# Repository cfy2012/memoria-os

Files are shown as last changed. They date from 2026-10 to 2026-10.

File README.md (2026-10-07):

# Memoria OS

**Memoria OS v1.3.0** 是一款基于 ESP32-S3（N16R8：16 MB Flash + 8 MB Octal PSRAM）自主设计的掌机操作系统。系统内核、窗口系统、文件系统、脚本引擎、BASIC 解释器与应用商店均为从零自研，不依赖 Linux、LVGL 或任何现成 UI 框架。项目以开源复古计算与嵌入式系统学习为定位，面向希望理解完整嵌入式系统栈的开发者。

## 项目定位

Memoria OS 在单颗 ESP32-S3 上实现了一台完整的手持计算设备：开机进入图标桌面，通过功能键与摇杆在十一种内置模式间切换；用户可在设备内直接编写 BASIC 程序或 `.ms` 脚本并立即运行；同时支持音频/视频/图片播放、应用商店下载安装、语音录制收发与 OTA 固件升级。

系统不使用外部操作系统，所有任务调度建立在 FreeRTOS 原语之上，所有界面绘制由自研窗口栈完成。

## 应用开发（软件的本质）

Memoria OS 上的"软件"统一为 **`.msp` 应用包**——50 字节头（魔数 MSPACK、包名、版本、CRC32）加 payload。商店只认 `.msp`，不允许裸 `.bas` / `.c` 文件直下。v1.3.0 起应用包支持 **MBND 解包安装**：包内可携带 `app.bas`（BASIC 源码）、`manifest.json`（元信息）与任意资源文件，商店安装时自动展开落盘、卸载时连带清理。

```
BASIC 源码（.bas 文本）
  → PC 端应用打包工作台（tools/msp-packer）生成 .msp
  → 上架 manifest.json（软件源清单）
  → STORE 商店安装（.msp 单文件包直接运行 / MBND 包解包落盘）
  → PRGM 模式解释运行
```

完整语法、屏幕绘图、GUI 控件与硬件扩展 API（WiFi / GPIO / 串口 / 蓝牙）见 **`docs/BASIC-LANGUAGE.md`**（Memoria BASIC 语言手册）与 **`docs/BASIC-BOOK.md`**（语言教材）。

## 功能特性

- **内置模式**：PHOTO、MUSIC、VIDEO、CLOCK、NOTES、CALC、PRGM、STORE、SETUP、FMEM、SYS 共十一种，通过 F1~F6 功能键与摇杆导航切换；桌面图标网格分页展示，最后一行下滑自动翻页。
- **键盘输入**：6×10 键矩阵，由两片 MCP23017（I2C 地址 0x20 / 0x21）扫描，支持 Shift 双层键位与拼音输入法（F1~F4 选字 / Ctrl+Shift 中英切换）。
- **GUI 控件语句（v1.3.0 新增）**：`bkey`（按钮按下）、`lbl`/`llbl`/`lbld`（标签创建/改文本/删除）、`img`（内置 16×16 图标表）、`after`（非阻塞定时跳转）、text/lbl 样式参数（正常/反白/粗体），程序内直接搭界面。
- **现场编程**：内置文本编辑器、BASIC 解释器与 `.ms` 脚本引擎，编写完成后可直接运行；`dim` 数组、文件流读写、块 if、def fn、struct/class 扩展层设计见 `docs/BASIC-OOP.md`。
- **多媒体**：WAV、MP3、M4A（AAC）解码播放，MJPG 视频解码，GB2312 中文点阵渲染；INMP441 麦克风录音 + `httpup` 语音上传、`httpdl` 流式下载（chat.bas 语音聊天已落地）。
- **解方程（v1.2.1）**：`solve` 命令支持一元一次/二次、二元/三元方程组，CALC 键盘扩展 x/y/^/,。
- **应用商店**：仅认 `.msp` 应用包，CRC 校验、断点续传、多源切换；MBND 应用包解包安装（v1.3.0）。
- **固件 OTA**：`version.json` + bin 双文件结构，经 jsdelivr CDN 分发，设备端 `ota_url` / `ota_firmware` 命令即可在线升级。
- **桌面管理**：图标移动、文件夹嵌套，布局通过 NVS 持久化。
- **无线连接**：WiFi STA 联网、BLE 串口透传；射频按需启动（boot 期零射频，系统设置或 `wifistat()` 触发），程序禁止自行联网，网络凭据由系统环境变量注入。
- **系统监控**：`sys` 命令一次看全 CPU 主频/温度/双核负载/内存/射频/电池；配套 PC 端 `talk_gui` 仪表盘监视器。

## 系统架构

系统由九个 ESP-IDF 组件与一个主程序入口构成：

| 组件 | 职责 | 关键文件 |
|---|---|---|
| `memoria_kernel` | 启动序列、模式管理、键盘扫描、拼音输入法、桌面与输入队列 | `kernel.cpp`、`mode_manager.cpp`、`ime.cpp`、`modes/` |
| `memoria_window` | 窗口栈、状态栏、GB2312 点阵字体渲染 | `window.cpp`、`gb2312_font.cpp` |
| `memoria_drivers` | 屏幕、TF 卡、音频、摇杆、电池采样、WiFi、BLE 等硬件驱动 | `ili9341.cpp`、`i2s_audio.cpp`、`sdcard.cpp`、`wifi_manager.cpp`、`include/drivers_config.hpp` |
| `memoria_fs` | 私有文件系统与 FAT 分区同步扫描 | `private_fs.cpp`、`fat_scanner.cpp` |
| `memoria_script` | `.ms` 脚本引擎（词法分析、语法分析、求值） | `src/tokenizer.cpp`、`src/parser.cpp`、`src/evaluator.cpp` |
| `memoria_basic` | BASIC 解释器 | `src/basic_interpreter.cpp` |
| `memoria_math` | 解方程求解器（一元一次/二次、方程组） | `math_solver.cpp` |
| `memoria_package` | 应用商店、`.msp`/MBND 包格式、OTA 与更新调度 | `package_manager.cpp`、`ota_updater.cpp` |
| `memoria_shell` | 交互式 Shell（REPL），全部命令真实实现 | `shell.cpp` |

主程序入口为 `main/main.cpp`，负责按固定顺序启动上述组件。自研源码共 108 个文件（53 个 .cpp 实现文件、45 个 .h/.hpp 头文件、10 个组件 CMakeLists；不含 `third_party/` 下的第三方解码库）。

## 构建指南

**环境要求**：ESP-IDF v6.1。

```powershell
# 编译
idf.py build

# 烧录并打开串口监视器（COMx 为实际串口号）
idf.py -p COMx flash monitor
```

构建基线保持全绿，编译选项启用 `-Werror`，当前零警告。v1.3.0 固件二进制约 1.84 MB（app 分区 40% 空闲）。

**v1.3.0 新增**：GUI 控件语句集（bkey / lbl / llbl / lbld / img / after / 样式参数）、store MBND 应用包解包安装、商店 .msp-only 政策、shell 错误路径误退出 panic 修复（#86）。

**v1.2.x 沿革**：BASIC v1.2 语句集（字符串变量、httpget/httpup/httpdl、record/play、wifi 托管 wifistat）、拼音输入法、系统设置网络管理页、memoria_math 解方程、RND 硬件真随机（esp_random，PC 模拟器逐位对齐）、I2C 键盘总线 panic 修复、CPU 240MHz。

**分区表**（`partitions.csv`）：

| 分区 | 用途 |
|---|---|
| `nvs` | NVS 非易失存储（配置、桌面布局） |
| `phy_init` | WiFi 射频校准数据 |
| `factory` | 出厂固件分区 |
| `ota_0` | OTA 升级固件分区 |
| `mem_fat` | FAT 数据分区（媒体、字库、脚本） |
| `mem_priv` | SPIFFS 私有数据分区 |

**编译配置**（`sdkconfig.defaults`）：纯 C++ 工程，关闭异常与 RTTI；Flash 配置为 16 MB、QIO、80 MHz；启用 8 MB Octal PSRAM（80 MHz）；BOD 欠压保护全程开启。

**TF 卡准备**：将 `sdcard/` 目录下的全部内容复制到 TF 卡根目录（FAT32）。其中 `/font/gb2312_16.bin` 为 GB2312 点阵字库（启动时读入 PSRAM，缺失时中文显示方框）、`/ime/pinyin.bin` 为拼音码表、`/scripts/` 内置 chat.bas（聊天+语音收发）等示例应用。

## OTA 固件升级

固件分发物随本仓库 `firmware/` 目录发布，经 jsdelivr CDN 可达：

- 固件 bin：`firmware/memoria_os_<版本>.bin`
- 版本清单：`firmware/version.json`（含 `version`、`url`、`changelog`、`major` 字段）

设备端升级路径：shell 执行 `ota_url <清单地址>` 设置源后 `ota_firmware` 一键升级；本地/远端版本比对取自 app_desc 版本串（`PROJECT_VER` 显式固定，不受编译时间戳污染）。

## 硬件要求

| 模块 | 规格 | 说明 |
|---|---|---|
| 核心板 | ESP32-S3 N16R8（S3-Zero 类） | 16 MB Flash + 8 MB Octal PSRAM |
| 屏幕 | ILI9488 SPI，480×320 RGB565 | 默认面板，无触摸；可在 `drivers_config.hpp` 切换为 ILI9341 320×240 |
| 键盘 | 6×10 矩阵轻触键 | 两片 MCP23017 I2C 扫描，上下各一条 WS2812 灯带 |
| 摇杆 | KY-023 | X/Y 双 ADC + 按下按键 |
| 音频 | MAX98357A + 3 W 喇叭 | I2S 输出；INMP441 数字麦克风录音 |
| 存储 | TF 卡（FAT32） | 字库、码表、音频、图片与脚本 |
| 电源 | 3.7 V 锂电 + 保护板 | TP4056 充电，ADC 分压采样电池电压 |

## 引脚分配

引脚定义的唯一数据来源为 `components/memoria_drivers/include/drivers_config.hpp`，修改硬件接线时应以该文件为准，不在其他位置硬编码 GPIO 编号。接线施工以根目录 **`WIRING.md`** 为准。

| 功能 | GPIO |
|---|---|
| SPI SCLK / MOSI / MISO | 12 / 11 / 13 |
| LCD CS / DC / RST / BLK | 10 / 9 / 8 / 14 |
| 摇杆 X / Y / BTN | 7 / 5 / 38 |
| 电池电压（ADC1_CH3） | 4 |
| TF 卡 CS | 17 |
| I2S BCLK / WS / DOUT | 18 / 21 / 15 |
| 麦克风 SD（INMP441，复用 I2S 时钟） | 16 |
| 键盘 I2C SDA / SCL（0x20 / 0x21） | 1 / 6 |
| 键盘灯带 WS2812 | 46 |
| UART0 烧录 / 控制台 | 43 / 44 |

GPIO33~37 被 Octal PSRAM 内部占用，不可使用；ADC2 与 WiFi 冲突，已禁用。

## PC 工具链

| 工具 | 说明 |
|---|---|
| `tools/msp-packer/` | 应用打包工作台（tkinter GUI）：选文件夹、填名称、选图标，一键生成 `.msp`；源码 + GitHub Release exe 双形态 |
| `tools/talk_gui.py` | 串口监视终端：六仪表实时监控（主频/温度/双核负载/内存/PSRAM/电池）+ 命令交互，语法高亮 |
| `tools/burnin_logger.py` | 42/72 小时挂测脚本：日志落盘、panic/电压异常标红、断线重连、总结报告（配套 `burnin.bat`） |
| `simulator/chat_proxy.py` | PC 模拟器聊天代理（winsock 真 HTTP） |
| `simulator/simulator.html` | 单文件浏览器模拟器，无需烧录体验主要交互 |

## 目录结构

```
memoria-os/
├── README.md
├── LICENSE
├── .gitignore
├── CMakeLists.txt
├── partitions.csv
├── sdkconfig.defaults
├── WIRING.md                   硬件接线账本（引脚变更唯一同步点）
├── components/                 固件组件（9 个，含 third_party 解码库）
│   ├── memoria_kernel/  memoria_window/  memoria_drivers/
│   ├── memoria_fs/      memoria_script/  memoria_basic/
│   ├── memoria_math/    memoria_package/ memoria_shell/
├── main/                       程序入口（app_main）
├── firmware/                   OTA 分发物（version.json + 各版本 bin）
├── docs/                       文档（见下节索引）
├── examples/                   .ms 脚本示例（demo.ms）
├── sdcard/                     TF 卡根目录内容（font/ ime/ scripts/）
├── simulator/                  浏览器模拟器 + PC 端 BASIC 解释器 + 聊天代理
├── design/                     硬件工程图纸、外壳尺寸规划与 3D 模型
├── changliao/                  chat 聊天服务端（PHP + JSON 存储，PWA 支持）
├── archive/                    历史版本源码（BASIC.cpp 单文件时代）
├── sample/                     测试媒体（mp3 / mjpg）与素材抓取脚本
└── tools/                      开发辅助工具（打包器、监视终端、挂测、字库/码表生成）
```

## 文档索引

| 文档 | 内容 |
|---|---|
| `docs/BASIC-LANGUAGE.md` | BASIC 语言手册：全语句语法、屏幕绘图、硬件扩展 API |
| `docs/BASIC-BOOK.md` | BASIC 语言教材（配套 docx 版随仓） |
| `docs/BASIC-OOP.md` | struct/class/容器扩展层设计 |
| `docs/MSP-DEPLOY.md` | 应用打包三步部署指南 |
| `docs/PROJECT-STATUS.md` | 项目当前状态快照（接手先读） |
| `docs/CONTRIBUTING.md` | 开发约定与代码规范 |
| `docs/WIRING.md` | 硬件接线账本 |
| `docs/HARDWARE-BOM.md` / `HARDWARE-DIMENSIONS.md` | 硬件采购清单 / 外壳与器件尺寸标准 |
| `docs/IME-SPEC.md` | 拼音输入法规格 |
| `docs/CHAT-PROTOCOL.md` | chat 聊天服务端协议 |
| `docs/CODE-AUDIT.md` / `docs/REGRESSION-CHECKLIST.md` | 源码审查记录 / 回归自检清单 |

## 示例与资源

- **BASIC 应用**：`sdcard/scripts/` 内置 chat.bas（文字+语音聊天）、solve.bas（解方程演示）、test_lang.bas（语句自检），拷卡后在 PRGM 模式运行。
- **`.ms` 脚本示例**：`examples/demo.ms`，复制到 TF 卡 `/mem_fat/scripts/` 后运行。
- **测试媒体**：`sample/` 提供 mp3 与 mjpg 测试文件。
- **硬件设计**：`design/` 包含主板、前面板、总装与外壳工程图纸（浏览器可直接打开）。

## 许可证

本项目以 MIT 许可证发布，详见根目录 `LICENSE`。

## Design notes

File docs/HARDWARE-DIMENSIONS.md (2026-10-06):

# Memoria OS · 硬件尺寸标准表

> 版本：2026-10-04（v10，外壳 20mm 一体壳定版：顶盖 2.5 + 壳体 17.5 内置台阶；核心板背焊；洞洞板 100×150；40.1 叠层方案作废）
> 单位：mm · 与 HARDWARE-BOM.md、drivers_config.hpp 保持一致
> 引脚唯一来源：`components/memoria_drivers/include/drivers_config.hpp`。
> 标注「以实物为准」的项：定稿前必须用卡尺实测实物覆盖，不允许只按标准值开模。

## 〇、硬性规则（不可违反）

| 规则 | 值 |
|---|-----|
| 层间隔板 | **一体壳内置台阶**（主板托台 z9~11 / 屏幕托台 z12~14；原独立隔板①②③ 方案作废，厚度已含在壳体 17.5 内） |
| 隔板/壳壁壁厚 | 上壳面板 2.5、底壳 2、侧壁 2.5、内部隔板 2（3D 打印常规） |
| 元件凸起 | 凸起元件（电容、排针等）收纳在本层内，**不得侵占隔板**（隔板只开指定的穿件孔） |
| 层顺序（屏幕面→背面） | 顶盖 2.5 → 屏幕层（托台 z12~14）→ 主板层（托台 z9~11）→ 电池/喇叭底仓 z0~9 → 壳体底；**一体壳内置台阶**（独立隔板①②③ 方案作废） |
| 洞洞板 | 100×150 标准件，**2.54mm 孔距，39×59 孔，孔径 ~1.0，板厚 1.6**，元件层净高 ≤2 |

## 一、外壳总尺寸（v10 定版：20mm 一体壳）

| 参数 | 数值 | 状态 |
|---|---|---|
| 外壳外尺寸 | **107 × 157 × 20**（顶盖 2.5 + 壳体 17.5；用户 10-03 拍板"18 加到 20"，40.1 旧方案作废） | **v10 定版** |
| 外壳内腔 | **102 × 152**（洞洞板 100×150 居中，单边 1mm 装配松量） | 定 |
| 顶盖厚度 | 2.5 | 定 |
| 底壳厚度 | 2 | 定 |
| 侧壁厚度 | 2.5 | 定 |
| 洞洞板居中偏移 | 板左缘距壳内左壁 1、板上缘距壳内上壁 1 | 定 |

> 说明：外壳 107×157×20 一体壳由"洞洞板 100×150 标准件"反推（用户拍板：好用优先、别傻大、别塞不下；原话"你这个洞洞板是 100×150，我外壳压根塞不进去"）。旧值 110×160×20、40.1 叠层、"面板 100×170" 均作废。

## 二、器件尺寸标准表（重设计输入）

> 典型值来源：市售模块通用规格。厂家差异大，务必实测。

| 器件 | 平面占位（长×宽） | 高度 | 外壳相关备注 |
|---|---|---|---|
| ESP32-S3-WROOM-1 N16R8 模组 | 18 × 25.5 | 3.1 | **已弃用**；天线端 5mm 禁金属/禁铺铜 |
| ESP32-S3 核心板（**大板 45 × 28，带底板排针，已定版**，非 S3-Zero 小核心板） | 45 × 28 | 含排针 ~5.5（排针座 2.5 + 板 1.6 + 芯片 ~1.4，待卡尺） | 带底板排针免自焊 RF；**v10：焊在洞洞板背面（背焊），模块朝底仓下凸 ~7**（见 6.4）；天线端 5mm 禁金属 |
| ILI9488 3.5″ SPI 屏模块 | PCB 91 × 56 | 6~8（含排针） | 视窗 70.8×48.5；各厂 PCB 差异大，**务必实测**；屏幕窗按实测视窗+0.5 开（约 ≥71×49）；**PCB 横装（长边沿 X）**，落位 X4.5~95.5 Y1~57 |
| 2× MCP23017（键盘扩展器，最终定版） | **DIP-28 35.5 × 7.6** ×2 | 3.2 | 主板层（洞洞板左上空白，C0~C8/R10~R13 附近）；TCA8418 采购不可得已弃用 |
| 轻触开关 6×6 矮款 ×60 | 6 × 6 | 2.5 | 轴心距 ≥9mm（指宽）；本设计键中心距 10 满足 |
| KY-023 摇杆 | PCB 26 × 34 | 板上件 ~10；**杆帽立起总高 ~32**；帽顶 Ø12 | **高度约束，见下方说明** |
| MAX98357A 功放模块 | 15.5 × 13 | 4~5 | 就近焊喇叭侧，引线短 |
| 喇叭 3W 4Ω | 23×35 或 20×30 | 厚 5~10 + 腔体 2~3 | 透音孔开在喇叭正对面 |
| TF 卡座（焊接式） | 15 × 16 | 2~3 | **内置底部，卡外露 ≥4mm** 或底壁开缝；可拆卸（字库移 TF 卡后需可拔卡）；已定为内置 |
| SD 大卡槽（**外置扩展，已定**） | 30 × 29 | 3.5 | 插卡行程 5mm，侧缝 25×2.5；**外置侧面**，用途：导照片/数据不拔底部 TF 卡 |
| TP4056 USB-C 充电模块 | 26.5 × 17.5 | 3~4 | USB-C 口凸出板边 1.5~2，侧壁开孔 10×4 |
| 锂电聚合物（505080 级，5000mAh） | 50 × 80 | 5 | 每边预留 1mm 松配；仓按实际电池复核；**市售主流 5000mAh 软包规格（50×80×5），实物标称 4500~5200 复核** |
| WS2812 灯带 60珠/m ×2 | 宽 10 | 2.5 | 每条 6 珠 ≈ 55mm，上下各一条，主板层边缘走线槽 |
| 电源拨动开关 SS12D00 | 19 × 10 | 7（含柄） | 侧壁开槽，柄行程 4mm |
| 主板洞洞板 | 100 × 150 | 1.6（板厚） | **2.54mm 孔距，39×59 孔**，元件层净高 ≤2 |

> **摇杆方案（甲案已定稿）**：KY-023 杆帽立起 32mm。20mm 一体壳下：摇杆穿顶 Ø16 贯通通道（主板/屏幕/顶盖开孔），露出量按杆帽实测复核。

## 三、前面板/侧壁开孔

| 孔位 | 尺寸 | 位置说明 |
|---|---|---|
| 屏幕窗 | ≥71 × 49（按实测视窗+0.5） | 3.5″ ILI9488 480×320（3:2） |
| 摇杆孔 | **Ø16 定版**（杆帽 Ø12 穿透，甲案贯通；旧图纸 Ø20 作废） | 面板，KY-023 甲案定版 |
| 麦克风孔 | Ø1 × 2~3 | 面板边缘，INMP441 拾音（预留 45） |
| 侧键孔（音量/电源） | 长条 ~20×3 | 侧壁 |
| USB-C 开孔 | 10 × 4 | 侧壁，充电 |
| TF 卡开孔 | 侧缝 ≥13×2，卡外露 ≥4mm | 底部，可拆卸 | 
| SD 大卡槽（外置扩展已定） | 侧缝 25×2.5 | 侧壁 |
| 电源开关槽 | 19×10，柄行程 4 | 侧壁 |
| 烧录口/排针孔 | 待定（UART 唯一烧录通道） | 侧壁或底壳，**必须预留** |
| 键盘按键孔 | **7.4 × 7.4 × 60**（键帽 7×7 + 0.4 松量；旧值 4.5×4.5 与 7×7 键帽矛盾，作废） | 前面板键盘区 |

## 四、键盘区（6×10 = 60 键，2× MCP23017 最终定版）

| 参数 | 数值 |
|---|---|
| 键盘区域总尺寸 | ~97 × 57 |
| 键帽外尺寸 | 7 × 7 |
| 键中心距 | 10（≥9 指宽下限） |
| 键孔（面板） | **7.4 × 7.4**（键帽 7×7 + 0.4 松量） |
| 键帽形式 | 内嵌式：顶面凹 2mm 指窝，不按时与面板齐平；键帽底部比面板内面再低 1mm 接触轻触键 |
| 按键行程 | 0.25mm（轻触键自带） |
| 轻触键型号 | 6×6×2.5 矮款 ×60 |
| 轻触键脚距 | ~4.45（同侧两脚）——焊洞洞板时**同侧两脚插相邻孔（2.54 间距）、外脚微弯**，常规操作 |
| 矩阵扫描 | 2× MCP23017（I2C 1/6，0x20/0x21，无 INT，20ms 轮询） |
| 键盘灯带 | WS2812 ×2，GPIO46（RMT） |

键位布局沿用旧版（R1 功能键行 / R2 数字行 / R3~R5 字母行 / R6 Shift+Caps+方向+Enter），与固件 `keyboard_keymap.hpp` 一致。

### 4.1 洞洞板孔位标准（焊板判断依据）

| 参数 | 值 |
|---|-----|
| 板尺寸 | 100 × 150（标准件，市售通用） |
| 孔距 | **2.54**（0.1″） |
| 孔数 | 39 × 59（孔 0 中心距板左/上缘 1.27；孔 n 中心 = 1.27 + n×2.54） |
| 孔径 | ~1.0（0.9~1.0，能过普通元件脚） |
| 板厚 | 1.6 |
| 坐标换算 | 洞洞板坐标 (X,Y) mm → 孔号 (round((X-1.27)/2.54), round((Y-1.27)/2.54)) |

### 4.2 洞洞板元件落孔区域（v9 统一，2026-10-02 豆包-1 × 豆包-2 对账）

> 坐标系：洞洞板左上角为原点，X 向右 0~100、Y 向下 0~150（59 孔长边为 Y）。
> 面板坐标 = 洞洞板坐标 + 3.5（板左/上缘距壳外壁 3.5 = 壁厚 2.5 + 装配松量 1）。
> **v9 说明**：v7 版 §4.2 落孔表（摇杆 X17~43/麦克 X47~63/功放 X67~82/SD Y18~47/开关 Y47~57）与洞洞板布局 HTML ⑥ 表（v8）冲突，经对账以 v8 HTML 为准，以下为统一后值（豆包-2 署名确认）。

| 元件 | 落孔区域（mm 框，洞洞板坐标） | 中心（mm） | 说明 |
|---|---|---|---|
| 键盘 60 键 | X 5~95，Y 88~148 | 键中心 X = 5+10n（n=0..9）、Y = 93+10m（m=0..5） | 6 行 × 10 列，中心距 10×10；键帽顶面 Y 89.5 起 |
| 摇杆 KY-023 | X 0~26，Y 56.5~90.5 | (14, 72.4) | 5 针 2.54 直插；上方 Ø16 贯通通道对齐面板摇杆孔 (16.5,77) |
| 麦克风 INMP441 | X 33~49，Y 56.5~72.5 | (39, 65) | 拾音面朝上，对准面板 Ø1.5×3 孔区 |
| 功放 MAX98357A | X 33~49，Y 73~88.5 | (41, 80.75) | 13×15.5；**v10 挪位**：与麦克同列（I2S 时钟共享走线短），底缘与键盘第一行键帽顶（89.5）留 1mm |
| TF 卡座 | X 67~82，Y 42~58 | (75, 49.5) | 卡插入方向朝板右缘 → 壳右壁 TF 缝 |
| SD 大卡槽 | X 65~95，Y 12~41 | (80, 27) | 30×29；卡朝板右缘 → 壳右壁 SD 缝 25×2.5 |
| TP4056 | X 12~38.5，Y 16~33.5 | (27, 22) | USB-C 口朝板左缘（壳左壁开孔 10×4） |
| 电源开关 SS12D00 | X 5~24，Y 38~48 | (14, 42) | 拨杆朝板左缘（壳左壁开槽 19×10） |
| **核心板 ESP32-S3 45×28（v10 背焊，用户 10-03 改口拍板，直插方案作废）** | X 52~97，Y 60~88 | (74.5, 74) | **焊在洞洞板背面**：排针 2×17 沿长边 X 向穿板孔（2.54 对齐），芯片/模块朝底仓下凸 ~7mm（占底仓顶，下方不摆件）；对应隔板① 开 47×30 穿件孔；USB-C 短边朝上（Y 60 侧），天线朝下避开键盘 5mm 净空（布线时定） |
| WS2812 灯带 ×2 | 不焊洞洞板 | — | 软板贴前板内面：键盘上缘（面板 Y 88~98）与键盘下缘（面板 Y 149~157），各 6 珠 |
| 2× MCP23017（DIP-28 35.5×7.6） | 板左上空白：MCP1 X0~35.5 / Y1.5~9.1、MCP2 X36~71.5 / Y1.5~9.1 | (17.75, 5.3) / (53.75, 5.3) | DIP-28 直插；不撞 SD（Y12 起）/TP4056（Y16 起）/TF（X67 起） |
| 电池 505080 | 不占洞洞板 | — | **底仓左上 X2~52 Y2~82 竖放**（长边 Y 向，避核心板背焊区与喇叭，约 5000mAh） |
| ~~ESP32 大核心板（独立小舱方案）~~ | ~~不占洞洞板平面~~ | — | **v10 作废**：改为背焊洞洞板（见上"核心板"行），顶壳舱口 47×30 取消 |

## 五、引脚与 I2C 分配（2026-10-01 迁移已执行）

### GPIO 分配（迁移后现状）

| 功能 | GPIO | 说明 |
|---|---|---|
| SPI SCLK / MOSI / MISO | 12 / 11 / 13 | 不变 |
| 屏幕 CS / DC / RST / BLK | 10 / 9 / 8 / 14 | 不变 |
| 摇杆 X / Y（已迁移） | 7（ADC1_CH6）/ 5（ADC1_CH4） | 旧 36/37 被 PSRAM 占用 |
| 摇杆 BTN | 38 | 不变 |
| 电池 ADC（已迁移） | 4（ADC1_CH3） | 旧 39 无 ADC |
| TF 卡 CS（已迁移） | 17 | 旧 5 |
| I2S BCLK / WS / DOUT（已迁移） | 18 / 21 / 15 | 旧 4/3/2 |
| 键盘灯带 | 46 | 不变（RMT） |
| 麦克风 INMP441 数据脚 | 16（现役，drivers_config.hpp） | SCK/WS 复用功放 BCLK=18/WS=21；备用独立时钟 SCK=47/WS=48（仅真机复用失败时启用）；~~45（预留）~~ 作废（45 为 strapping 脚，勿接上拉器件） |
| USB D-/D+ | 19 / 20 | OTG 占用 → UART 为唯一烧录通道 |
| UART0 TX / RX（控制台/烧录） | 43 / 44 | 默认脚 |
| 自由脚 | 39 / 40 / 41 / 42 / 47 / 48（16 已用于 MIC SD，不再列自由脚） | 可用 GPIO |
| 永久不可用 | 26~32（Flash）、33~37（Octal PSRAM） | 物理接不出 |

### I2C 分配（总线 I2C_NUM_0 @ GPIO1/6，400kHz）

| 地址 | 器件 | 状态 |
|---|---|---|
| 0x20 / 0x21 | MCP23017 ×2（行+列C0-C3 / 列C4-C9） | **最终定版**，固件现役 |
| 0x18 / 0x68 / 0x6B | 预留段（IMU/常见外设） | 登记规则：新 I2C 器件接线前先核对地址占用 |
| RTC | 无外部芯片 | S3 内部 RTC + esp_timer + NTP，不走 I2C |

> 键盘芯片结论：**2× MCP23017 最终定版**（TCA8418 采购不可得，回退至本方案）。固件现役驱动即最终方案，键盘无迁移工作。

## 六、外壳叠层核算（2026-10-04 v10：20mm 一体壳台阶方案，40.1 独立隔板方案作废）

> 权威口径：z 轴自壳体底内面（z=0）起，一体壳内置台阶（与 docs/PARTS-DIMENSIONS.md §六 同源，豆包-2 2026-10-04 复核回执）。
> 层顺序（屏幕面→背面）：顶盖 2.5 → 屏幕层 → 主板层 → 电池/喇叭底仓 → 壳体底。

### 6.1 一体壳台阶明细（z 值）

| 层 | 内容物 | z 区间 / 高度 | 依据 |
|----|---|---|---|
| 顶盖 | 壳体顶壁（中央开屏幕窗/摇杆孔/键孔） | 厚 2.5，内面 z17.5 | 用户拍板整机 20：顶盖 2.5 + 壳体 17.5 |
| 屏幕层 | ILI9488 91×56 横装（含排针 6~8） | 托台 z12~14，屏顶 z15.6（留 2 空隙） | 排针朝下嵌入托台；实测可压 6~7 |
| 主板层 | 洞洞板 100×150 + 全模块 | 托台 z9~11，主板焊面 z12.4（按键 2.5 + 板 1.6） | 洞洞板搁托台，元件收纳在托台内 |
| 底仓 | 电池 505080 厚 5 + 核心板背焊下凸 ~7 + 喇叭 | z0~9 | 电池左上 X2~52/Y2~82 竖放，与核心板落孔区（X52~97/Y60~88）平面错开；喇叭右下 |
| 壳体底 | 壳体底壁 | 厚 2 | 壁厚定值 |

### 6.2 整机厚度

- **20mm 定版**：顶盖 2.5 + 壳体 17.5（内腔台阶 z0~17.5），用户 10-03 拍板"18 加到 20"；40.1 叠层（2.5+2+8+2+11.6+2+10+2）**整批作废**。
- 区间：屏幕实测 6~7 / 喇叭厚实测 12 时台阶留空仍装得下，**卡尺 6 项到位后复核**。

### 6.3 摇杆杆帽穿透（KY-023，一体壳 20）

- 摇杆穿顶方案：主板层至顶盖开 **Ø16 贯通通道**（屏幕 PCB 91×56 横装走侧边不干涉），杆帽从顶盖 Ø16 孔露出。
- 露出量 = 杆帽总高 32 −（顶盖内面与摇杆 PCB 面高度差 + 顶盖 2.5），**按 KY-023 杆帽实测复核**（待卡尺）。

### 6.4 ESP32 形态（大核心板 45×28 已定版，模组方案弃用）

| 项 | 模组 S3-WROOM-1（3.1） | **大核心板 45×28（带底板排针，定版）** |
|----|---|---|
| 主板层高度 | — | 12.4 焊面（一体壳托台收纳，含排针 ~5.5） |
| 天线净空 | 需 5mm 禁金属 + 独立小舱 20×30 | 板端天线，周围 5mm 禁金属 |
| 焊接 | 需自焊 RF（风险高） | **免自焊，排针穿板孔焊** |
| **装配方式（用户 10-03 改口拍板：背焊）** | — | **焊在洞洞板背面**：排针 2×17 穿板孔焊（2.54 对齐），芯片/模块朝底仓下凸 ~7mm，占底仓顶（下方不摆件）；原"直插芯片朝上"方案作废 |
| 结论 | 弃用 | **定版**（落孔区 X 52~97 / Y 60~88；底仓背焊区与电池平面错开；天线端布线时定——避开键盘金属区 5mm 净空） |

### 6.5 待实测覆盖项（卡尺，6 项）

1. ILI9488 模块实际含排针高度（6~8）
2. 喇叭实际厚度 + 腔体余量（5~10 + 2~3）
3. KY-023 杆帽立起实际总高（32 为市售典型，偏差影响露出量）
4. 电池 505080 实际厚度（5）与标称容量复核（4500~5200mAh）
5. 核心板含排针实际高度（~5.5）与背焊下凸量（~7）
6. 洞洞板孔径实际值（0.9~1.0）

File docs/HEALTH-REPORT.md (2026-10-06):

# Memoria OS · 健康度与软件生态评估报告

> 生成：2026-10-06 · 评估人：豆包-2 · 数据来源：README / PROJECT-STATUS / 桥 / 代码统计 / examples
> 状态：快照评估，供项目决策参考

---

## 一、健康度总评：7.3 / 10

**架构健康 · 流程健康 · 验证滞后 · 债台不高但有四笔挂账**

| 维度 | 评分 | 依据 |
|---|---|---|
| 代码组织 | 9.0 | 8 组件各司其职；自有 ~2.3 万行，第三方解码库 ~1.6 万行（helix/minimp3/tjpgd，合理 vendor）；drivers_config.hpp 唯一引脚来源 |
| 构建稳定 | 7.0 | 编译全绿，bin 1.85MB / 3MB 分区（余 37%）；但真机三复位源未清零 |
| 文档完备 | 9.0 | 20+ 份：README/BOM/WIRING/教材 0x 化/语言手册/OOP 规划/回归清单/PERF-TUNING |
| 协作流程 | 9.0 | 桥协议 + 看板 + 三方分工 + "动共享文件先报桥"纪律 |
| 真机验证 | 4.0 | BOD 欠压 / 看门狗 / StoreProhibited panic 均未清零；模拟器全绿 ≠ 上板可用，最大短板 |
| 技术债 | 6.0 | 四笔挂账（见下） |

### 四笔技术债（按优先级）

1. **GB2312 字库 MISSING**：boot log `GB2312 font: MISSING, CJK fallback`——TF 卡未拷 `font/gb2312_16.bin`，真机中文降级。修复 = 拷卡，5 分钟。
2. **mem_fat 6MB 分区未挂载**：boot log `SDCARD: FAT mount failed: ESP_ERR_INVALID_ARG`——板载 FAT 分区定义了没挂上。
3. **安卓式电源管理未实现**：方案定版（GPIO2 长按/深睡/EXT0 唤醒），固件等窗口。
4. **SD 大卡驱动未开工**：SDMMC 39/40/41 方案已立，等窗口。

### 代码结构备忘

- memoria_window 单模块 7868 行（窗口+字库渲染）偏胖，后期可拆。
- 组件依赖清晰：kernel 调 window/drivers，package 独立，无循环依赖迹象。

---

## 二、软件生态评估：基建 80 分，内容 10 分

**结论：平台先行，内容未至——有商店没商品，有语言没作品。**

| 层 | 成熟度 | 现状 |
|----|---|---|
| 平台层 | 8/10 | .msp 包格式 + CRC + manifest 多源 + 断点续传 + OTA + 模拟器 + chat 服务器 + 串口 shell，商店基建完整 |
| 语言层 | 7/10 | BASIC 手册 + 0x 教材 + 设备端编辑器 + .ms 脚本引擎；语法批次（mod/数组/文件流/OOP）落地后 → 9 |
| 内容层 | 1/10 | 上架仅 2 个 demo（demo-script + audio-test）；设备端脚本仅 chat.bas；.m4a 测试素材缺失 |

### 生态策略：寄希望于人民，但先备好鱼塘

开源生态的正确路线 = 平台先行、内容众筹（Linux 先例）。但贡献者"慕强而来、怕麻烦而去"，须备好三样：

1. **门槛够低**：BASIC 打磨到"十分钟写第一个程序"——语法批次 + 教材 0x 化是主力，落地即够格。
2. **示例够馋**：好示例是最好的广告。把 chat.bas 包装成第一个"真应用"上架；示例从 2 个补到 ~10 个（游戏/工具/聊天）。
3. **入口够顺**：README 一条龙"怎么写应用 → 打包 → 上架 → 进商店"，别让贡献者考古。

> 现实预期：GitHub 99% 项目 0 贡献者。行动项 = 修鱼塘（开发者体验）+ 挂鱼饵（示例/视频），不是空等。

---

## 三、优先级建议（合并 PERF-TUNING 执行顺序）

| # | 事项 | 归属 | 卡点 |
|---|---|---|---|
| 1 | 真机三关：BOD / 看门狗 / panic 定位修复 | GLM（build）+ 用户（实测） | 编译窗口 + 烧录 |
| 2 | 字库拷卡落地（TF 卡 `font/gb2312_16.bin`） | 用户 | 无，5 分钟 |
| 3 | 开机电流排班（背光爬坡 / WiFi 延迟 / TF 错峰） | GLM | 编译窗口 |
| 4 | 电源管理固件 + SD 大卡驱动 | 豆包-2 认领 | 编译窗口 |
| 5 | 商店上架真应用（chat.bas 首发）+ 示例扩充 | 豆包-1/2 | 语法批次落地后 |
| 6 | PERF-TUNING P0~P4（240MHz/双核/内存分层/LCD 120/SIMD） | GLM + 豆包-2 | 编译窗口 |

---

## 附：评估数据底账

- 自有代码行数（不含 vendor/build）：kernel 3342+3990(modes) / window 7868 / drivers 2209 / basic 1240 / package 785 / script 911 / fs 439 / shell 280 / main 33 ≈ **2.3 万行**
- 第三方：helix_aac 11917 / minimp3 3085 / tjpgd 1087 ≈ **1.6 万行**
- 文档：docs/ 20 份 + README + HANDOFF + MEMORY-SNAPSHOT
- 应用：examples/app-samples（demo-script.msp）+ audio-samples（audio-test.msp）；sdcard/scripts/chat.bas

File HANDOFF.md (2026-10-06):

# HANDOFF — Memoria OS 多AI协作协议（规则层）

> 新任 GLM 必读。本文件是稳定规则，时事状态看 MEMORY-SNAPSHOT.md，最新动态看桥。

## 身份与分工
- 用户：多啦（桥长，拍板人）
- 你（GLM）：固件主线 / 源码审查 / 发布线（OTA）
- 豆包-1：外壳 / 打包 / 商店线；豆包-2：音视频 / 驱动补强线
- 署名规则：桥上发言必须标 [GLM] / [豆包-1] / [豆包-2]，只追加、不改别人条目

## 桥（AI-BRIDGE.md @ _internal/）
- 发言前必须重读（不准用缓存）；每条标注状态（通报 / 待回复 / 待拍板）
- 干活前上桥报备，改完上桥闭环（小变更改完报；大变更改前报备+改后报）
- 一次只允许一方执行 build（目录锁冲突）

## 看板（_internal/）
- ISSUE-BOARD.html：问题台账，炸/险/味三级；谁发现谁录入并桥上通报；新编号接最大号；build 全绿才算闭环
- PROJECT-BOARD.html：进度总览；改完报
- 编辑纪律：**只用编辑工具逐处改，禁用 shell 重写**（UTF-8/引号会碎）；条目只插在数据数组闭合符 `"}];` 之前，绝不能碰后面的渲染逻辑
- ISSUE-BOARD 渲染 ST 状态表合法值仅：done / wait / doing / todo / hold —— 写其他值直接白屏

## 硬约束（部分）
- 完整约束见 memory/项目记忆；高频几条：
- C 盘禁止下载/安装任何东西（软件、包、临时文件都算）
- GPIO 配置唯一来源 components/memoria_drivers/include/drivers_config.hpp；引脚改动同步 WIRING.md
- build 全绿 ≠ 完成：结报 + 看板翻状态 + 桥通报，三步缺一不可
- BASIC 官方风格：关键字全小写；注释：简短工业中文，@file + @brief
- 服务器端仅 PHP（虚拟主机），HTTP 明文可接受，部署用二级域名

## 构建与烧录
- IDF v6.1 @ D:\ESP_IDF\.espressif\v6.1\esp-idf；激活脚本 D:\Espressif\tools\Microsoft.v6.1.PowerShell_profile.ps1（dot-source）
- venv python：D:\Espressif\tools\python\v6.1\venv\Scripts\python.exe（系统 python 无 pyserial）
- idf.py stdout 常被吞（CLIXML）：错误信息落盘再 Read；编译成败看 build/ 下 bin 的 mtime + SHA
- 烧录 COM5 460800；换分区表必须 `idf.py -p COM5 -b 460800 erase_flash flash` 全片重烧
- 验收：_build/serial_snap.py（DTR/RTS 复位 + 15s 抓取 → _build/boot_snap.txt）

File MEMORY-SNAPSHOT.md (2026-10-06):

# MEMORY-SNAPSHOT — GLM 记忆快照（2026-10-06 晚固化）

> 时事状态层。配套 HANDOFF.md（规则层）。数据以桥/看板/代码为准，本文件是接手捷径。

## 权威数字
- **权威 bin：build/memoria_os.bin = 0x1E3740（1,980,224 B），SHA256 前 16 位 B8CBC2929B4B064A，版本 v1.1.2，app 分区余 36%**
- 分区表（源码 = 板上已归位）：nvs 0x9000/0x6000 · phy 0xF000/0x1000 · factory 0x10000/0x2F0000 · ota_0 0x300000/0x2F0000 · mem_fat 0x5F0000/0x620000 · mem_priv 0xC10000/0x300000（无 ota_1 / coredump）
- PROJECT-BOARD：整体 87%，真机线 30%；ISSUE-BOARD：83 条（#81/#82 done，**#83 todo**，其余 done）
- app_desc version 垃圾串 "11:22:30 Oct 4 2026"（ccache 缓存 main.cpp `__TIME__`）→ PROJECT_VER 显式 set 挂账
- shell 版本串 v1.1.2（info 命令）

## 10-06 大事记
1. **修复批次收官**（四问题，真机验收 6/6）：
   - #81 炸：SD mount 出参传 nullptr → IDF 6.1 vfs_fat_sdmmc.c L377 校验直接 INVALID_ARG，插不插卡都挂。修：`&card` 出参存 `_card` 成员 + poll 重试 quiet + 新增 reformat()
   - #82 险：shell getchar 非阻塞忙等 → memoria> 刷屏 + task_wdt。修：EOF 时 vTaskDelay(10ms)
   - 板上固件勘误：**85E09F25（v1.1.1-hotfix）从未在板上运行过**——板上旧分区表 factory 0x1E0000 装不下 0x1E3250，bootloader 静默回退 ota_0 老 bin（铁证：bin 内 banner `(type 'help')` ≠ 板上输出 `Typpe "HELP"`）。erase_flash 全片重烧归位
   - SAFE 应急模式上线：无 TF 卡 → shell 进 `safe>` 态，命令 sd mount / sd format，挂载成功自动出 SAFE
2. **桥通报**：fix4（定案+开工）→ fix5（闭环）→ fix6（虚账更正+看板补账+BLE 证据移交+OTA v1.1.2 复认催办）→ fix7（changliao 安全修复）→ fix8（#83 通报）
3. **豆包动态**：豆包-2 回归认账 L32I 定案；豆包-1+2 曾拍板推 OTA v1.1.1（85E09F25）→ 前提被勘误推翻，GLM 催复认 v1.1.2；BLE 重烧验证（豆包-2 认领）已随全片重烧顺带闭环——boot_snap.txt：`NimBLE init OK` + `advertising started` + `KERNEL: BLE: ESP_OK`
4. **changliao 安全修复**：config.php 硬编码真实面板账号密码（sec270472238666 / 密码已清）+ 部署包同带密码 + .gitignore 无防护 → 重写 config.php 为仓库版（环境变量 CL_DB_* > config.local.php 覆盖，无默认密码回退）；新增 config.local.php（真实凭据，仅本地）+ config.local.example.php 模板；.gitignore 补 changliao/server/config.local.php + changliao/dist/；部署包重打 SECRET-CLEAN 销毁旧副本

## 板上现状（B8CBC292）
- 与源码树完全归位；验收 6/6：SAFE banner / safe> 提示符 / 刷屏 0 / watchdog 0 / panic 0 / 新分区表
- SD 无卡错误 = INVALID_RESPONSE（真触卡后正常无卡错误）；**残留噪音：0x108 + `gpio: conflict found for GPIO[17]` 每 ~5s poll 刷一遍（#83 待修，不阻塞插卡测试）**
- #83 疑点：CS17 被 spi master add_device 与 sdspi cs_gpio 双重声明，或 init 失败路径未卸设备重复 add

## 挂起事项（接手先看）
1. OTA v1.1.2 推送——等豆包-1/2 桥上复认；85E09F25 不可作推送对象；推 firmware/memoria_os_1.1.2.bin + version.json→1.1.2（jsdelivr CDN），仓内保留 1.1.0
2. #83 修复（sdcard.cpp 失败清理路径 + CS17 归属二选一 + 拉长 poll 间隔）——下个 build 窗口
3. PROJECT_VER 显式 set（ccache 缓存 __TIME__），@豆包-2 可选认领，不阻塞 OTA
4. changliao 服务器重部署（用户侧：上传新 zip + 建 config.local.php；建议 easypanel 改面板密码）；api.php md5 密码迁移 salted hash 另行立项
5. 用户侧：插 TF 卡 → `sd mount` → 测 chat.bas 文字+语音（httpup/httpdl）
6. 死线：10-08 输入法落地 + 掌机语音语句 + 系统设置网络管理界面；10-08 后 BOM 18 项采购下单，~10-15 到货后焊板/全面验证/画壳

## 踩坑档案（新增，旧档案看 memory/项目记忆）
- IDF 6.1 `esp_vfs_fat_sdspi_mount` 出参不可传 nullptr——从日志永远猜不到（INVALID_ARG 看似参数错实则出参空），**要读 IDF 源码定案**
- 板上固件与源码不同步时：bin 内 banner 字符串可作指纹；"build 全绿"≠"板上运行的就是它"；换分区表必 erase_flash 全片重烧；静默回退会让历史"上板验证"结论全部失效
- C++ 前向声明 `sdmmc_card_t` 与 IDF 头定义 language linkage 冲突（extern "C" 里怎么写都撞）→ 直接 `#include "sd_protocol_types.h"`（sdmmc 组件 include 路径已在编译命令行）
- sdspi_host_init() 在 IDF 6.1 是空操作，共享 SpiBus 总线不会重复初始化，放心挂设备
- shell stdin 实际非阻塞：`getchar()` 立即返 EOF，REPL 忙等会饿死 IDLE0 触发 task_wdt
- ISSUE-BOARD 的 ST 状态表没有的值会白屏（本条即 #83 差点用 "open" 踩雷）
- PowerShell：引号路径调用要 `&`；python stdout 被吞时改写文件再 Read；PHP 本机没有，语法只能人工核对

## 文件指针
- 桥：_internal/AI-BRIDGE.md（只追加；fix4~fix8 在尾部）
- 看板：_internal/PROJECT-BOARD.html（87% / 30%）· _internal/ISSUE-BOARD.html（83 条）
- changliao：server/config.php（仓库版无密）+ server/config.local.php（真实凭据，勿入库勿外发）+ server/config.local.example.php；部署包 changliao/dist/changliao-server.zip（api.php + config.php + 模板，SECRET-CLEAN）
- 验收证据：_build/boot_snap.txt（B8CBC292 15s 快照）；验收脚本 _build/serial_snap.py；桥报脚本 _build/bridge_fix4~8.py
- chat.bas（掌机聊天 v2 语音版）：sdcard/scripts/chat.bas，L89 `httpup url$, "/mem_fat/vr.wav", r$` 为发语音上传语句

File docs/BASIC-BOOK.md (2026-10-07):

# Memoria BASIC 编程入门

> 版本：v4（全书校对版）· 2026-10-07
> v4 更新：全量通读校对——绘图章节坐标统一为真机 480×320；附录 D 补齐新 GUI 语句；彩蛋升级为编号收集制（21 个彩蛋 + 3 个彩蛋挑战，图鉴见附录 G）。
> 语法依据：《Memoria BASIC 语言手册》v1.5（docs/BASIC-LANGUAGE.md）· 解释器源码：`components/memoria_basic/`
> 用途：零基础读者在 Memoria OS 掌机上从零学会编程的教材。速查请翻语言手册，本书负责"讲会"。

---

## 前言：这本书怎么用

你好！很高兴你翻开了这本书。这本书不讲大道理，就干一件事：**让你在掌机上亲手写出自己的程序**。

**写给你的一句话**：这本书里没有"上课"两个字。你读它，就像跟一个比你早几年摸到机器的朋友聊天——他踩过的坑都标了记号，他得意的招都写在了明处。看不懂的地方跳过，卡住了回来翻，写出来的第一个"hello"哪怕只闪了一秒，也是你自己的东西。从不懂到理解，从理解到成为——这八个字，是这本书想陪你走完的路。

**写给谁**：从来没写过程序的你。不需要任何基础，会开机、会按按钮就行。

**你需要什么**：一台 Memoria OS 掌机（程序放在 TF 卡 `/mem_fat/scripts/` 目录，进 PRGM 模式运行）。暂时没有真机也没关系，先读前几章攒劲，到手就跑。

**怎么读**：
- 按顺序读。每一章都站在上一章的肩膀上，跳章容易摔。
- 每章末尾都有练习题，**一定要做**。编程是手艺活，光看不练学不会——就像看一百个游泳视频也学不会游泳。
- 练习题先看"提示"，实在卡住再看"参考答案"。参考答案保证语法正确、可以直接抄进掌机运行。
- 遇到"为什么这样不行"，先翻附录 D《已知边界》——大概率是 BASIC 里"没有的东西"。

**全书约定**：
- 所有代码关键字**全小写**（`print`、`if`、`for`……）。解释器其实不挑大小写，但小写好看，我们统一。
- 每行程序以**行号**开头。掌机编辑器会自动按 10、20、30 递增生成行号，中间还能插行。
- 本书所有例子都可以直接抄进掌机。抄代码是合法的学习方式；抄完改着玩，是更好的学习方式。
- 书里穿插**编号彩蛋**框（E01、E02……），讲点有趣的冷知识，累了就看看，当甜点。彩蛋带编号，是为了让你能"收集"：读完一章翻一眼附录 G 的图鉴，划掉一个——攒够 10 个你是学徒，18 个是工匠，**全部 21 个彩蛋 + 3 个彩蛋挑战**通关，你就是这本书的"图书管理员"。还有 3 个彩蛋挑战（C1~C3）藏在各章练习题后面，不计成绩，纯玩，但强烈建议做。

准备好了？我们开始。

---

## 开篇课：写代码之前，先装一个"程序脑"

你好！在真正动手写第一行代码之前，我想先花一章的时间，跟你聊一件**比语法更重要的事**。

我认为在学习如何编程之前，确定一个编程的思想尤为重要。语法就像笔画，思想就像笔顺——笔画谁都学得会，但笔顺不对，字永远写得又慢又乱。这一章我们不上机，就聊天。聊完你再看后面的代码，会有一种"原来如此"的感觉。

### 一、程序到底是什么：一份写给机器的菜谱

先说结论：**程序 = 数据 + 指令**。

想象你要教一个完全不通人情、但极其听话的机器人做一盘番茄炒蛋。你不能说"看着办，炒个蛋"——它会死机。你得写：

```
食材（数据）：番茄 2 个，鸡蛋 3 个，盐 5 克
步骤（指令）：
1. 打蛋
2. 切番茄
3. 热锅
4. 炒蛋，盛出
5. 炒番茄
6. 倒回鸡蛋，加盐，翻匀
```

这份东西就是"程序"。**数据是食材，指令是步骤**。计算机聪明在算得快，笨在不会自己想办法——它只做你写了的，不会做你想的。记住这句话，它能省你一半调试时间：**计算机不会猜你的心思，它只认你写的字**。

### 二、程序思维的两大流派：面向过程与面向对象

我们可以把编程的思维分成两大块：一块叫**面向过程**，一块叫**面向对象**。

**面向过程**的思路是：把一件事拆成一串步骤，一步一步做。像菜谱，像流水线，像爷爷写的操作手册。先干嘛、后干嘛，清清楚楚。

**面向对象**的思路是：把世界看成一群"小人"，每个小人（叫"对象"）有自己的记性和自己的本事。你不用管小人内部怎么干活，喊一嗓子"小王，把这个文件打印了"就行。这种思路适合做大软件，比如办公套件、游戏引擎。

那 Memoria BASIC 是哪派？——**标准的面向过程**。一个程序就是一串步骤，从第 10 行跑到最后一行，路笔直。别小看它：所有语言最终干的活都是"一步一步算"，面向对象只是管理大工程的组织术。**先用面向过程把"一步一步"练扎实，以后学任何语言都省力**——这是真话，不是安慰。

### 三、三大结构：所有程序都是三块积木

这是本章最重要的一节。1966 年，两位计算机科学家证明了一个漂亮的定理（Böhm–Jacopini 结构化定理）：**任何程序，无论多复杂，都可以只用三种结构拼出来**：

1. **顺序**：从上往下，一句一句执行。菜谱默认就是顺序。
2. **分支**：走到岔路口，看条件选路。"如果鸡蛋没了，就去买；否则直接做。"
3. **循环**：同一件事重复做。"10 个番茄，重复 10 次：切一个。"

就这三种。你以后在 BASIC 里学的 `if` 是分支，`for` 和 `while` 是循环，剩下的全是顺序。所谓"会编程"，本质就是：**会把一个大问题拆成这三种积木的搭法**。

**思想练习 1**（动脑不动手）：把"早上从起床到出门上学"拆成顺序、分支、循环三段。

> 参考答案（不唯一，合理即可）：
> - 顺序：睁眼 → 起床 → 刷牙 → 洗脸 → 背书包。
> - 分支：如果今天是工作日，穿校服；否则穿便装。
> - 循环：重复以下动作直到闹钟被按掉：按掉 → 再睡 5 分钟。（这个循环叫"死循环风险"，你妈是超时保护机制。）

### 四、变量：给数据安的"盒子"

程序里数据要放地方——放的地方叫**变量**。把它想象成贴了名字的盒子：盒子上写着 `score`，里面装着 95；老师改分了，把 95 拿出来换成 98——盒子还是那个盒子，里面的东西换了。

后面第二章我们会跟盒子们正式打交道，这里先记住一个感觉：**变量 = 名字 + 里面装的一个值**。

### 五、我们的语言：为什么有行号这种老古董

Memoria BASIC 是"经典行号 BASIC"：每行代码前面有个行号（10、20、30……），**行号决定执行顺序**。

为什么这么设计？说个冷知识：BASIC 1964 年出生在美国达特茅斯学院，两位教授（凯梅尼和库尔茨）发明它，就是为了让**每个普通学生**都能摸计算机——"Beginner's All-purpose Symbolic Instruction Code"，初学者通用符号指令代码。那个年代没有键盘没有屏幕，程序用**电传打字机**打在纸带上，改中间一行？行号就是定位的页码。所以行号不是古板的遗物，而是那个时代的"行定位器"，今天它反而成了特色：报错能精确到第几行，改哪行指哪行。

### 六、开工前检查单

- 能进 PRGM 模式吗？（程序运行的家）
- 关键字写小写了吗？
- 每行都有行号吗？行号是递增的吗？
- 记住三大结构了吗：顺序、分支、循环。

下一章，我们让屏幕开口说第一句话。

---

## 0x01 print：让屏幕说第一句话
你好！今天我们来学习真正的第一课：让掌机的屏幕显示出你想说的话。这门功夫的名字叫 `print`。

### 0x01.1 第一个程序
打开编辑器，逐行输入（行号编辑器会自动给，你只管打后面的内容）：

```basic
10 print "hello, memoria!"
20 end
```

然后运行。屏幕上会打出：

```
hello, memoria!
```

恭喜，你已经是程序员了。真不是客套——**写出指令、让机器执行、拿到结果**，这个闭环你已经跑通了。剩下的一切都是把这个循环做花样。

逐行拆解：

- 第 10 行：`print` 是"打印"的意思，把后面括住的东西显示到屏幕上。`"hello, memoria!"` 两头带引号，表示这是一段**原样显示的文字**（术语叫"字符串"）。想打什么就换什么，引号里的内容一个字都不会变。
- 第 20 行：`end` 表示程序结束。没有它程序也会跑到头自动停，但写上它是好习惯，像文章的"完"。

**注意**：引号必须是英文引号 `"`，不是中文引号“”。中文引号程序不认识。这是新手第一大坑，先给你打个预防针。

### 0x01.2 print 能打的远不止文字
数字直接打，算式也会先算后打：

```basic
10 print 1024
20 print 3 + 4
30 print "3+4="
40 print 3 + 4
50 end
```

运行结果：

```
1024
7
3+4=
7
```

看到没？第 20 行打印的不是 `3 + 4` 这五个字符，而是**算出来的 7**。不带引号，机器就把当它当算式；带引号，机器就原样照印。引号就是"照抄开关"。

### 0x01.3 分号与逗号：一句话打好几样
一个 print 想打好几样东西，用分号 `;` 或逗号 `,` 隔开：

```basic
10 print "sum="; 5050
20 print "a", "b"
30 end
```

- **分号**：让内容**紧挨着**接在一起，适合"标签+数值"连排，如 `sum=5050`。
- **逗号**：让内容**分开一段距离**，适合排成一列几样东西。

两者还能混用：`print "x="; x, "y="; y`。至于逗号具体空几格，以真机显示为准，你试一下就有数了。

### 0x01.4 一行干几件事：冒号
冒号 `:` 能把好几条语句挤在同一行，从左到右依次执行：

```basic
10 x = 1 : print x : print "done"
20 end
```

这行先做 `x = 1`，再打印 x 的值，再打印 done。冒号是"然后"的意思。**但别贪多**：一行塞太多事，自己都看不懂；一般一行干一件事，顶多两件。另外每行有长度上限 **96 字节**（约 32 个汉字），超长会写不进去。

### 0x01.5 行号的学问
三件事必须清楚：

1. **行号决定执行顺序**，跟你在编辑器里写它的先后无关。先写了 30 行再补 10 行，程序还是先跑 10 行。
2. 编辑器自动步进 +10（10、20、30……），这个"空隙"是故意留的：想在 20 和 30 之间插一句，编辑器给 25，不用全部重排。
3. 行号要**唯一**。同一行号写两次，是覆盖不是报错——这既是修改老语句的合法手法，也是手滑覆盖新代码的经典事故来源。

> **彩蛋 E01：世界上第一只 bug**
> 1947 年，哈佛 Mark II 计算机出了故障，工程师们翻箱倒柜，最后在继电器里揪出一只飞蛾。格蕾丝·霍珀（后来传奇的女将军程序员）把飞蛾用胶带贴进工作日志，写道："First actual case of bug being found."（发现 bug 的第一个真实案例。）从此程序毛病叫 bug，抓毛病叫 debug。你以后也会天天 debug——欢迎入坑，这不是你的错，是传统。

### 0x01.6 print 的兄弟：uart
还有一个 `uart "text"` 语句，样子和 print 差不多，但输出**不走屏幕，走 USB 串口**——插上电脑，在串口调试工具里能看到。它是你以后排查程序毛病的暗号专线：屏幕上看不出哪步错了，就让程序沿途往串口喊话。现在混个脸熟即可。

> **彩蛋 E14：memoria 是个拉丁词**
> 你打出的第一句话里，"memoria" 不是随手敲的——它是拉丁语"**记忆**"，Memoria OS 和 Memoria BASIC 的名字都从它来。这台掌机最初就是想做成"一台会记住东西的小机器"：记住你的程序、你的录音、你的笔记。你写进 TF 卡里的每个 .bas，都是它替你记下的一页日记。以后有人问你这系统为什么叫这名字，你可以淡淡说一句：拉丁语，记忆的意思。

### 练习题

**练习 1**（热身）：让屏幕打出你自己的英文名。

> 提示：换掉引号里的内容就行，别忘了引号。

**练习 2**：用**一个** print 语句，打出 `my age is 100`（100 换成你的真实年龄，诚重点）。

> 提示：文字带引号，数字不带，中间用分号连。

**练习 3**：只写一行程序（一个行号），用冒号连出三句 print，依次打出 `1`、`2`、`3`。

> 提示：`语句 : 语句 : 语句`。

**参考答案**：

练习 1：
```basic
10 print "duola"
20 end
```

练习 2：
```basic
10 print "my age is "; 18
20 end
```

练习 3：
```basic
10 print 1 : print 2 : print 3
20 end
```

### 本章小结

- `print` 输出到屏幕；带引号原样照印，不带引号当算式先算后印。
- 分号紧排，逗号分开排。
- 冒号 `:` 一行连多句；每行上限 96 字节。
- 行号决定顺序，编辑器 +10 步进，行号可覆盖修改（小心手滑）。
- `uart` 是往电脑串口喊话的调试专线。
- `end` 收尾，好习惯。

---

## 0x02 变量：给数据安个家
你好！上一章的程序有个毛病：它只会背台词。你说 `print "hello"` 它就 hello，改一个字都得改程序。真正的程序要能**记住东西、并且让记住的东西变来变去**——这就要请出变量了。

### 0x02.1 盒子与赋值：= 是"变成"，不是"相等"
变量就是**贴了名字的盒子**。往盒子里放东西的动作叫**赋值**，写法用等号：

```basic
10 x = 5
20 print x
30 end
```

第 10 行：拿一个盒子，贴上名字 `x`，把 5 放进去。第 20 行：打印 x——注意 x **不带引号**，所以我们打的是盒子里装的东西（5），不是"x"这个字母。

**划重点**：这里的 `=` **不是数学课的"相等"**，要读成"**变成**"。`x = 5` 读作"x 变成 5"。

为什么？看这个：

```basic
10 x = 5
20 x = x + 1
30 print x
40 end
```

第 20 行在数学课上是不成立的（x 等于 x 加 1？），但在程序里天经地义，读法是："拿出 x 里的 5，加 1 得 6，再塞回 x 盒子"。运行后打印 `6`。**盒子里的东西可以被拿出来算一算再放回去**——这个动作是编程的心跳，几乎所有程序都在反复做它。

再记住一条规则：**赋值会覆盖**。盒子里原来是 5，你 `x = 100`，5 就没了。旧值不留底。

### 0x02.2 数值盒子：小数整数都能装
装数字的变量（叫**数值变量**）内部用的是 double 类型——整数、小数都能装，精度大约 15~16 位有效数字，日常随便用。所以下面这些都合法：

```basic
10 a = 3
20 b = 3.14
30 c = a + b
40 print c
50 end
```

打印 `6.14`。

> **彩蛋 E02：为什么叫"浮点"**
> 小数在计算机里的学名是"浮点数"（floating point）：小数点的位置会"浮动"来换取大范围的表示精度。double 是"双精度浮点"，64 个二进制位精打细算分出来的。代价是：某些小数存得不是绝对精确（比如 0.1 其实是 0.1000000000000000055…），所以别用 `=` 去比较两个算出来的小数是否"相等"，那是个经典陷阱——以后你自然会踩到，先留个印象。

### 0x02.3 字符串盒子：带 $ 的变量
装文字的盒子，名字末尾要带个 `$`（美元符号，老 BASIC 用它标记"这是串"）：

```basic
10 name$ = "duola"
20 print "hi, "; name$
30 end
```

打印 `hi, duola`。

变量命名规矩：
- 字母开头，后面字母数字随便（`name$`、`score`、`x2` 都行）。
- **大小写不敏感**：`name$` 和 `NAME$` 是同一个盒子。官方风格统一**全小写**。
- 起名要见名知意。`score` 好过 `s`，`name$` 好过 `n$`——三个月后的你会感谢现在的你。

### 0x02.4 let：可有可无的开场白
老 BASIC 赋值要写 `let`：

```basic
10 let x = 5
```

我们的解释器两种都认：`let x = 5` 和 `x = 5` 完全等价。`let` 可省，直接裸赋值更简洁。看别人老程序遇到 `let` 不用慌，认得就行。

### 0x02.5 交换两个盒子：经典思维题
题目：盒子 a 装着 1，盒子 b 装着 2，请把它们对调。

```basic
10 a = 1
20 b = 2
30 a = b
40 b = a
50 print a, b
60 end
```

先自己想三秒钟再往下看——这样写对吗？

**错了**。第 30 行 `a = b` 一执行，a 里的 1 就被 2 **覆盖**了，1 彻底丢失；第 40 行 `b = a` 拿回来的还是 2。结果两个盒子都是 2。

正确做法：**再要一个盒子当中转**。好比左手啤酒、右手可乐想互换，必须先找张桌子把其中一杯放下：

```basic
10 a = 1
20 b = 2
30 t = a
40 a = b
50 b = t
60 print a, b
70 end
```

打印 `2       1`。这个"临时变量中转交换"是编程的百年老招，值得记住。

### 0x02.6 累加器：程序的记忆艺术
再看一种重要套路——**累加器**：

```basic
10 s = 0
20 s = s + 5
30 s = s + 8
40 print "sum="; s
50 end
```

s 从 0 开始，两次"自己吃自己"后变成 13。别看它土，**求和、计数、收集用户输入**，全是这个骨架。程序里最常用的十行代码，累加器占三行。

### 0x02.7 一条提前立好的铁律：串与数不混算
数字盒子和文字盒子**不能直接混合运算**。`"身高" + 180` 这种写法是不行的——BASIC 会拒绝或出错。想把数字拼进文字里，得先把数字**变成文字**（用 `str$()` 函数，0x31 正式教）。现在先立规矩：**见到 `$` 的是文字，不见 `$` 的是数字，两家来往必须"过海关"**。

### 练习题

**练习 1**：把你的年龄存进变量 `age`，打印 `i am xx years old`（xx 是变量里的值，不许硬抄数字进引号）。

> 提示：文字引号、变量裸写、分号连接。

**练习 2**：把英文名存进 `n$`，打印 `hi, xxx!`（xxx 用变量拼出来）。

> 提示：`"hi, "` 和 n$ 都是文字，文字拼文字用 `+`。两个串拼一起：`"hi, " + n$`。

**练习 3**：a=10、b=99，交换后打印。要求先打印交换前的，再打印交换后的。

> 提示：中转盒子 t。打印两个变量用逗号。

**练习 4**（体验重复之痛）：用累加器算 1+2+3 的和并打印。**不许用循环**（下一章才学），老老实实写三行加法。

> 提示：s = s + 1，然后 s = s + 2，然后 s = s + 3。写的时候感受一下：要是算 1 加到 100 呢？——这个痛苦就是下一章的引子。

**参考答案**：

练习 1：
```basic
10 age = 18
20 print "i am "; age; " years old"
30 end
```

练习 2：
```basic
10 n$ = "duola"
20 print "hi, " + n$ + "!"
30 end
```

练习 3：
```basic
10 a = 10
20 b = 99
30 print a, b
40 t = a
50 a = b
60 b = t
70 print a, b
80 end
```

练习 4：
```basic
10 s = 0
20 s = s + 1
30 s = s + 2
40 s = s + 3
50 print s
60 end
```

### 本章小结

- 变量 = 名字 + 盒子；`=` 读"变成"，会覆盖旧值。
- `x = x + 1` 是"拿出、加工、放回"，程序的心跳。
- 数字变量随便装（double）；文字变量带 `$`。
- 变量名小写、见名知意；`let` 可写可不写。
- 交换必用临时变量；累加器 s = s + i 是万能骨架。
- 串与数不混算，铁律。

下一章，我们让数字真正"干活"：运算符和一大排数学函数。

## 0x03 运算符与数学函数：让数字干活
你好！今天我们来学习让数字真正"干活"的一章。变量会装东西了，但光装不算，那盒子就是个抽屉。这一章我们给程序装上计算器，顺便认识一大排随叫随到的数学函数。

### 0x03.1 四则运算：+ - * /
加减乘除直接写，和数学课一样：

```basic
10 a = 7
20 b = 2
30 print a + b
40 print a - b
50 print a * b
60 print a / b
70 end
```

结果依次是 `9`、`5`、`14`、`3.5`。乘法用星号 `*`，除法用斜杠 `/`——键盘上就这么俩符号，习惯就好。

**优先级**也和数学课一样：先乘除、后加减，括号最优先。拿不准就加括号，多打两个字符，换一个确定无误——血赚。

```basic
10 print 2 + 3 * 4
20 print (2 + 3) * 4
30 end
```

打印 `14` 和 `20`。看到差别了吧。

### 0x03.2 比较运算：得到"真"和"假"
除了算大小，我们还要**比大小**。比较运算符六个：

| 写法 | 意思 |
|---|---|
| `=` | 等于（在 if 条件里是比较） |
| `<>` | 不等于 |
| `<` | 小于 |
| `>` | 大于 |
| `<=` | 小于等于 |
| `>=` | 大于等于 |

比较的结果是个**数值**：成立得 1（真），不成立得 0（假）。所以在 BASIC 眼里，"比较"也是一种算术。`3 > 2` 的值是 1，`3 < 2` 的值是 0。

注意 `=` 一符两用：在 `x = 5` 这种**赋值位置**是"变成"；在 `if x = 5` 这种**条件位置**是"比较等于"。语境决定身份，读程序时留个心眼。

### 0x03.3 非 0 即真：BASIC 的世界观
BASIC 判断条件只有一条天规：**非 0 即真**。0 是假，其他任何数都是真。所以 `if 5 then print "hi"` 也会打印——5 不是 0，就是真。这个设定马上会派上大用场。

### 0x03.4 并且、或者、取反：and / or / not
判断条件只有一条，经常不够用——比如"既是周一又没下雨"。**我们 BASIC 有 `and`、`or`、`not`**，照字面理解：

- **`a and b`**：**并且**。两个都真才真。一个假，整体就假。
- **`a or b`**：**或者**。一个真就真。两个都假才假。
- **`not a`**：**取反**。真的变假，假的变真。

```basic
10 a = 5
20 b = -3
30 if (a > 0) and (b > 0) then print "both positive" else print "not both"
40 end
```

打印 `not both`（b 是负数）。条件还能随便拼：`if (score >= 60) and (not absent) then print "pass"`。

两个**性子**值得记住：

- **短路**：`and` 左边为假、`or` 左边为真时，右边**根本不算**——省时省事，还能防错（比如 `if x <> 0 and 10 / x > 2`，x 是 0 时右边除法根本不会执行）。
- **真就是非 0**：`and` / `or` 的结果也是数（1 或 0），继续参与算术没问题——`x = (a > 0) and (b > 0)` 存个 1 或 0，就是布尔变量的土味写法。

> **彩蛋 E03：早期版本没有 and/or**
> 再早的 Memoria BASIC 没有这三个关键字，判断"并且"得用算术：真=1、假=0，`并且`乘起来、`或者`加起来、`取反`用 1 减——`(a > 0) * (b > 0)` 就是老写法。老程序（和本书第一版）里还能见到这种乘加逻辑，认得出、看得懂就行。

### 0x03.5 数学函数全家桶
解释器内置一排数学函数，直接写名字加括号就能用：

| 函数 | 意思 | 例子 |
|---|---|---|
| `abs(x)` | 绝对值 | `abs(-5)` → 5 |
| `sqr(x)` | 平方根 | `sqr(9)` → 3 |
| `int(x)` | 取整（朝零截断） | `int(2.9)` → 2 |
| `sin(x)` `cos(x)` `tan(x)` | 三角函数（**弧度制**） | `sin(0)` → 0 |
| `log(x)` | 自然对数 ln | `log(1)` → 0 |
| `log10(x)` | 常用对数 lg | `log10(100)` → 2 |
| `exp(x)` | e 的 x 次方 | `exp(0)` → 1 |
| `pow(a, b)` | a 的 b 次方（必须两个参数） | `pow(2, 10)` → 1024 |
| `rnd()` | 随机小数，0 到 1 之间 | 每次不一定 |
| `rnd(n)` | 1 到 n 的随机**整数**（含两端） | `rnd(6)` → 1~6 |
| `rnd(a, b)` | a 到 b 的随机**整数**（含两端，a>b 自动交换） | `rnd(1, 6)` → 1~6 |

三个使用注意：

1. **int 是截断不是四舍五入**：`int(2.9)` 得 2，`int(2.1)` 也得 2，`int(-2.1)` 得 -2——直接砍掉小数部分，朝零取整。想四舍五入？土办法：`int(x + 0.5)`（正数适用）。
2. **三角函数用弧度**：`sin(30)` 不是 30 度！30 度要换算成弧度：`30 * 3.14159 / 180`。数学课的 π=180°，别忘。
3. **幂运算写 `pow(a, b)`**：不支持 `^` 符号。2 的 10 次方写 `pow(2, 10)`。

> **彩蛋 E04：机器不会掷骰子，但芯片会**
> `rnd()` 的"随机"是**真随机**：芯片里藏着一个硬件熵源，直接抓电路的热噪声当随机数（esp_random）——没有种子、没有公式，每次开机序列都不一样，连系统自己都猜不到下一个数。老式计算机没有这硬件，只能"伪随机"（按固定公式算），所以老程序员才说"计算机不会掷骰子"——你这台掌机是真的会。

### 0x03.6 随机数的正确打开方式
掷骰子直接掷，不用加工：

```basic
10 r = rnd(1, 6)
20 print r
30 end
```

`rnd(a, b)` 一步到位：从 a 到 b 选一个**整数**，两端都算（`rnd(1, 6)` 能掷出 1，也能掷出 6）。三个参数版本都好记：`rnd()` 是 0~1 小数（要小数时用）；`rnd(n)` 是 1~n；`rnd(a, b)` 是 a~b——范围随便写，`rnd(0, 99)` 从 0 开始也行，a 比 b 大也会自动交换。老版本只有 `rnd()` 0~1，掷骰子得三步加工 `int(rnd() * 6) + 1`，老程序里还见得到这配方；新代码直接 `rnd(1, 6)`。0x81 猜数字游戏用 `rnd(1, 100)`。

### 0x03.7 实战：一个小计算器
把本章的活儿串一串：

```basic
10 a = 3
20 b = 4
30 c = sqr(a * a + b * b)
40 print "hypotenuse="; c
50 end
```

这是勾股定理：两条直角边 3、4，斜边算出来 5。`a * a + b * b` 是"3²+4²"，开方得 5。看到了吗——**一行程序能装下一整个数学公式**，变量就是公式里的字母。

### 练习题

**练习 1**：输入华氏温度变量 f = 100，换算成摄氏度打印。公式：摄氏 = (华氏 - 32) * 5 / 9。

> 提示：一行赋值搞定换算，再 print。

**练习 2**：直角三角形两直角边 a=5、b=12，打印斜边长。

> 提示：照抄 3.7 的配方，换数字。

**练习 3**：掷 6 次骰子并打印 6 个点数。**不许用循环**（下一章才学），写 6 行。

> 提示：`rnd(1, 6)` 复制六遍。再体会一次"重复之痛"——这已经是第三次了，下一章终结它。

**练习 4**：变量 a=8、b=-2、c=3。用一行 if 判断"三个数是否**全为正**"，全正打印 `all positive`，否则打印 `no`。

> 提示：`(a > 0) and (b > 0) and (c > 0)`。

**参考答案**：

练习 1：
```basic
10 f = 100
20 c = (f - 32) * 5 / 9
30 print c
40 end
```

练习 2：
```basic
10 a = 5
20 b = 12
30 c = sqr(a * a + b * b)
40 print c
50 end
```

练习 3：
```basic
10 print rnd(1, 6)
20 print rnd(1, 6)
30 print rnd(1, 6)
40 print rnd(1, 6)
50 print rnd(1, 6)
60 print rnd(1, 6)
70 end
```

练习 4：
```basic
10 a = 8
20 b = -2
30 c = 3
40 if (a > 0) and (b > 0) and (c > 0) then print "all positive" else print "no"
50 end
```

### 本章小结

- 四则 `+ - * /`；先乘除后加减，拿不准加括号。
- 比较结果是数：真 1 假 0；`=` 在条件位置是"比较"。
- **非 0 即真**是唯一天规。
- 并且/或者/取反：`and`、`or`、`not` 关键字（短路；结果也是数 1/0）。
- `int` 截断取整；三角用弧度；幂用 `pow`。
- 随机整数：`rnd(1, 6)` 一步到位（`rnd(n)` = 1~n，`rnd(a, b)` = a~b，都含两端）。

---

## 0x11 input：程序开口问
你好！到今天为止，我们的程序都是"自说自话"：所有数据写死在代码里。今天我们让程序**开口向用户要数据**——交互，是"程序"和"算式"的分水岭。

### 0x11.1 input x：摇杆调一个数
```basic
10 print "set your number"
20 input x
30 print "you set "; x
40 end
```

运行到第 20 行，程序**停下来等你**。调数值用摇杆：

- **上/下**：±1（一个一个挪）
- **左/右**：±10（十个十个跳）
- **按下**：确认，程序继续跑

为什么这么设计？掌机上没有完整键盘（有键盘区的机型，键盘另有重用），摇杆是随身可靠的"旋钮"。想输入 87：右 8 次、下 3 次，按下收工。

程序恢复后，你确认的数就装进了 x 盒子，第 30 行照常打印。

### 0x11.2 input a$：键盘打一行字
要输入文字，用**带 $ 的变量**接：

```basic
10 print "what is your name?"
20 input n$
30 print "hi, "; n$
40 end
```

运行到 20 行，屏幕出现录入框：**英文直接敲，中文自动调起拼音输入法**（方向键选字、Enter 上屏），按 Enter 确认。中文英文都能收——`input a$` 可以收中文名、中文句子，这是 chat 之类中文程序的入口。

### 0x11.3 问完必须"接住"
input 后面必须跟一个变量——它是"接球的手套"。`input x` 接数，`input a$` 接文字。接错手套类型会出乱子，数就给数盒子，文字给串盒子。

### 0x11.4 实战：电子门牌
```basic
10 print "what is your name?"
20 input n$
30 print "how old are you?"
40 input age
50 print "hi "; n$; ", age "; age
60 print "next year: "; age + 1
70 end
```

先问名字（串），再问年龄（数），最后连报带算。注意第 60 行：print 里可以直接放**算式** `age + 1`，先算后印。交互+计算+输出，一个完整小应用诞生了。

> **彩蛋 E05：对话是程序的专利**
> 1966 年，世界上最早的聊天程序 ELIZA 诞生，它只会把你说的话换个花样反问你（你说"我难过"，它问"为什么难过"），却让无数人以为它懂自己——心理学界都惊动了。今天你学的 input + print，正是 ELIZA 的全部骨架：问一句、接住、加工、反问。0x83 完我们真做一个。

### 练习题

**练习 1**：让用户摇杆输入两个数 a 和 b，打印它们的和、差、积。

> 提示：两次 input，三次 print（print 里直接写算式）。

**练习 2**：问用户名字，然后打出三行问候：`hi, xxx`、`welcome, xxx`、`bye, xxx`（xxx 是用户输入的名字）。

> 提示：名字接进 n$，用分号拼。串拼串也可以用 `+`。

**练习 3**：问用户"圆的半径是多少"，摇杆输入半径 r，打印圆面积（3.14159 * r * r）和周长（2 * 3.14159 * r）。

> 提示：0x03 公式 + 本章 input，合体技。

**参考答案**：

练习 1：
```basic
10 print "number a?"
20 input a
30 print "number b?"
40 input b
50 print "sum="; a + b
60 print "diff="; a - b
70 print "prod="; a * b
80 end
```

练习 2：
```basic
10 print "your name?"
20 input n$
30 print "hi, " + n$
40 print "welcome, " + n$
50 print "bye, " + n$
60 end
```

练习 3：
```basic
10 print "radius?"
20 input r
30 print "area="; 3.14159 * r * r
40 print "circum="; 2 * 3.14159 * r
50 end
```

### 本章小结

- `input x`：摇杆调数（上下 ±1、左右 ±10、按下确认）。
- `input a$`：键盘输入，Enter 确认；**中文自动调起拼音输入法**（规格见 `docs/IME-SPEC.md`）。
- input 必须用变量"接住"输入。
- print 里可以直接放算式。
- input 是程序与用户对话的起点：问、接、算、答。

程序会对话了，但还不会"看情况办事"。下一章 `if`，给程序装上判断力。

---

## 0x12 if：程序的岔路口
你好！今天我们来学习三大结构的第二块：**分支**。开篇课说过，任何程序都是顺序、分支、循环搭的——今天拿下分支，三大结构就集齐两块了。

### 0x12.1 最简单的 if：满足才做
```basic
10 x = 5
20 if x > 3 then print "big"
30 print "done"
40 end
```

第 20 行读作："如果 x 大于 3，**那么**打印 big"。x 是 5，条件成立，打印 big；接着 30 行照常执行，打印 done。

把第 10 行改成 `x = 1` 再跑：条件不成立，20 行的 print **整句跳过**，直接打印 done。这就是分支——**条件说了算，不成立就当没看见**。

语法骨架：

```
if 条件 then 语句
```

条件就是0x03 的比较运算（`x > 3`、`a$ = "tom"`），或者任何"非 0 即真"的表达式。

### 0x12.2 else：另一条路
两头都安排上：

```basic
10 x = 1
20 if x > 3 then print "big" else print "small"
30 end
```

条件成立走 then 后面，不成立走 else 后面，**两条路必走其一，也只走其一**。

### 0x12.3 大规矩：if 独占一整行
if 是个"一行人士"：**整条 if 必须写在一行内**，不能用冒号拖到下一行去。但 then 和 else 的身体里，**可以**用冒号装多条语句：

```basic
10 score = 75
20 if score >= 60 then print "pass" : print "nice" else print "fail" : print "work hard"
30 end
```

成立就连续打印 pass、nice；不成立连续打印 fail、work hard。不过劝你克制：一行塞四件事已经到舒适上限了。再多，就该用0x51 的 gosub 把活儿搬进"抽屉"。

### 0x12.4 隐藏招式：then 后面跟纯数字 = 跳转
这是老 BASIC 的传统艺能：

```basic
10 x = 0
20 if x = 0 then 100
30 print "not zero"
40 end
100 print "zero!"
110 end
```

第 20 行的 then 后面是个**纯数字 100**——意思不是打印 100，而是**跳到行号 100 去执行**（等于隐形的 goto）。x 等于 0，程序直接飞到 100 行打印 zero!，30、40 行根本没跑。

什么时候好用？条件满足时"翻页"去另一段流程。注意目标行号必须真实存在，跳去一行不存在的代码是新手高频事故。

### 0x12.5 组合条件与多层岔路
复习0x03 的 and/or。多层岔路（比如成绩分等级）用 if 连环：

```basic
10 score = 85
20 if score >= 90 then print "A"
30 if score >= 60 then if score < 90 then print "B"
40 if score < 60 then print "C"
50 end
```

第 30 行是"if 套 if"：先看是否 ≥60，是的话再看是否 <90——两关都过才打印 B。（我们的一行 if 装不下 else if 这种写法，连环 if 是标准替代。）想更清爽也可以倒着排：先判最高档，命中就跳走（then 数字），后面的 if 自然不再命中——这招0x81 综合项目会用。

### 0x12.6 字符串也能比
if 里比文字完全合法，规则是：**条件两侧只要有一边是串（串变量或带引号的串），就按字符串比较**：

```basic
10 print "password?"
20 input p$
30 if p$ = "open" then print "welcome" else print "denied"
40 end
```

等于 `=`、不等于 `<>` 最常用。`> <` 也能用，按**字节序**比——即逐个字符比编码大小。这带来两个冷知识：

- 大写字母排在小写字母**前面**（A 的编码 65，a 是 97），所以 `"Apple" < "apple"` 成立。
- 比较从第一个字符开始逐位比，像查字典排音序。

### 0x12.7 mod：奇偶判断不用自己造
判断奇偶要"除以 2 取余数"——**BASIC 有取余运算符 `mod`**，直接写：

```basic
10 x = 7
20 if x mod 2 = 1 then print "odd" else print "even"
30 end
```

`x mod 2` 就是"x 除以 2 的余数"：7 mod 2 = 1 → odd。`mod` 跟 `*`、`/` 同一优先级（先于加减），正数取余随被除数符号：`-7 mod 3` 得 -1。两个注意：`mod` 和它俩一样**除 0 会报错**；早期版本没有 mod，老程序用 `x - int(x / n) * n` 自己造余数，认得就行。

> **彩蛋 E06：AI 会作弊**
> 1997 年深蓝战胜国际象棋世界冠军卡斯帕罗夫。老卡赛后坚称第九局有一步"太有人味"，一定是人类棋手 intervenes——其实那正是纯机器走的一步。if 分支堆得足够多、足够巧，程序的行为会"像"有智慧。你写的每个 if 都在给程序的"人格"添砖——将来你的掌机程序什么脾气，全看你怎么写分支。

### 练习题

**练习 1**：摇杆输入一个数，打印它是正数、负数还是零（三种结果）。

> 提示：三条 if 排队：>0、<0、=0，各配各的 print。

**练习 2**：摇杆输入两个数，打印**较大**的那个（如果相等，打印其中任意一个都行）。

> 提示：if a > b then 打 a else 打 b。一行搞定。

**练习 3**（密码门加强版）：问用户暗号，暗号是 `sesame` 打 `open`; 否则打 `wrong`，并且**只有暗号正确时**才追加打一行 `treasure is yours`。

> 提示：then 体内可以冒号连两句。

**练习 4**（跳转招式）：x = 5。如果 x 不等于 0，跳到 100 行打印 `got value` 后结束；等于 0 就原地打印 `zero` 再结束。要求用到 "then 数字" 跳转。

> 提示：if x <> 0 then 100。100 行写 print 和 end。

**参考答案**：

练习 1：
```basic
10 print "input a number"
20 input x
30 if x > 0 then print "positive"
40 if x < 0 then print "negative"
50 if x = 0 then print "zero"
60 end
```

练习 2：
```basic
10 print "a?"
20 input a
30 print "b?"
40 input b
50 if a > b then print a else print b
60 end
```

练习 3：
```basic
10 print "password?"
20 input p$
30 if p$ = "sesame" then print "open" : print "treasure is yours" else print "wrong"
40 end
```

练习 4：
```basic
10 x = 5
20 if x <> 0 then 100
30 print "zero"
40 end
100 print "got value"
110 end
```

### 本章小结

- `if 条件 then 语句 else 语句`；成立走 then，不成立走 else，必走其一。
- **if 独占一行**；then/else 体内可冒号连多句。
- then 后跟纯数字 = 跳转到该行号（目标行必须存在）。
- 组合条件用 and/or；多层岔路用连环 if。
- 串比较：有一边是串就按串比，`> <` 按字节序（大写在前）。
- mod：`x mod n` 直接取余（与乘除同级，除 0 报错）。

三大结构还差最后一块：循环。下一章 `for`，终结"重复之痛"。

## 0x21 for：知道次数的重复
你好！今天我们来学习三大结构的最后一块：**循环**。前几章你已经三次体验"复制粘贴同一段代码"的痛苦了——今天，痛苦终结。知道要重复多少次的时候，用 `for`。

### 0x21.1 语法：for ... next
```basic
10 for i = 1 to 5
20   print "round "; i
30 next i
40 end
```

运行结果：

```
round 1
round 2
round 3
round 4
round 5
```

逐块拆解：

- `for i = 1 to 5`：开一个循环。`i` 叫**循环变量**，从 1 数到 5，每圈数一次。
- 中间的行（20 行）叫**循环体**，每圈执行一遍。
- `next i`：一圈结束，i 加 1，回到 for 检查——没数到头就再来一圈，数到头就出循环。

三行骨架干成了你之前复制六行干的事。**这就是循环的力量：一次写好，N 次享用。**

> **彩蛋 E07：为什么循环变量都叫 i**
> i 是 index（索引）或 iteration（迭代）的首字母。从 1957 年的 FORTRAN 起，`i, j, k` 就是循环变量的"默认工号"——数学家早先也给求和下标记 i。所以全世界的程序员看到 `for i` 都会心一笑：老熟人了。如果一层循环不够用，第二层就轮到 j，第三层 k。

### 0x21.2 step：不按 1 数
`to` 后面还能跟 `step`，指定每圈加多少：

```basic
10 for i = 2 to 10 step 2
20   print i
30 next i
40 end
```

打印 `2 4 6 8 10`——从 2 数到 10，每步 +2。step 2 就是"隔一个数一个"。想数偶数、倍数、单号，step 一句话的事。

**step 省略时默认为 1**。本书示例只保证正步长写法；想"倒着数"（10 数到 1），用下一章的 while 更稳妥。

另外提醒：循环变量 i 就是个普通变量，循环体里可以用它（第 20 行的 `print i` 就在用），甚至能改它——但改了会扰乱计数，新手期别碰。

### 0x21.3 缩进：给谁看的
注意上面例子 20 行前面空了两格。**BASIC 根本不看缩进**——它只认行号。缩进是写给人看的：循环体往里缩一格，一眼看出"这几行是循环里面的"。书上的例子保持这个习惯，你写大程序也保持，纯赚不亏。

### 0x21.4 嵌套：循环套循环
循环体里再开一个循环，叫**嵌套**。经典案例——九九乘法表的核心：

```basic
10 for i = 1 to 3
20   for j = 1 to 3
30     print i; "x"; j; "="; i * j
40   next j
50 next i
60 end
```

跑起来：i=1 时，j 把 1、2、3 走一圈；然后 i=2，j 再走一圈……外层走 1 圈，内层走满 3 圈，共 9 行输出。**嵌套的本质是"对每一种组合都干一遍"**——外层是行，内层是列，铺满整个棋盘。

配套规矩：里外层的 next 要按"先进后出"配对——内层 `next j` 在前，外层 `next i` 在后，别交叉。

### 0x21.5 实战一：1 加到 100
```basic
10 s = 0
20 for i = 1 to 100
30   s = s + i
40 next i
50 print "sum="; s
60 end
```

打印 `sum=5050`。累加器 + 循环，这是编程界第一对黄金搭档。

> **彩蛋 E08：高斯的快捷方式**
> 传说数学家高斯小学时被罚算 1 加到 100，别的人埋头苦加，他几秒钟写出答案 5050：首尾配对，1+100、2+99、3+98……每对都是 101，共 50 对，101×50=5050。循环替你"苦加"，公式替你"取巧"——两者都会，你既像工程师又像数学家。

### 0x21.6 实战二：文字进度条
循环还能攒字符串（攒串的完整原理0x31 细讲，先看着玩）：

```basic
10 bar$ = ""
20 for i = 1 to 10
30   bar$ = bar$ + "#"
40   print bar$
50 next i
60 end
```

每圈往 bar$ 后面追加一个 `#`，屏幕上打出 1 个 #、2 个 #……10 个 #，像一根进度条逐格长满。**循环 + 累加**，连文字都能"生长"。

### 练习题

**练习 1**：打印 1 到 10 每个数的平方（1、4、9……100）。

> 提示：for i = 1 to 10，print 里写 i * i。

**练习 2**：计算 5!（阶乘：1×2×3×4×5 = 120）并打印。

> 提示：把累加器的 `+` 换成 `*`，s 从 1 开始（别从 0 开始——0 乘什么都 0，经典事故）。

**练习 3**：打印 7 的 1 倍到 5 倍（7、14、21、28、35）。要求用 step 一步到位。

> 提示：for i = 7 to 35 step 7。

**练习 4**：先摇杆输入 n（0x11 input），再计算 1+2+…+n 的和并打印。

> 提示：for 的 to 后面可以放变量：for i = 1 to n。程序先 input 后 for。

**参考答案**：

练习 1：
```basic
10 for i = 1 to 10
20   print i * i
30 next i
40 end
```

练习 2：
```basic
10 s = 1
20 for i = 1 to 5
30   s = s * i
40 next i
50 print s
60 end
```

练习 3：
```basic
10 for i = 7 to 35 step 7
20   print i
30 next i
40 end
```

练习 4：
```basic
10 print "n?"
20 input n
30 s = 0
40 for i = 1 to n
50   s = s + i
60 next i
70 print "sum="; s
80 end
```

### 本章小结

- `for i = a to b step c` ... `next i`：知道圈数的重复。
- step 省略默认 1；循环体缩进是给人看的。
- 嵌套 = 穷举所有组合；next 配对先进后出。
- 累加器 + 循环 = 黄金搭档；乘法累加从 1 起（别从 0）。
- to 后面可以放变量。

---

## 0x22 while：不知道次数的重复
你好！上一章的 `for` 有个前提：你得**先知道圈数**。可现实中很多重复事先数不出来——"吃到饱为止""连上 WiFi 为止""猜中为止"。这种"看情况"的循环，用 `while`。

### 0x22.1 语法：while ... wend
```basic
10 x = 1
20 while x < 100
30   print x
40   x = x * 2
50 wend
60 print "end, x="; x
70 end
```

运行结果：

```
1
2
4
8
16
32
64
end, x=128
```

逐块拆解：

- `while x < 100`：每圈开头**先检查**条件。成立就进循环体，不成立就跳到 wend 之后。
- 循环体里 `x = x * 2` 每圈翻倍——**必须有人推动条件变化**。
- `wend`（while end 的缩写）：循环体的终点，跳回 while 再检查。

第 60 行打印的 x 是 128：最后一次检查时 x 已是 128，不小于 100，循环退出。看懂这个 128，你就看懂了 while 的检查时机。

**while 的灵魂一句话：循环体里必须干点让条件"趋向结束"的事**（本例是 x 翻倍），否则条件永远成立——那就是死循环了。

### 0x22.2 for 还是 while？一道选择题
- **知道圈数**（10 次、100 个、嵌套铺格）→ `for`
- **不知道圈数**（等连接、等猜中、翻倍到某数）→ `while`

拿不准就问自己："圈数写死在 to 后面合理吗？"合理用 for，不合理用 while。两者还能互换着写，但各干各的活最顺手。

### 0x22.3 死循环与保险丝：超时保护
`while 1` 是恒真条件（非 0 即真），写出这种程序就**永远转下去**：

```basic
10 while 1
20   print "tick"
30 wend
```

别慌——系统给你上了保险丝：**每个程序最多执行 100000 步，超限强制终止**，屏幕报"超时保护"。所以最坏情况也不是死机，是程序被"拔电"。上面这个程序打一阵 tick 后就会被收走。

保险丝是保命的，不是用来依赖的：**发布给别人用的程序，循环条件必须能正常结束**。你私自玩 `while 1` 没事，上架程序靠保险丝收尾会被用户骂。

> **彩蛋 E09：电磁炉同款设计**
> 超时保护和电磁炉"干烧断电"是同一种工程哲学：不听话宁可停机，也不烧锅。你以后设计任何"会自动跑的东西"（程序、机器人、闹钟），都要问一句：它卡住了，谁拉闸？

### 0x22.4 实战：翻倍超过 1000
```basic
10 x = 1
20 while x <= 1000
30   x = x * 2
40 wend
50 print x
60 end
```

打印 `1024`。1、2、4……一路翻到第一个超过 1000 的数。这个"**直到超过某值才停**"的结构，while 一眼写出来，for 反而费劲——体会到了吧。

### 0x22.5 实战：带超时的等 WiFi
联网程序第一步是等 WiFi 连上——这活儿天生 while（不知道几秒连上）。但直接写 `while wifistat() = 0 : wend` 有隐患：万一 WiFi 永远连不上，循环就靠保险丝收场，很丢人。职业写法是**自己带计数超时**（WiFi 由系统设置连好，程序只等状态变 1）：

```basic
10 t = 0
20 while wifistat() = 0
30   t = t + 1
40   if t > 50000 then print "wifi timeout, 去系统设置连网" : end
50 wend
60 print "wifi ok"
70 end
```

每空转一圈 t 加 1，t 超过 5 万次（大约几秒）就主动放弃。**"等，但给等待设个死线"**——这是所有联网程序的标准开场，0x61 、0x83 都直接搬它。记住骨架：计数变量 + 循环里加一 + 超线就撤。

### 练习题

**练习 1**：用 while 倒数打印 10、9、8……1，最后打印 `launch!`。

> 提示：i 从 10 起，循环里 print、减 1，条件 i >= 1。倒计时结束了再打印。

**练习 2**：1+2+3+…，加到**和第一次超过 500** 为止，打印加到了第几个数、和是多少。

> 提示：两个变量：s 攒和、i 数个数；while s <= 500；循环里 i 加一、s 加 i。循环后 s、i 各是什么？动笔模拟两圈就明白。

**练习 3**：打印 1~20 中所有**不是 5 的倍数**的数（用 while + 0x12 的自造余数）。

> 提示：`i mod 5 <> 0` 才打印（0x12.7 的 mod）。

**参考答案**：

练习 1：
```basic
10 i = 10
20 while i >= 1
30   print i
40   i = i - 1
50 wend
60 print "launch!"
70 end
```

练习 2：
```basic
10 s = 0
20 i = 0
30 while s <= 500
40   i = i + 1
50   s = s + i
60 wend
70 print "n="; i
80 print "sum="; s
90 end
```

（跑完 n=32、sum=528。32 个数加起来首次破 500。）

练习 3：
```basic
10 i = 1
20 while i <= 20
30   if i mod 5 <> 0 then print i
40   i = i + 1
50 wend
60 end
```

### 本章小结

- `while 条件 ... wend`：先检查后执行，不知道圈数的循环。
- 循环体必须推动条件变化，否则死循环。
- `while 1` 恒真；系统有 100000 步超时保护保命，但正式程序要能自己结束。
- 等待类任务标配：计数超时（t 加一，超线就撤）。
- 圈数已知用 for，圈数看情况用 while。

---

## 0x31 字符串：文字的加工厂
你好！今天我们来学习字符串的专题课。前面已经会存串、拼串了，今天上全套设备：量长度、切片子、数变文、文变数，还要解决一个高级问题——**怎么用一串文字携带一整队数据**（新固件有数组了，但"串当背包"在网络场景仍是基本功）。

### 0x31.1 拼接与铁律复习
串与串用 `+` 拼接；**串与数不混算**（铁律0x02 立的）：

```basic
10 name$ = "memoria"
20 msg$ = "hello, " + name$ + "!"
30 print msg$
40 print "version " + str$(2)
50 end
```

第 40 行：数字 2 想拼进文字，先过海关——`str$(2)` 把数字变成串 `"2"`。**str$ 是"数字→文字"的签证处**。

### 0x31.2 val：回程船票
反方向，`val(s$)` 把文字变回数字：

```basic
10 a$ = "123"
20 x = val(a$) + 1
30 print x
40 end
```

打印 `124`。没 val 的话，"123" 只是一串字符，不能拿来算。

一个贴心设定：val 遇到**不是数字的串，返回 0，不报错**。`val("abc")` 得 0。程序不会炸，但你要知道 0 可能是"没转出来"，别把它当真数据。

这俩函数在哪最有用？**网络**。服务器发回来的响应体 r$ 是文字，里面的数字要算术就得 val——0x61 HTTP 客户端见真章。

### 0x31.3 len：量长度（按字符量）
`len(s$)` 返回串的长度——**按字符量，汉字算 1 个字符**：

```basic
10 print len("abc")
20 print len("好")
30 end
```

打印 `3` 和 `1`。**按字符量**——中文一个汉字算 1 个字符，跟"人眼数出来的字数"一致。老版本按字节量（1 汉字 = UTF-8 3 字节），新固件已改为按字符，写程序不用再数 3 的倍数。

实用推论：**每行程序上限 96 字节**（约 32 个汉字，按字节上限），print 打 10 个汉字没问题。

### 0x31.4 切片三兄弟：left$ / right$ / mid$
从一串文字里切出一部分：

| 函数 | 意思 | 例子 |
|---|---|---|
| `left$(s$, n)` | 从**左**取 n **字符** | `left$("hello", 2)` → `"he"` |
| `right$(s$, n)` | 从**右**取 n **字符** | `right$("hello", 2)` → `"lo"` |
| `mid$(s$, start, len)` | 从第 start **字符**起取 len 字符 | `mid$("hello", 2, 3)` → `"ell"` |

特别注意 `mid$` 的 start **从 1 数起**——人从 1 开始数数，这次机器顺着你。三个函数都按**字符**切，跟 len 一个口径：汉字算 1 个字符，随便掐，绝不会切出半个字的乱码。老版本按字节切（1 汉字 = 3 字节，得按 3 的倍数掐），新固件已改按字符。

切片最常用的场景：**检查开头**。比如验证文件名是不是 `img` 打头：`if left$(name$, 3) = "img" then ...`。

### 0x31.5 chr$：数字变一个字符
`chr$(n)` 把 0~255 的数字变成对应的单字节字符：

```basic
10 print chr$(65)
20 print chr$(97)
30 print chr$(48)
40 end
```

打印 `A`、`a`、`0`。数字和字符的对照表叫 ASCII 码，几个常用号背下来有好处：**65=A，97=a，48=0，32=空格**。大写和小写差 32（65 和 97），这个"差 32"是老牌程序员的肌肉记忆。

> **彩蛋 E10：ASCII 是 1963 年的老古董**
> ASCII（美国信息交换标准代码）1963 年定稿，安排编码时 engineers 把 "a" 定为 97、"A" 定为 65——中间空出 32 个号给标点。为什么大小写差 32？据说当年想让"大小写互换"能用一个开关位实现（65+32=97，二进制只差一位）。一个 60 多年前的设计决定，你今天在 BASIC 里按 chr$ 还在受益。另外注意：我们的工具箱里只有 chr$（数字变字符），没有反向的"字符变数字"函数——所以那张对照表，值得背。

### 0x31.6 数组（新固件）与串当背包
新固件里 BASIC 有**数组**了：`dim a(100)` 声明一个能装 101 个数的数组（下标 0~100），`a(3) = 99` 存取，还能 `dim a$(20)` 装文字、`dim m(10, 10)` 开二维网格。完整语法见《Memoria BASIC 语言手册》（BASIC-LANGUAGE.md），本书不展开。

那为什么还要学"串当背包"？两个原因：一是你的掌机可能还在跑旧固件（没有 dim），读老程序也常遇到这招；二是"一串带分隔符的数据"（csv 之类）在网络上到处都是，打包、传输、解析都离不开它。所以这招照学，不吃亏：**把一串数据装进一个字符串，用分隔符隔开**，像背包里塞一排口袋：

```basic
10 bag$ = "apple,banana,pear"
```

三个水果名，逗号隔开。要取第 2 个？——先自己造一个"查找器"，这正好是本章压轴实战。

> **彩蛋 E15：这招为什么叫"背包"**
> "串当背包"不是比喻，它是有出处的：编程圈里管"用一个字符串塞多份数据"叫 *string packing*（串打包），跟旅行收拾行李一个道理——东西多不怕，怕的是没分格。装的时候按顺序塞、用分隔符分格（逗号、竖线 `|`、制表符都行），取的时候按格拆。你以后读到的 csv 文件（表格导出、日志、服务器返回），本质都是"别人打包好的串"。会拆包，等于会读半个互联网的数据。

### 0x31.7 压轴实战：自造"查找器"
BASIC 没有"在串里找字"的现成函数（别的语言叫 Instr/Find），我们**自己造一个**：在 s$ 里找 w$ 出现的位置，找不到报 0。

思路：从第 1 个字符起，逐个位置试——每个位置切出一块 wl 长的片段，跟目标比一比；比中了就记下位置。

```basic
10 s$ = "hello memoria"
20 w$ = "memo"
30 sl = len(s$)
40 wl = len(w$)
50 found = 0
60 i = 1
70 while i + wl - 1 <= sl
80   if mid$(s$, i, wl) = w$ then found = i
90   i = i + 1
100 wend
110 print found
120 end
```

打印 `7`（"memo" 从第 7 个字符开始）。

逐块讲解：

- 60 行：i 是"试到第几个字符了"，从 1 开始。
- 70 行：只要"目标长度还能塞得下"（i + wl - 1 不超过总长），就继续试。
- 80 行：从 i 起切出 wl 字符，跟 w$ 比对，比中就记录位置。
- 90 行：挪一个字符继续试。

**没工具有什么了不起，for/while + mid$ + 比较，十行造一个**——这就是编程思想第 2.5 节说的"没有工具自己打一把"。这个查找器你以后会在很多程序里反复用（找分隔符切背包、找关键词……）。

### 练习题

**练习 1**：把 "basic" 倒着打印出来（输出 `cisab`）。提示太少？再给一条：从最后一个字符开始，一个一个往左挪，用 chr$……不对，用 mid$ 切出来拼。

> 提示：`while i >= 1`，从 i = 5 开始，每圈拼上 `mid$(w$, i, 1)`，i 减 1。（mid$ 按字符切，每圈切 1 个字符。）

**练习 2**：检查变量 f$（文件名）是否以 `cfg` 结尾，是打印 `yes` 否打印 `no`。

> 提示：right$(f$, 3) = "cfg"。

**练习 3**：串 n$ = "42"，把它转成数字后**平方**，再把结果拼进文字打印成 `result=1764`。

> 提示：val 转进去，算完 str$ 转出来。一来一回都要过海关。

**练习 4**：统计串 s$ = "banana" 里字母 a 出现的次数。

> 提示：循环 i 从 1 到 len(s$)，每圈切 `mid$(s$, i, 1)`，跟 "a" 比，比中计数器加一。

**参考答案**：

练习 1：
```basic
10 w$ = "basic"
20 i = len(w$)
30 out$ = ""
40 while i >= 1
50   out$ = out$ + mid$(w$, i, 1)
60   i = i - 1
70 wend
80 print out$
90 end
```

练习 2：
```basic
10 f$ = "system.cfg"
20 if right$(f$, 3) = "cfg" then print "yes" else print "no"
30 end
```

练习 3：
```basic
10 n$ = "42"
20 x = val(n$)
30 r = x * x
40 print "result=" + str$(r)
50 end
```

练习 4：
```basic
10 s$ = "banana"
20 c = 0
30 i = 1
40 while i <= len(s$)
50   if mid$(s$, i, 1) = "a" then c = c + 1
60   i = i + 1
70 wend
80 print c
90 end
```

（打印 3。）

### 本章小结

- 串拼串用 `+`；串数换算：`str$` 去、`val` 回，val 遇非数字得 0。
- `len` 按字符量：汉字算 1 个字符。
- 切片：left$ / right$ / mid$（start 从 1 起，按字符切，汉字安全）。
- `chr$(65)`="A"；大写小写差 32；没有反向函数。
- 数组：新固件有 `dim`（见语言手册）；串 + 分隔符当背包，自造查找器来切片，老固件/老程序必备。
- 自造工具三件套：while 推进 + mid$ 切片 + 比较。

---

## 0x41 绘图：屏幕是画布
你好！今天换个大场地——离开文字区，去整块屏幕上作画。核心语句就 8 个，但组合起来能画国旗、画图表、做动画；章尾还有 APP 模式的 GUI 控件加成。学完这章，你的程序从"打字机"升级成"画板"。

### 0x41.1 坐标系：先看懂地图
屏幕分辨率 **480×320**（宽 480，高 320，ILI9488 横向屏），每个点（像素）用 `(x, y)` 定位：

- 原点 `(0, 0)` 在**左上角**；
- x 向**右**增大，y 向**下**增大。

**注意：跟数学课的坐标系不一样！** 数学课 y 向上，屏幕 y 向下——因为老显示器是从上到下一行行扫描点亮的，惯例就这么传下来了。画图时心里默念："y 大 = 越靠下。"

> **彩蛋 E16：屏幕是长个子的**
> 现在的屏幕是 480×320，但早几版固件是 320×240——分辨率从"小方块"长成"宽屏"的过程中，不少老程序还留着旧坐标：画出来的东西缩在左上角，就像给大人穿小孩的鞋。你如果翻到旧代码里 `x > 315`、`rnd(0, 239)` 这种数字，就知道它写在 320×240 时代。本书 v4 已把全部示例校对成 480×320——你抄进去就是满屏的。

### 0x41.2 color 与 clear：笔和橡皮
```basic
10 color 255, 0, 0
20 clear
30 end
```

- `color r, g, b`：调**当前画笔颜色**。三个数各 0~255，分别是红、绿、蓝的剂量——三原色混色：红+绿=黄，红+蓝=紫（品红），绿+蓝=青，全 0=黑，全 255=白。之后画的任何东西都用这支笔。
- `clear`：整屏清黑（橡皮）。

> 自己调颜色的直觉：0 是"一点不加"，255 是"拉满"。多试几组（255,128,0 是橙色；100,100,100 是深灰），两分钟就有手感。

### 0x41.3 六个画图语句
| 语句 | 写法 | 效果 |
|---|---|---|
| `text` | `text 10, 20, "hi"` | 在 (10,20) 打文字（用当前色） |
| `pixel` | `pixel 5, 5` | 点亮 1 个像素 |
| `line` | `line 0, 0, 100, 50` | 从 (0,0) 到 (100,50) 画一条线段 |
| `rect` | `rect 10, 10, 50, 30` | 画矩形**边框**：左上 (10,10)，宽 50 高 30 |
| `fill` | `fill 10, 10, 50, 30` | 同上，但**实心**填充 |
| `circle` | `circle 120, 80, 40` | 以 (120,80) 为圆心、半径 40 画**圆框** |

rect/fill 的后两个参数是**宽和高**，不是右下角坐标——新手高频坑，标红记住。

### 0x41.4 实战一：画个小房子
```basic
10 color 180, 120, 60
20 fill 120, 120, 80, 70
30 color 150, 60, 40
40 line 110, 120, 160, 70
50 line 160, 70, 210, 120
60 color 60, 60, 60
70 fill 145, 150, 30, 40
80 end
```

拆解：棕色实心矩形当房身（120,120 起，宽 80 高 70）；两条红线当屋顶斜边（从屋檐两头汇聚到屋脊 (160,70)）；深灰实心小矩形当门。跑一遍，再改改数字看每行各管哪块——**改数字观察变化**是学绘图最快的方法。

### 0x41.5 实战二：进度条（绘图版）
0x21 打过文字版进度条，绘图版更有内味：

```basic
10 color 0, 200, 80
20 for i = 1 to 20
30   fill 10, 100, i * 15, 20
40   wait(100)
60 next i
70 end
```

每圈把进度条加宽 15 像素重画一遍（fill 盖上去就是"变长"），中间那个 `wait` 是**拖时间**用的——马上讲。

### 0x41.6 动画原理与延时
动画的原理一句话：**画一帧 → 擦掉 → 画下一帧 → 循环**。人眼每秒看 20 帧以上就动起来了。

问题来了：机器跑得飞快，一秒能画几千帧，太快只能看成一团糊。需要"每帧之间歇口气"。**延时用 `wait` 语句**（`wait(150)` = 停 150 毫秒，参数以毫秒计，数字自己调）；APP 模式另有 `delay`（`delay 100` = 停 100 毫秒，范围 1~60000，见 0x41.7）。别再用空转循环白跑几万圈拖时间了，那是上上个时代的土办法：

```basic
wait(150)
```

停 150 毫秒再往下走。想慢就调大，想快就调小（范围 1~60000）。

上正菜——**弹跳球**：

```basic
10 x = 20
20 y = 20
30 dx = 3
40 dy = 2
50 while 1
60   clear
70   color 255, 220, 0
80   circle x, y, 5
90   x = x + dx
100  y = y + dy
110  if x > 475 then dx = 0 - dx
120  if x < 5 then dx = 0 - dx
130  if y > 315 then dy = 0 - dy
140  if y < 5 then dy = 0 - dy
150  wait(50)
170 wend
180 end
```

讲解：

- x、y 是球心位置；dx、dy 是**每帧的位移**（速度）。
- 主循环每帧：清屏 → 画球 → 更新位置 → 撞墙调头 → 延时。
- 撞墙逻辑：x 超过右边界（480 减掉球半径），速度取反（`0 - dx` 把 3 变 -3，球就往回弹）。
- `while 1` 永动——这个程序就是靠保险丝或你手动退出的，玩着玩的程序无所谓。
- 速度写 `0 - dx` 而不是 `-dx`：负号直接跟变量在某些写法里容易歧义，`0 -` 一百个稳。

**先擦再画**的顺序不能反——反了就是每帧都在旧图上叠新球，画出一串毛毛虫。动画两大定律：**擦要擦干净，画要画得勤**。

> **彩蛋 E11：直线的算法是 1962 年的网红**
> line 语句背后跑的是 Bresenham 算法——1962 年 IBM 工程师 Bresenham 为绘图仪设计的，只用整数加减就能算出最直的斜线，快得惊人。60 多年过去了，从你的掌机到 3A 游戏显卡，画直线的底层数学还是它。你每画一条线，都在向 1962 年致敬。

### 0x41.7 GUI 控件：窗口、按钮、列表（APP 模式）
0x41 之前画的都是"像素画"。当你的 .bas 作为 **APP 在系统里运行**（basic_host 宿主，比如商店装来的程序）时，屏幕还能摆**真正的控件**：窗口、按钮、列表。绘图语句照用，控件会叠在画面上层。这套语句 PRGM 模式没有——它是 APP 模式的加成。

| 语句 | 写法 | 效果 |
|---|---|---|
| `win` | `win 20, 10, 280, 60, "menu"` | 开一个**面板窗口**：深色底+灰框，标题条深蓝。最多 8 个 |
| `list` | `list 20, 80, 280, 120` | 开一个**列表区**（黑底白字），之后用 ladd 往里填行 |
| `ladd` | `ladd "1. play"` | 往列表加一行：超宽自动换行，加满跟随滚动。最多 300 行 |
| `lclr` | `lclr` | 清空列表 |
| `lscr` | `lscr 1` | 列表滚动 n 行（1 往下，-1 往上） |
| `btn` | `btn 20, 210, 130, 30, "ok"` | 画一个**按钮**（矩形深色块+白字）。最多 8 个 |
| `bsel` | `bsel 0` / `bsel -1` | 设置按钮**焦点**：焦点按钮黄框高亮；-1 取消焦点 |
| `bkey(i)` | `k = bkey(0)` | **按钮点击事件**：按钮 i 是否被"按下"（按 Enter 或摇杆确认，焦点落在哪个按钮就记哪个），读后清零。1 表示被按过，0 没有——和 key() 一样是非阻塞轮询 |
| `lbl` | `lbl 1, 20, 260, "score: 0"` | **文本控件**：id 号 + 位置 + 文字，可随时改、不用重画整屏。最多 16 个，同 id 再写就是更新。可选第 5 参样式：0 正常 / 1 反白 / 2 粗体 |
| `llbl` | `llbl 1, "score: 5"` | 只改文本控件的内容（同 id），顺手也能带样式参数 |
| `lbld` | `lbld 1` | 删除一个文本控件 |
| `img` | `img 5, 10, 10` | 画一个**内置图标**：id 0 电池 / 1 WiFi / 2 音符 / 3 文件夹 / 4 齿轮 / 5 星 / 6 心 / 7 右箭头，16×16 点阵，用当前 color 当前景色 |
| `after` | `after 3000, 500` | **非阻塞定时器**：3000 毫秒后跳到行号 500 继续跑（一次性）。不像 delay 那样干等——到点前程序照常执行别的语句。注意：阻塞类语句（delay/httpget/input 等）期间不触发，回解释器后检查 |
| `inputat` | `inputat 10, 200, 300, 40` | 把 `input a$` 的录入框挪到 (x,y,w,h)。不写就默认在屏幕下方 |
| `key()` | `k = key()` | **非阻塞读按键**：返回按下的键码，没按键返回 0 |
| `delay` | `delay 100` | 等待 100 毫秒（1~60000），替代空转循环 |
| `wait` | `wait(150)` | 等待 150 毫秒（参数以毫秒计，1~60000），PRGM 模式的标准延时 |

`text` 也能带样式：`text x, y, "文字", 样式`——0 正常 / 1 反白（彩底黑字）/ 2 粗体（右侧重描一遍）。反白适合做高亮提示，粗体适合做标题。

渲染模型一句话：**BASIC 只管声明**（win/btn/list/lbl 都是"我要这么摆"），屏幕由系统每帧自动重放——不用自己画窗口边框、不用管刷新，控件长啥样系统全包了。

来，做个迷你菜单界面：

```basic
10 win 20, 10, 280, 56, "menu"
20 list 20, 76, 280, 110
30 ladd "1. play music"
40 ladd "2. record voice"
50 ladd "3. wifi info"
60 btn 20, 196, 130, 30, "ok"
70 btn 170, 196, 130, 30, "exit"
80 bsel 0
90 end
```

跑起来就是一个带标题条的窗口、一个三行列表、两个按钮，第一个按钮黄框高亮。真正的"点击"交互有两个轮询口：**`bkey(i)` 查按钮按下**（按 Enter 或摇杆确认，焦点落哪个按钮就记哪个，读后清零），或者 `key()` 读方向键自己切焦点再判断——0x83 综合项目那套"状态机"思维正好用上。示例：

```basic
10 win 20, 10, 280, 56, "menu"
20 list 20, 76, 280, 110
30 ladd "1. play music"
40 ladd "2. record voice"
50 ladd "3. wifi info"
60 btn 20, 196, 130, 30, "ok"
70 btn 170, 196, 130, 30, "exit"
80 bsel 0
90 lbl 1, 20, 234, "press ok / exit"
100 if bkey(1) = 1 then goto 300
110 if bkey(0) = 1 then goto 200
120 goto 100
200 lbl 1, 20, 234, "ok clicked"
210 delay 800
220 end
300 lbl 1, 20, 234, "exit clicked"
310 delay 800
320 end
```

跑起来摇杆/方向键选按钮、按确认键，顶部文本控件会换成"ok clicked"或"exit clicked"——用 `llbl` 改内容不重画整屏，滚动列表和按钮都在原地。

### 练习题

**练习 1**：画 7 条横条做"彩虹"：7 个实心矩形，从 y=0 到 y=210，每条高 30，颜色自选（用循环 + 让颜色变）。

> 提示：for i = 0 to 6；fill 0, i * 30, 480, 30；color 里放变量——比如 color 255 - i * 30, i * 30, 128，看出现什么渐变。

**练习 2**：以屏幕中心 (240,160) 为圆心，画 5 个同心圆，半径 20、40、60、80、100。

> 提示：for r = 20 to 100 step 20；circle 240, 160, r。

**练习 3**：画一条从左上角 (0,0) 到右下角 (479,319) 的斜线，再画一条从右上角 (479,0) 到左下角 (0,319) 的斜线。

> 提示：两个 line，四个坐标。画完是什么形状？大叉。

**练习 4**：改弹跳球：让球是**实心的**，并且每撞一次墙，屏幕顶上用 text 显示**已反弹次数**。

> 提示：circle 换 fill x-5, y-5, 10, 10 不太圆但能看；计数器 c 每次撞墙加一，text 10, 10, "hits " + str$(c)——记得 str$ 过海关。

**参考答案**：

练习 1：
```basic
10 for i = 0 to 6
20   color 255 - i * 30, i * 30, 128
30   fill 0, i * 30, 480, 30
40 next i
50 end
```

练习 2：
```basic
10 color 0, 255, 0
20 for r = 20 to 100 step 20
30   circle 240, 160, r
40 next r
50 end
```

练习 3：
```basic
10 color 0, 255, 255
20 line 0, 0, 479, 319
30 line 479, 0, 0, 319
40 end
```

练习 4：
```basic
10 x = 20
20 y = 20
30 dx = 3
40 dy = 2
50 c = 0
60 while 1
70   clear
80   color 255, 220, 0
90   fill x - 5, y - 5, 10, 10
100  color 0, 255, 0
110  text 10, 10, "hits " + str$(c)
120  x = x + dx
130  y = y + dy
140  if x > 475 then dx = 0 - dx : c = c + 1
150  if x < 5 then dx = 0 - dx : c = c + 1
160  if y > 315 then dy = 0 - dy : c = c + 1
170  if y < 5 then dy = 0 - dy : c = c + 1
180  wait(50)
200 wend
210 end
```

### 本章小结

- 坐标 480×320，原点**左上**，y 向下。
- `color r,g,b` 调笔（三原色剂量），`clear` 清屏。
- text/pixel/line/rect/fill/circle 六件套；rect 系的参数是**宽高**不是对角坐标。
- 动画 = 循环里"清屏 → 画 → 更新 → 延时"；延时用 `wait(毫秒)`（APP 模式另有 `delay`）。
- GUI 控件（APP 模式）：win 窗口 / list+ladd 列表 / btn+bsel 按钮焦点 / **bkey(i) 按钮点击** / **lbl·llbl·lbld 文本控件** / **img 内置图标** / **after 非阻塞定时** / text·lbl 样式（0 正常 1 反白 2 粗体）/ inputat 挪输入框 / key() 读键 / delay 延时。
- 弹跳球骨架：位置 + 速度 + 撞墙取反，值得背。

到今天为止，语言核心全部拿下。下一章开始，学程序的组织术——把代码管起来。

---

**彩蛋挑战 C1：做一个会走字的秒表（APP 模式）**

挑战规则：不开计时器，只用刚学的 `delay` + `lbl`/`llbl` 文本控件，做一个每秒跳一次的秒表：显示 `t= 秒`，数字在屏幕中间不动、只有数字变。

参考思路（先自己想，卡住了再看）：

```basic
10 win 20, 10, 280, 56, "stopwatch"
20 lbl 1, 20, 90, "t= 0", 2
30 t = 0
40 while 1
50   delay 1000
60   t = t + 1
70   llbl 1, "t= " + str$(t)
80 wend
90 end
```

跑起来就是一台不会停的秒表——`llbl` 只改文字不重画整屏，所以屏幕纹丝不动。挑战成功：你已经用上了 APP 模式最舒服的"局部刷新"。

## 0x51 gosub、include、goto：把代码管起来
你好！今天我们来学习程序的"收纳术"。程序一长，问题就来了：同一段代码到处复制、改一处忘三处、几千行糊成一团。今天的三件工具——gosub、include、goto——就是治这个的。

### 0x51.1 gosub / return：代码的抽屉
`gosub` 是 "go subroutine"（去子程序）：跳到某行干活，干到 `return` **原路跳回来**，接着跑下一句。

```basic
10 print "main start"
20 gosub 100
30 print "main end"
40 end
100 print "  sub: did something"
110 return
```

输出：

```
main start
  sub: did something
main end
```

执行轨迹：10 → 20 跳去 100 → 110 return **跳回 20 的下一行** 30 → 40 结束。像去银行办业务：取号（gosub 100）→ 柜台办事（100~110）→ 办完回到大堂（return 回原处）→ 继续干自己的事。

**gosub 和 goto 的区别就在"回不回来"**：goto 是一去不回头的搬家；gosub 是出差，办完事回来。这就是"子程序"（别的语言叫函数）的雏形。

### 0x51.2 子程序的摆放规矩
子程序通常放**程序末尾**，主程序用 `end` 挡住去路，防止"误入"：

```basic
10 print "1. joke  2. tip"
20 print "choose?"
30 input c
40 if c = 1 then gosub 200
50 if c = 2 then gosub 300
60 print "bye"
70 end
200 print "  why did wifi break up with cable?"
210 print "  too attached."
220 return
300 print "  tip: semicolon glues, comma spaces."
310 return
```

选 1 跳 200 行讲笑话，return 回来打 bye 结束。注意 70 行的 `end` 是**安全门**：没有它，选完 1 后 return 回 50 行继续往下走，会一头栽进 200 行的笑话区再讲一遍——程序结尾挡一块 end，是行号 BASIC 的标准工事。

gosub 还能**嵌套**：子程序里再 gosub 另一个，return 按先进后出逐层弹回（栈式管理），像下楼的电梯一站站倒回去。放心用，别超过十层。

> **彩蛋 E17：return 是怎么"记得住"来路的**
> 程序怎么知道 gosub 后要跳回哪一行？靠的是**栈**（stack）——一个"后进先出"的记性本：每进一个子程序，就把回来的地址记在最上面一格；return 时从最上面取走一格，原路返回。嵌套三层，记性本上就压着三格地址，逐层弹回。栈是计算机最古老的魔法之一：函数调用、浏览器"返回上一页"、撤销操作，全是它。你现在在 BASIC 里按的 return，就是跟五十年前的程序员按同一个键。

### 0x51.3 为什么子程序是大事
三笔账：

1. **复用**：画坐标轴的代码写一次，五个程序段都 gosub 它。
2. **单点修改**：改 bug 只改抽屉里那一份，不用全程序搜抄了八遍的代码。
3. **主程序可读**：main 区只剩"调谁"不剩"怎么干"，30 行看懂整个流程。

从今天起立个规矩：**同一段代码出现第二次，就提成子程序**。

### 0x51.4 include：把另一本册子订进来
`include "lib.bas"` 在**编译期**把另一个 .bas 文件的全部行合并进来——同号行以 include 进来的为准（覆盖）。比喻：装订时把另一本册子整本订在这本后面，页码冲突就听新册子的。

典型用法：把常用子程序（查找器、等待 WiFi、画框）放进 `lib.bas`，每个新程序开头 `include "lib.bas"`，家底直接继承。注意被 include 的文件也放在 TF 卡 `/mem_fat/scripts/` 目录。

```basic
10 include "lib.bas"
20 gosub 500
30 end
500 print "this is from lib!"
510 return
```

（如果 lib.bas 里已有 500 行，则以 lib.bas 的为准——所以**库文件和主程序的行号最好分开规划**，比如库用 500~899，主程序用 10~499。）

### 0x51.5 goto：半禁用的猛兽
`goto 100` 无条件跳到 100 行，**不回头**。它有个特殊待遇：**每轮运行时系统会提示一次**注意事项（易死循环、逻辑混乱）——这是解释器在提醒你：能不用就不用。

为什么 goto 名声差？1968 年计算机科学家 Dijkstra 写了封著名的信《Go To Statement Considered Harmful》（goto 语句有害论），指出满屏乱跳的 goto 会把程序搅成"面条"——没人能看懂执行流。这场论战催生了"结构化编程"，也就是本书开篇课讲的三大结构。**历史结论：goto 保留给大骨架跳转**（比如主菜单循环回菜单页），日常逻辑全部用 if/for/while/gosub 组织。

### 0x51.6 实战：菜单程序（标准骨架）
综合本章，一个可扩展的菜单骨架，值得收藏：

```basic
10 while 1
20   clear
30   print "=== MENU ==="
40   print "1. calc  2. joke  0. quit"
50   input c
60   if c = 0 then end
70   if c = 1 then gosub 200
80   if c = 2 then gosub 300
90   if (c <> 0) and (c <> 1) and (c <> 2) then print "??"
100 wend
200 input a
210 input b
220 print "sum="; a + b
230 return
300 print "  haha."
310 return
```

主循环 while 1 永动转菜单；选 0 end 退出；选别的 gosub 去各功能区；非法输入打问号。**菜单 = while 1 + input + 分发 gosub**——这个骨架是行号 BASIC 的万能模板，你的第一批"应用"都能从它长出来。

### 练习题

**练习 1**：主程序里让用户输入半径，然后 gosub 到 200 行的"算圆面积子程序"，打印后 return，主程序结束。

> 提示：end 挡在 100 行；200 行算完 return 前别加 end。

**练习 2**：做一个"报数子程序"：gosub 300 会打印 `hello from sub`，主程序连续调用它 3 次（不许用循环，体会一下；再想想用循环怎么写）。

> 提示：三行 gosub 300；循环版：for i = 1 to 3 : gosub 300 : next i。

**练习 3**：把0x31 的"查找器"整体搬进 400 行起的子程序（查找目标和被查串改为"调用前设好的变量"），主程序设好 s$ 和 w$ 后 gosub 400 调用。

> 提示：子程序直接用主程序设的变量（BASIC 变量全局共享，没有"传参"一说）；子程序结尾 return。

**参考答案**：

练习 1：
```basic
10 print "radius?"
20 input r
30 gosub 200
40 end
200 area = 3.14159 * r * r
210 print "area="; area
220 return
```

练习 2：
```basic
10 gosub 300
20 gosub 300
30 gosub 300
40 end
300 print "hello from sub"
310 return
```

循环版（第 10 行换成）：
```basic
10 for i = 1 to 3 : gosub 300 : next i
```

练习 3：
```basic
10 s$ = "hello memoria"
20 w$ = "memo"
30 gosub 400
40 print found
50 end
400 found = 0
410 sl = len(s$)
420 wl = len(w$)
430 i = 1
440 while i + wl - 1 <= sl
450   if mid$(s$, i, wl) = w$ then found = i
460   i = i + 1
470 wend
480 return
```

### 本章小结

- `gosub 行号` ... `return`：出差模式，办完回来；栈式可嵌套。
- 主程序末尾 end 挡安全门，子程序排在 end 之后。
- 同段代码出现第二次就提子程序。
- `include "lib.bas"` 编译期合并，同号覆盖；库行号要跟主程序分区规划。
- goto 半禁用（每轮提示）；能三大结构解决就不 goto。
- 菜单万能骨架：while 1 + input + gosub 分发。

---

## 0x61 WiFi 与网络：把掌机接上互联网
你好！今天是个大日子：我们让掌机**联网**。从这一章起，你的程序不再是一座孤岛——能拉网页、传数据、跟服务器聊天。今天学的三件套 httpget / httppost / httpstat，就是将来"畅聊"聊天应用的全部地基。

### 0x61.1 连 WiFi：系统管网，程序只读状态
**WiFi 由系统统一管理**——跟手机一样，在系统设置里有 WiFi 扫描列表，点选连接、输密码，都是设置页的事。程序**不允许也不应该自己连网**（老写法 `wifi "ssid","pass"` 是保留兼容语句，联网程序调用会被忽略并提示）。那程序怎么知道连没连上？读系统预注入的**环境变量**：

| 预注入变量 | 说明 |
|---|---|
| `wifi_ssid$` / `wifi_pass$` | 系统当前连接的 WiFi |
| `ap_ssid$` / `ap_pass$` | 系统开出的 AP 热点（系统设置里自定义） |
| `ble_name$` | 蓝牙名称（系统设置里配置） |

```basic
10 if wifistat() = 0 then print "wifi 未连，去系统设置连网" : end
20 print "当前WiFi: "; wifi_ssid$
30 end
```

- `wifistat()`：查询函数，**1 = 已连上，0 = 没连上**。
- `wifi_ssid$` 这类变量**随系统连接状态自动更新**，程序开机直接读就行。

连完必须查状态——代码要养成"**联网必验**"的习惯，别把没网当有网往下跑。要更稳，用0x22 的"计数超时"骨架等连接。

### 0x61.2 httpget：伸手要内容
```basic
10 httpget "http://192.168.1.100/api/hello", r$
20 print r$
30 end
```

- `httpget "网址", r$`：向网址发 GET 请求（"把内容给我"），服务器回的**响应体**存进串变量 r$。
- r$ 上限 **8KB**——服务器回太大就装不下，设计接口时要控制内容尺寸。
- 网址目前**只支持明文 http://**（HTTPS 后补）。所以别用它传密码等敏感信息，路上是裸奔的。

### 0x61.3 httpstat：问一句"成了吗"
`httpstat()` 返回**上一次 HTTP 请求的状态码**：

- `200`：成功（HTTP 世界里 200 = OK）；
- `404`：没这个页面；`500`：服务器出错；
- `0`：压根没请求成功/连接失败。

```basic
10 httpget "http://192.168.1.100/api/hello", r$
20 s = httpstat()
30 if s = 200 then print r$ else print "http err "; s
40 end
```

标准姿势：**先 httpget，后查 httpstat，200 才用 r$**。三步走，一步不少。这个"验后再用"跟 wifi 的"联网必验"是同一套纪律。

> **彩蛋 E12：404 是个房间号？**
> 流传最广的都市传说：CERN 实验室 404 房间是网络工作组所在地，找不到文件就报"404"。其实官方说法很无聊：4xx = 客户端错（你输错网址），404 = "Not Found"，编号是分类流水号。但传说太好听，大家都懒得辟谣——你看，互联网自己就是最好的故事会。

### 0x61.4 httppost：主动交作业
`httpget` 是"我要"，`httppost` 是"我给"：

```basic
10 httppost "http://192.168.1.100/api/send", "hello from memoria", r$
20 if httpstat() = 200 then print "sent" else print "fail "; httpstat()
30 end
```

- 第 2 个参数 b$（这里是字符串字面量）**原样上传**，服务器收到一串字节（octet-stream 类型）。
- 第 3 个参数 r$ 接服务器回复，跟 httpget 一样。

**一拉一推，就是全部网络交互**：聊天应用 = httppost 发消息 + httpget 拉新消息；天气应用 = httpget 拉天气；上报传感器 = httppost 发读数。0x83 综合项目就是这一章的毕业考试。

> **彩蛋 E18：状态码是一套暗号**
> HTTP 状态码按百位分族，像江湖切口：**2xx = 成了**（200 OK，一切顺利）；**3xx = 换个地方**（页面搬家，让你去新地址）；**4xx = 你的锅**（404 找不到、403 没权限，都是客户端这边的问题）；**5xx = 服务器的锅**（500 服务器自己炸了）。所以排查网络问题第一步永远是看状态码：4 开头怪自己，5 开头怪对方，0 开头——压根没连上，先查 WiFi。这三句话记熟，你比不少"资深网民"都专业。

### 0x61.5 一个完整的"求职"客户端
把本章 + 超时骨架 + val/str$ 串起来：

```basic
20 t = 0
30 while wifistat() = 0
40   t = t + 1
50   if t > 50000 then print "wifi timeout" : end
60 wend
70 httpget "http://192.168.1.100/api/num", r$
80 if httpstat() <> 200 then print "http err "; httpstat() : end
90 n = val(r$)
100 print "server says: "; n * 2
110 end
```

服务器回一个数字文本（比如 `"21"`），客户端 val 转成数字、翻倍打印。**拉回来 → 验状态 → 转格式 → 加工 → 输出**，五步流水线，一切网络程序都是它的变体。

### 练习题

**练习 1**：写"联网体检"程序：连 WiFi（带超时），连上了打印 `net ok` 和 wifistat() 的值；连不上打印 `net fail` 后结束。

> 提示：第 7.5 节骨架 + 结尾两分支。

**练习 2**：httpget 拉一个接口，**重试 3 次**：每次拉完查 httpstat，200 就打印内容并停，否则重试；3 次都失败打印 `give up`。

> 提示：for i = 1 to 3，循环里 get + if httpstat() = 200 then 打印后 end（then 体内冒号连 end）。

**练习 3**：用 httppost 向服务器上报一条文字 `memoria online`，根据 httpstat 打印 `reported` 或错误码。

> 提示：照 11.4 改内容；上报也是"发完必验"。

**参考答案**：

练习 1：
```basic
20 t = 0
30 while wifistat() = 0
40   t = t + 1
50   if t > 50000 then print "net fail" : end
60 wend
70 print "net ok "; wifistat()
80 end
```

练习 2：
```basic
10 for i = 1 to 3
20   httpget "http://192.168.1.100/api/hello", r$
30   if httpstat() = 200 then print r$ : end
40 next i
50 print "give up"
60 end
```

练习 3：
```basic
20 t = 0
30 while wifistat() = 0
40   t = t + 1
50   if t > 50000 then print "wifi timeout" : end
60 wend
70 httppost "http://192.168.1.100/api/report", "memoria online", r$
80 if httpstat() = 200 then print "reported" else print "err "; httpstat()
90 end
```

### 本章小结

- WiFi 由系统设置统一管理，程序只读 `wifistat()` 状态与 `wifi_ssid$` 等预注入变量；**联网必验**。
- `httpget "url", r$` 拉；`httppost "url", b$, r$` 推；响应体 ≤8KB。
- `httpstat()`：200 成功、0 没连上；**验后再用**。
- 仅明文 http；别传敏感信息。
- 网络五步流水线：拉回来 → 验状态 → 转格式 → 加工 → 输出。

---

**彩蛋挑战 C2：服务器的暗号**

挑战规则：在服务器上放一个文本文件 `answer.txt`，里面只写一个 1~100 的数。写一个程序：联网、拉这个数、让用户摇杆猜，猜中打印隐藏台词。

参考思路（先自己想，卡住了再看）：

```basic
10 if wifistat() = 0 then print "no wifi" : end
20 httpget "http://192.168.1.100/answer.txt", a$
30 if httpstat() <> 200 then print "http err "; httpstat() : end
40 print "server's number is hidden."
50 print "guess (1-100):"
60 input g
70 if str$(g) = a$ then print "you got it!" else print "nope, it was "; a$
80 end
```

注意 70 行：`str$(g)` 是"数字→文字"过海关，因为 a$ 是文字、g 是数字，不能直接比。挑战成功：你已经把 0x31 的 val/str$ 和 0x61 的网络串成了一条真正的"联网小游戏"。

---

## 0x62 record 与 play：给程序装上耳朵和嘴巴
你好！今天我们来学习声音。之前所有交互都靠"看"，今天加入"听"和"说"：`record` 让掌机竖起耳朵录音，`play` 让它开口放音。学完你就能做录音机、留言机——这也是"畅聊"语音消息的地基。

### 0x62.1 record：录音（会阻塞）
```basic
10 record "/mem_fat/v1.wav", 3
20 print "done"
30 end
```

`record "路径", 秒数`：对着麦克风录一段声音，存成 WAV 文件到 TF 卡。规则三条：

1. **时长 1~60 秒**，示例录 3 秒。
2. 录的是 **16kHz 单声道 16bit 的 WAV**——掌机自动包好格式，你只管给路径。
3. **阻塞**：录音那几秒，程序站着不动——你在录音，它不干别的。

"阻塞"是个重要概念：**这行不执行完，下一行不开始**。所以 record 前最好先 print 一句"recording..."，不然用户不知道机器在干嘛。

### 0x62.2 play：放音（不阻塞）
```basic
10 play "/mem_fat/v1.wav"
20 print "playing in background"
30 end
```

`play "路径"`：播放 WAV（MP3 也认）。跟 record 相反——**后台播放，不阻塞**：声音还在响，程序已经跑到下一行。适合"音乐当背景，界面继续动"的场景。

一表对比记住：

| | record | play |
|---|---|---|
| 干嘛 | 麦克收音存 WAV | 放 WAV/MP3 |
| 阻塞 | 是（1~60 秒站住） | 否（后台响） |
| 产物 | TF 卡上多一个 .wav | 听见声音 |

### 0x62.3 实战：录音回放机
```basic
10 print "recording 3s..."
20 record "/mem_fat/v1.wav", 3
30 print "playing..."
40 play "/mem_fat/v1.wav"
50 print "program end (sound keeps)"
60 end
```

录 3 秒、放 3 秒。注意 50 行打印后程序其实已经结束了，但声音还在后台放——这就是"不阻塞"。

> **彩蛋 E13：16kHz 是什么音质**
> 电话的采样率是 8kHz，能听清就是不太甜；16kHz 是"清清楚楚但别要求 hi-fi"的水平。WAV 本身是微软/IBM 搞的 RIFF 格式，声音原样存不压缩——所以大，所以简单，所以任何设备都认。你的掌机选 WAV 全链路，走的就是"笨一点但谁都吃得消"的路线。

### 0x62.4 实战：简易留言机
文件名用变量拼，就能留好几条：

```basic
10 n = 1
20 while n <= 3
30   print "message "; n; " recording..."
40   record "/mem_fat/note.wav", 3
50   print "playing back..."
60   play "/mem_fat/note.wav"
70   n = n + 1
80 wend
90 end
```

循环三轮：录 3 秒、放 3 秒。想存**不同文件名**？串拼接：`"/mem_fat/note" + str$(n) + ".wav"`——第 n 条存 note1.wav、note2.wav……（上机时把 40、60 行的路径换成这个拼法试试，练 str$。）

一个容易撞墙的坑：想"把录音内容读进变量"——旧固件 BASIC 没有通用文件读取（record 只会写 WAV、play 只会放 WAV）。新固件有了 `fread`（读文件进变量，见《语言手册》）；但"把录音发到网上"其实**不用读内容**——直接传整个文件：录完 3 秒，`httpup` 把 WAV 文件整个 POST 给服务器（httpup 是网络家族成员，正文 0x61 教的是它三兄弟 httpget/httppost/httpstat，速查见附录 A）：

```basic
10 record "/mem_fat/note.wav", 3
20 httpup "http://192.168.1.5/upload", "/mem_fat/note.wav", r$
30 print "upload code="; httpstat()
40 end
```

服务器收到的是完整 WAV 字节流（octet-stream），谁都能存能播。**记住分工：读文件内容进变量做不到，但整个文件上传不用读内容——httpup 直接搬字节。**

### 练习题

**练习 1**：录 5 秒并播放，录之前和录之后各打印一句提示。

> 提示：print + record + print + play。

**练习 2**：连录两段（v1.wav、v2.wav），然后连放两遍。文件名用串拼。

> 提示：`"/mem_fat/v" + str$(i) + ".wav"`，i 跑 1 和 2；两段 record + 两段 play。

**练习 3**（设计题，不用写完整代码）：做一个"开机三次提示音"程序：每次开机连播三遍提示音再结束。想一想：播放不阻塞，三遍连播会怎样？要不要在 play 之间加延时？

> 提示：不阻塞 = 三条 play 会几乎同时响（叠音）。土办法：play 之间 `wait(2000)` 拖两秒；或者干脆接受叠音当和弦。设计没有标准答案，但要**知道后果再选**。

**参考答案**：

练习 1：
```basic
10 print "get ready..."
20 record "/mem_fat/v1.wav", 5
30 print "recorded, now play"
40 play "/mem_fat/v1.wav"
50 end
```

练习 2：
```basic
10 i = 1
20 record "/mem_fat/v" + str$(i) + ".wav", 2
30 i = 2
40 record "/mem_fat/v" + str$(i) + ".wav", 2
50 play "/mem_fat/v1.wav"
60 play "/mem_fat/v2.wav"
70 end
```

练习 3（参考思路）：三条 play 背靠背会叠音；在每条后加 `wait(3000)`（时长按提示音长短调）可顺序播放。

### 本章小结

- `record "路径", 秒`：录 WAV，1~60 秒，**阻塞**。
- `play "路径"`：放 WAV/MP3，**后台不阻塞**。
- 阻塞/不阻塞是程序节奏的核心概念。
- 文件名可串拼（str$）实现多条存取。
- 边界：旧固件没有通用文件读取，别设计"读文件进变量"的方案；新固件有 `fread`/`fwrite`（见语言手册），上传文件用 `httpup` 直接搬字节。

---

## 0x71 uart、ble、gpioin、system：摸得着的硬件
你好！今天我们来学习掌机的"手脚"。前面会画会说会联网了，今天补上最后几件硬件家伙：调试口、蓝牙、读引脚、重启。学完这章，BASIC 的全部家当你就见完了。

### 0x71.1 uart：往电脑喊话的专线
```basic
10 uart "boot ok"
20 uart "value=" + str$(42)
30 end
```

`uart "文本"` 把文字发到 **USB 串口**。掌机插上电脑，打开串口调试工具（波特率按固件说明），就能看到这些话。print 是打给用户看的，uart 是打给**开发者**看的——程序跑岔了，沿途多埋几条 uart，串口一看就知道死在哪一步。这招叫"打点调试"，是每个老程序员兜里最旧的瑞士军刀。

### 0x71.2 ble：蓝牙透传
```basic
10 ble "hello from memoria"
20 end
```

`ble "文本"` 通过**蓝牙**把文字发给已连接的上位机（电脑/手机上的蓝牙调试工具）。配套玩法：手机蓝牙串口 App 连上掌机，就能收发文字——不给 WiFi 也能隔空喊话。前提是**上位机已连接**，没连接就发了个寂寞。

### 0x71.3 gpioin：读引脚电平
```basic
10 x = gpioin(4)
20 print "gpio4="; x
30 end
```

`gpioin(引脚号)` 读某个 GPIO 引脚的电平，返回 **0 或 1**。引脚上接按钮、门磁、光敏电阻……电平就随外界变化。轮询它，程序就"摸得到"外面的世界。

```basic
10 while 1
20   x = gpioin(4)
30   clear
40   color 0, 255, 0
50   if x = 1 then text 20, 100, "ON" else text 20, 100, "OFF"
60   wait(100)
80 wend
90 end
```

这是一个"引脚状态监视器"：每 0.1 秒刷一次 GPIO4 的电平，高就显示 ON，低就显示 OFF。**轮询 = while 1 + 读 + 刷屏 + 延时**，跟弹跳球一个骨架，只是"位置更新"换成了"读外界"。

### 0x71.4 system：重启
```basic
10 system "reboot"
```

`system "reboot"` 让整台掌机重启（当前唯一支持的动作）。测试稳定性、脚本演示"自复位"时用。**慎用**：重启是核弹级动作，没保存的现场都没了。

> **彩蛋 E19：重启是计算机的"过劳疗法"**
> 万物都讲究"关机重启大法"：路由器卡了重启、手机卡了重启、人迷糊了睡一觉——计算机界管这叫"重启能解决 90% 的问题"。原理不是玄学：跑久了的程序会把内存搅成一团乱麻（碎片、泄漏、死锁），重启等于把脑内清零、重新开机。你的掌机也一样：程序写崩了、界面卡住了，别急着拆机，先按重启。人类版的"重启"，就是关机睡一觉——你熬夜写代码写迷糊的时候，也适用。

### 0x71.5 实战：门磁报警器（思路版）
把 13.3 的监视器升级：GPIO4 接门磁开关，门开（电平变 1）就大字报警：

```basic
10 while 1
20   x = gpioin(4)
30   clear
40   if x = 1 then color 255, 0, 0 else color 0, 255, 0
50   if x = 1 then text 40, 100, "DOOR OPEN!" else text 40, 100, "safe"
60   wait(100)
80 wend
90 end
```

color 跟着状态换色、字号级警示。想更凶？加 `ble "door open!"` 往手机蓝牙推一条——**读引脚 + 分支 + 通知**，一个物联网雏形就成了。

### 练习题

**练习 1**：开机后用 uart 打三行启动日志：`boot`、`memoria basic ok`、`version 2`，然后打印到屏幕 `booted`。

> 提示：三行 uart + 一行 print。

**练习 2**：写一个"GPIO3 电平记录员"：读 10 次 GPIO3（每次间隔 `wait(200)`），把每次的值累加成一行 `1,1,0,...` 打出来。**不用数组怎么记 10 个值**？——用0x31 背包思想：把值转成串往 log$ 里追加（新固件也可以 `dim a(10)`，见语言手册）。

> 提示：for i = 1 to 10；`log$ = log$ + str$(gpioin(3)) + ","`；最后 print log$。

**练习 3**：把门磁报警器改成"报警 5 次后自动结束"：每次轮询发现门开，计数加一；计满 5 次 system "reboot"。（纯练习，真别拿去装门上。）

> 提示：c = c + 1；if c >= 5 then system "reboot"。

**参考答案**：

练习 1：
```basic
10 uart "boot"
20 uart "memoria basic ok"
30 uart "version 2"
40 print "booted"
50 end
```

练习 2：
```basic
10 log$ = ""
20 for i = 1 to 10
30   log$ = log$ + str$(gpioin(3)) + ","
40   wait(200)
60 next i
70 print log$
80 end
```

练习 3：
```basic
10 c = 0
20 while 1
30   x = gpioin(4)
40   if x = 1 then c = c + 1
50   clear
60   text 20, 100, "alarm " + str$(c)
70   if c >= 5 then system "reboot"
80   wait(100)
100 wend
110 end
```

### 本章小结

- `uart "文本"`：串口调试专线，打点排错神器。
- `ble "文本"`：蓝牙透传（上位机需已连接）。
- `gpioin(引脚)`：读电平 0/1；轮询 = while + 读 + 刷屏 + 延时。
- `system "reboot"`：重启，慎用。
- 至此 BASIC 核心语句见完：核心 12 句 + 绘图 8 句 + GUI 控件（APP 模式）+ 硬件网络语音若干；新固件还有数组/自定义函数等高级语句，见《语言手册》——附录 A 有总表。

## 0x72 好习惯与保命机制
你好！今天不讲新语句——语法你已全见完。今天讲"内功"：怎么少踩坑、出错了怎么查、程序怎么写别人（和三个月后的你）看得懂。这章的内容，价值不比前面任何一章低。

### 0x72.1 三道保命机制（系统替你上的保险）
| 机制 | 内容 | 你要做的 |
|---|---|---|
| 步数上限 | 每程序最多执行 100000 步，超限强制终止，报"超时保护" | 别依赖它收尾，循环要能自己结束 |
| 包校验 | .msp 安装包 CRC32 校验，损坏/被篡改的包拒绝落盘 | 从正规渠道装程序 |
| 跳转语义 | goto/gosub/return/循环跳转后，目标行**真正被执行**（不是"跳过了"） | 知道这个语义，读代码不迷路 |

> **彩蛋 E20：为什么是十万步**
> 步数上限不是随手定的：一台 ESP32-S3 跑到 240MHz，一秒大约能执行几十万条 BASIC 语句——十万步正好是"一眼看上去像死机、实际还活着"的那条线。定少了，正经的重活（算大数、遍历大背包）会被误杀；定多了，死循环要等半天才收场。十万这个数，是"放过正常人、拦下疯子"的工程折中。你以后设计任何"限制"（超时、内存上限、重试次数），都可以想想：这条线，放过了谁，拦住了谁。

### 0x72.2 rem 注释：给代码留字条
很多语言有注释，程序里写给人看、机器跳过。**BASIC 有 `rem`**：行首 `rem` 开头（不区分大小写），这一行到行尾全被机器忽略：

```basic
10 rem this is a comment, the machine skips it
20 print "hello"
30 rem 中文也能写：这一行是字条，不执行
40 end
```

`rem` 写在行首最稳；写在语句后面（冒号之后）也认，但 REM 之后的同行内容一律忽略。字条写什么：这行/这段在干什么、为什么这么写、以后回来改的人是你自己。再配两招：

1. **起好变量名**：`sum`、`name$`、`retry_count` 自带说明，`a`、`b2`、`zz` 是天书。
2. **小步快跑**：一次只加三五行就运行一次——代码短到读得动，也是一种注释。

### 0x72.3 出错了怎么查：打点调试法
程序行为不对，按这个顺序查：

1. **二分打点**：在程序中间和末尾各加一行 `uart "check1"`、`uart "check2"`。跑一次：都出现——毛病在后半段；只有 check1——毛病在前半段。再在可疑段中间打点……几轮就夹出病灶。
2. **打印变量**：疑心哪个变量，就 `print` 或 `uart` 它的值，看它"什么时候变得不对劲"。
3. **怀疑顺序**：先怀疑自己的**条件边界**（> 写成 >=、off by one），再怀疑自己的**赋值顺序**（先除后乘？先覆盖后使用？），最后才轮到"是不是机器的问题"——99.9% 不是。

### 0x72.4 排版三律
- **一行一件事**：冒号少用，顶多连两句明显配套的。
- **行长 96 字节**：约 32 个汉字，超长写不进去；长内容拆变量装。
- **循环体缩进**：机器不看，人看。书上的习惯就是你的习惯。

### 0x72.5 找茬实战：这段程序有 3 处毛病
```basic
10 print "how old are you?"
20 input age
30 msg$ = "age:" + age
40 if age > 0 and age < 150 then print "ok"
50 for i = 1 to 3
60   print i
70 while age > 0
80   age = age - 1
90 end
```

先自己找 5 分钟，再看答案。

**答案**：

1. **第 30 行：串数混算**——`"age:" + age` 违反铁律，要 `str$(age)`。
2. **第 50 行：for 没配 next**——循环开出去没人收口，跑到 while 就乱套。补一行 `next i`。
3. **第 70 行：while 没配 wend**——同上，缺收口；而且 90 行的 end 在 while 体内，就算补了 wend 逻辑也是歪的。

（第 40 行的 `and` 是合法的，别挑它。）

修正版：

```basic
10 print "how old are you?"
20 input age
30 msg$ = "age:" + str$(age)
40 if (age > 0) and (age < 150) then print "ok"
50 for i = 1 to 3
60   print i
70 next i
80 while age > 0
90   age = age - 1
100 wend
110 end
```

三类毛病——**混算、循环没收口、结构嵌套错位**——占新手错误的八成。

### 0x72.6 自查十条（发布前过一遍）
1. 每个循环都有收口吗（next / wend）？
2. 串和数有没有裸混算？
3. and/or/not 用对了吗（短路、结果 1/0）？
4. if 都是完整一行吗？
5. then 数字跳转的目标行存在吗？
6. 主程序末尾有 end 挡子程序吗？
7. 死循环有出口吗（别靠保险丝）？
8. 联网必验（wifistat/httpstat）了吗？
9. 变量名见名知意吗？
10. 边界试过吗：输入 0、负数、最长串？

### 练习题

**练习 1**：指出毛病：`10 if x = 5 && y = 3 then print "yes"`——并改正。

> 提示：`&&` 不是本语言的关键字，逻辑"并且"用 and。

**练习 2**：指出毛病：`10 for i = 1 to 5 : print i`（就这一行）——并改正。

> 提示：for 缺 next。冒号句里收口：`10 for i = 1 to 5 : print i : next i`。

**练习 3**：这段想"打印 3、2、1"，实际会打印什么？为什么？怎么改？

```basic
10 i = 3
20 while i > 0
30   print i
40 wend
```

> 提示：循环体里没有推动条件变化的语句——i 永远是 3，死循环到保险丝拉闸。改：30 行后加 `i = i - 1`。

**参考答案**：

练习 1：
```basic
10 if x = 5 and y = 3 then print "yes"
```

练习 2：
```basic
10 for i = 1 to 5 : print i : next i
```

练习 3：无限打印 3（直到"超时保护"强制终止）。修正：
```basic
10 i = 3
20 while i > 0
30   print i
40   i = i - 1
50 wend
```

### 本章小结

- 三道机制：步数 100000、CRC32、跳转语义。
- rem 注释：行首 rem 整行忽略（0x72.2）；配好名字 + 小步快跑。
- 调试三板斧：二分打点、打印变量、先怀疑自己。
- 三大新手错误：混算、循环没收口、结构错位。
- 发布前过"自查十条"。

---

## 0x81 综合项目一：猜数字
你好！从今天起连做三个毕业项目。第一个：**猜数字**——电脑随机想一个 1~100 的数，你来摇杆调数猜，它提示"大了/小了"，猜中报次数。前面学的 input、if、while、rnd 全要上场。

### 0x81.1 先想流程（动笔不写码）
用开篇课的思想拆一拆：

- **顺序**：开局出题 → 进入问答循环 → 猜中收尾。
- **循环**：没猜中就一直问——圈数不知道，**while**（条件：还没猜中）。
- **分支**：每轮比较，猜中了翻旗子；没中给提示。

流程图只有一页：**出题 → 问 → 比 → 提示/收尾 → 回到问**。想清楚再写，比边写边改快十倍——这是"编程思想"值钱的地方。

### 0x81.2 完整程序
```basic
10 n = rnd(1, 100)
20 c = 0
30 win = 0
40 print "== guess 1-100 =="
50 while win = 0
60   print "your guess:"
70   input g
80   c = c + 1
90   if g = n then win = 1
100  if g < n then print "try bigger"
110  if g > n then print "try smaller"
120 wend
130 print "correct! tries="; c
140 end
```

### 0x81.3 逐行讲解
- **10 行**：出题。`rnd(1, 100)` 直接造 1~100 的随机整数，存进 n。
- **20 行**：c 是计次器，从 0 起步。
- **30 行**：win 是**旗子变量**——0 表示"还没猜中"，1 表示"中了"。旗子是 while 循环的常用搭档：条件写 `while win = 0`，读起来像人话："还没赢就继续问"。
- **60~70 行**：问一轮。input 用摇杆调数（±1/±10），调到想猜的数按下确认。
- **80 行**：本轮计次。
- **90 行**：猜中就把旗子竖起来。**注意这行不打印**——打印放到循环外面，"中了"的消息只该说一次。
- **100/110 行**：没中就给方向提示。这两行只在 g ≠ n 时动嘴。
- **130 行**：出循环后报战绩：几次猜中。

**这个程序里有个微妙的好设计**：三个 if 排排站（等于/小于/大于），互相不干扰，逻辑一目了然。新手爱写"if 嵌 if"炫技，其实**平铺三个 if 往往更清楚**——简单直接是行号 BASIC 的美德。

### 0x81.4 上机后的改造练习
跑通之后，别停——**改造是编程进步最快的方式**：

**改造 1**：限制 7 次机会，超限打印 `game over` 并公布答案。

> 提示：加 `if c >= 7 then win = 1`（旗子换个含义：结束），循环后再分支打印是赢是输。参考：
>
> ```basic
> 10 n = rnd(1, 100)
> 20 c = 0
> 30 win = 0
> 40 print "== guess 1-100, 7 tries =="
> 50 while win = 0
> 60   print "your guess:"
> 70   input g
> 80   c = c + 1
> 90   if g = n then win = 1
> 100  if c >= 7 then win = 2
> 110  if g < n then print "try bigger"
> 120  if g > n then print "try smaller"
> 130 wend
> 140 if win = 1 then print "correct! tries="; c
> 150 if win = 2 then print "game over, n="; n
> 160 end
> ```
>
> （win 从"旗子"升级成"结果码"：1 赢 2 输——状态多起来就用数字编码，好习惯。）

**改造 2**：距离提示——差 5 以内提示 `hot!`，否则按远近提示。

> 提示：`d = abs(g - n)`；`if d <= 5 then print "hot!"` 放在三个 if 之后再判断。

**改造 3**：用 gosub 把"问一轮"提成子程序，主循环瘦身。

> 提示：变量全局共享，子程序里直接改 g、c、win 都生效。

### 本章小结

- 随机出题：`rnd(1, 100)`。
- 旗子变量控制 while：`while win = 0`。
- "中了"的消息放循环外，只说一次。
- 结果一多，旗子升级为结果码。
- 学完项目必改造——改的过程才是长本事的过程。

---

**彩蛋挑战 C3：快枪手认证**

挑战规则：基于 0x81.4 的"7 次机会"版猜数字，加一条隐藏成就：**3 次以内猜中**，额外打印一行彩蛋台词；否则只打印普通战绩。

参考思路（先自己想，卡住了再看）：

```basic
10 n = rnd(1, 100)
20 c = 0
30 win = 0
40 print "== guess 1-100, 7 tries =="
50 while win = 0
60   print "your guess:"
70   input g
80   c = c + 1
90   if g = n then win = 1
100  if c >= 7 then win = 2
110  if g < n then print "try bigger"
120  if g > n then print "try smaller"
130 wend
140 if win = 1 then print "correct! tries="; c
150 if win = 2 then print "game over, n="; n
160 if (win = 1) and (c <= 3) then print "fast hands! secret rank unlocked"
170 end
```

关键在 160 行：赢 + 次数少，两个条件同时成立才触发隐藏台词。挑战成功：你已经会用"组合条件"给程序藏私货了——以后给朋友的程序里塞彩蛋，靠的就是这一手。

---

## 0x82 综合项目二：屏幕保护——弹跳球加星空
你好！毕业项目二：做一个**屏保动画**——深蓝夜空里星星闪烁，一颗黄球满屏弹跳。这是0x41 弹跳球的豪华版，学会"多层画面"的组织方式。

### 0x82.1 设计拆解
画面分两层：

- **背景层**：每帧撒 30 颗随机星星（白点 pixel）。
- **前景层**：1 颗弹跳球（黄圆）。

每帧的工序：**清屏 → 画星星 → 画球 → 更新球位置 → 撞墙检查 → 延时**。这个"工序清单"就是主循环体——先列清单再写码，依然是好习惯。

### 0x82.2 完整程序
```basic
10 x = 20
20 y = 20
30 dx = 3
40 dy = 2
50 s = 0
60 while 1
70   clear
80   color 200, 200, 200
90   for i = 1 to 30
100    pixel rnd(0, 479), rnd(0, 319)
110  next i
120  color 255, 220, 0
130  circle x, y, 5
140  x = x + dx
150  y = y + dy
160  if x > 475 then dx = 0 - dx
170  if x < 5 then dx = 0 - dx
180  if y > 315 then dy = 0 - dy
190  if y < 5 then dy = 0 - dy
200  wait(50)
220 wend
230 end
```

### 0x82.3 讲解与细节
- **70 行 clear**：每帧全清——星星每帧重撒（位置每帧随机变），产生"星星闪烁"效果，一举两得。
- **80~110 行**：灰色画笔撒 30 颗星。坐标用 `rnd(0, 479)` / `rnd(0, 319)` 落在整个屏幕——`rnd(a, b)` 从 0 开始一样好使。
- **120~130 行**：黄色画球。**画笔颜色管理**：每层画前先 color，层次感靠颜色切换。
- **140~190 行**：位置更新 + 撞墙调头，0x41 原封不动搬来——**写好的骨架就该这么复用**。
- **200 行 wait**：每帧延时。嫌快改大、嫌慢改小。
- **50 行的 s**：留了个计次器没用——改造练习会用到，先占位。

### 0x82.4 上机后的改造练习
**改造 1**：球带"运动轨迹残影"——不清屏，改用黑 fill 在旧位置抹掉球再画新位置。

> 提示：把 clear 换成 `color 0,0,0 : fill x - 6, y - 6, 12, 12`（抹旧），但星星就不能重撒了——改成开场撒一次星星、之后只抹球画球。参考思路：
>
> ```basic
> 60 color 200, 200, 200
> 70 for i = 1 to 30
> 80   pixel rnd(0, 479), rnd(0, 319)
> 90 next i
> 100 while 1
> 110   color 0, 0, 0
> 120   fill x - 6, y - 6, 12, 12
> 130   color 255, 220, 0
> 140   circle x, y, 5
> 150   x = x + dx
> ...(后续同前)
> ```
>
> （先撒星后进循环——循环外只干一次的事就放循环外。）

**改造 2**：加第二颗球（红），两球独立速度独立弹跳。

> 提示：再开 x2、y2、dx2、dy2 四个变量，同款两行更新 + 四行撞墙。变量一多你会发现"起名的艺术"——s1、b1x、b2x 这类前缀命名这时候开始有用了。

**改造 3**：用上 50 行的 s——每 100 帧换一次球色（比如按 s 轮换三色）。

> 提示：s = s + 1 每帧加一；`if s mod 300 < 100 then color 255,220,0 else if s mod 300 < 200 then ...`（0x12.7 的 mod，正数取余随被除数符号，正好轮换）。

### 本章小结

- 多层画面 = 每帧按"背景 → 前景"顺序画。
- 每帧重撒随机星 = 闪烁特效（清屏的副产品利用）。
- 局部重绘（抹旧画新）替代全屏 clear，是动画进阶技法。
- 变量多起来，前缀命名（b1x、b2x）救你的命。

---

## 0x83 综合项目三：网络小报
你好！毕业项目三：**网络小报**——连上 WiFi，从服务器拉一段今日小报文本，屏幕排版显示；断网、坏接口都有体面的处理。这是0x61 的毕业考，也是将来"畅聊"客户端的雏形。

### 0x83.1 设计拆解
工序清单：

1. 连 WiFi（带计数超时）；
2. httpget 拉文本；
3. httpstat 验货（非 200 报错退出）；
4. 把响应体排版画到屏幕（text 分行）；
5. 结束。

三个出口：超时、HTTP 错、成功——每个出口都要"体面"（有提示、能收尾），这是职业程序和练习程序的分水岭。

### 0x83.2 完整程序
```basic
10 print "waiting wifi..."
20 t = 0
30 while wifistat() = 0
40   t = t + 1
50   if t > 50000 then print "wifi timeout" : end
60 wend
70 httpget "http://192.168.1.100/news.txt", r$
80 if httpstat() <> 200 then print "http err "; httpstat() : end
90 color 0, 255, 120
100 clear
110 text 10, 10, "== DAILY =="
120 text 10, 40, left$(r$, 30)
130 text 10, 60, mid$(r$, 31, 30)
140 text 10, 80, mid$(r$, 61, 30)
150 text 10, 120, "done."
160 end
```

### 0x83.3 讲解与细节
- **10 行**：先打提示再等网——凡是要等的操作，先告诉用户"在忙"，别让人以为死机。这条叫"**别让用户干等**"原则。
- **20~60 行**：计数超时等连接（0x22 骨架第三次上岗）。WiFi 由系统设置连好，程序只等 `wifistat()` 变 1。**骨架复用率是检验你学没学会的标尺**。
- **80 行**：验货。`<> 200` 不对劲就报错码退出——错误码显示出来，排查时省一大截（是 404 还是 0？故事完全不同）。
- **110~140 行**：排版。响应体 r$ 当"30 字符一行"的报纸切三行显示。left$ 切首行、mid$ 切后续——0x31 切片三兄弟全部到场。切片按**字符**，中文也不会切出半个字。

### 0x83.4 上机后的改造练习
**改造 1**：失败重试 3 次——把 httpget + 验货包成子程序，主流程 for 3 次调用。

> 提示：子程序里判断成功就设旗子 ok=1，主循环查旗子决定停不停。

**改造 2**：屏报轮播——拉回来的文本 10 秒一换行滚动。

> 提示：切片起点从 1、31、61 往后推，用变量 p 控制：`text 10, 40, mid$(r$, p, 30)`；p = p + 30，外层 while 1 + `wait(100)`；p 超过 len(r$) 就归 1。

**改造 3**（思考题）：把小报升级成"留言板"：掌机用 httppost 发一句话、httpget 拉全部留言显示。想想：服务器需要哪些接口？发的话怎么带上你的名字？（串拼接 `n$ + ": " + msg$`。）——想完这个，你就已经设计出"畅聊"的掌机端原型了。它正是下一个大工程：多端聊天应用"畅聊"的起点。

### 本章小结

- 网络程序三个体面出口：超时、HTTP 错、成功。
- 先提示再等待；错误码要显示出来。
- 文本排版 = left$/mid$ 按行宽切片（按字符切，中文安全）。
- 发 + 拉 = 聊天应用的原型。

> **彩蛋 E21：三个项目其实是一条路**
> 回头看：0x81 猜数字练的是**逻辑**（分支 + 循环 + 随机），0x82 屏保练的是**画面**（坐标 + 动画 + 分层），0x83 小报练的是**联网**（状态 + 文本 + 排版）。逻辑、画面、网络——这三个词，其实就是"做一个能用的东西"的全部零件。你将来做的每一个正经程序（包括传闻中那款叫"畅聊"的聊天应用），拆开看，都只是这三样在组合。17 章学完的你，已经不是"会抄代码的人"，是"会拆程序的人"了——这俩差别很大。

**毕业了。** 17 章，你从 `print "hello"` 走到了联网客户端。接下来没有教材了——去写你自己的程序吧。卡住了就回翻对应章节，或者翻附录。祝玩得开心。

**给未来某天的你**：如果有一天你翻回这本书，看到这里——那时候的你应该已经写出了很多自己的东西。这本书里教的每一条，都是当时的机器能给你的全部；而你后来会的那些，是你在它上面长出来的。机器会换代，BASIC 会老，但"从不懂到理解，从理解到成为"这条路不会。你走过的每一步，都算数。

---

## 附录 A：语句总表

### 标准核心

| 语句 | 写法 | 说明 |
|---|---|---|
| print | `print "sum=";s` | 输出；`;` 紧排、`,` 分开排 |
| let | `let x = 10` / `x = 10` | 赋值；let 可省 |
| input | `input x` / `input a$` | 数值摇杆调、字符串键盘敲 |
| if..then..else | `if x>0 then print "p" else print "n"` | 独占一行；then 后纯数字=跳转 |
| for..next | `for i=1 to 10 step 2` ... `next i` | 计数循环；step 默认 1；可嵌套 |
| while..wend | `while x<3` ... `wend` | 条件循环；可嵌套 |
| goto | `goto 100` | 无条件跳转（半禁用，每轮提示） |
| gosub/return | `gosub 500` ... `return` | 子程序；栈式可嵌套 |
| end | `end` | 结束程序 |
| system | `system "reboot"` | 重启 |
| include | `include "lib.bas"` | 编译期合并，同号覆盖 |

### 绘图（屏幕 480×320，原点左上）

| 语句 | 写法 | 说明 |
|---|---|---|
| color | `color 255,0,0` | 前景色 R,G,B（0~255） |
| clear | `clear` | 清屏（黑） |
| text | `text 10,20,"hello"` | (x,y) 画文本 |
| pixel | `pixel 5,5` | 画 1 像素 |
| line | `line 0,0,100,50` | 线段 |
| rect | `rect 10,10,50,30` | 矩形边框（宽 w 高 h） |
| fill | `fill 10,10,50,30` | 实心矩形 |
| circle | `circle 120,80,40` | 圆框（圆心，半径） |

### GUI 控件（APP 模式，basic_host 宿主）

| 语句 | 写法 | 说明 |
|---|---|---|
| win | `win 20,10,280,60,"menu"` | 面板窗口（深色底+标题条），最多 8 个 |
| list | `list 20,80,280,120` | 开列表区 |
| ladd | `ladd "hello"` | 列表加一行（超宽自动换行，最多 300 行） |
| lclr | `lclr` | 清空列表 |
| lscr | `lscr 1` | 列表滚动 n 行（-1 往上） |
| btn | `btn 20,210,130,30,"ok"` | 按钮，最多 8 个 |
| bsel | `bsel 0` / `bsel -1` | 按钮焦点（黄框高亮；-1 取消） |
| bkey(i) | `k = bkey(0)` | **按钮点击事件**：焦点按钮被"按下"（Enter/摇杆确认）为 1，读后清零 |
| lbl | `lbl 1,20,260,"score: 0"` | **文本控件** id 化：最多 16 个，同 id 覆盖更新；可选样式 0/1/2（正常/反白/粗体） |
| llbl | `llbl 1,"score: 5"` | 只改文本控件内容（可带样式参数） |
| lbld | `lbld 1` | 删除文本控件 |
| img | `img 5,10,10` | 内置图标 0~7（电池/WiFi/音符/文件夹/齿轮/星/心/右箭头），当前色 |
| after | `after 3000,500` | **非阻塞定时**：3000ms 后跳行号 500（一次性；阻塞语句期间不触发） |
| inputat | `inputat 10,200,300,40` | `input a$` 录入框位置（默认屏幕下方） |
| key() | `k = key()` | 非阻塞读键（见函数表） |
| delay | `delay 100` | 等待毫秒（1~60000） |
| wait | `wait(150)` | 等待 150 毫秒（参数以毫秒计，1~60000） |

> `text` 支持第 4 参样式：`text x,y,"文字",1` 反白（彩底黑字）、`2` 粗体；`lbl` 同理第 5 参。

### 连接 / 网络 / 语音 / 硬件

| 语句 | 写法 | 说明 |
|---|---|---|
| wifi | （保留兼容，程序不直接调用） | WiFi 由**系统设置**统一管理；程序读环境变量 `wifi_ssid$`/`wifi_pass$`/`ap_ssid$`/`ap_pass$`/`ble_name$`，状态查 `wifistat()` |
| uart | `uart "text"` | 输出到 USB 串口调试台 |
| ble | `ble "text"` | 蓝牙透传发送（上位机需已连） |
| httpget | `httpget "http://a/p", r$` | GET，响应存 r$（当前 ≤8KB） |
| httppost | `httppost "http://a/u", b$, r$` | POST，b$ 原样上传 |
| httpup | `httpup "http://a/u", "/mem_fat/f.bin", r$` | 上传本地文件（HTTP POST 文件字节） |
| httpdl | `httpdl "http://a/f.bin", "/mem_fat/f.bin"` | 下载文件存本地 |
| record | `record "/mem_fat/v.wav", 5` | 录 WAV（16kHz 单声道 16bit），阻塞 1~60 秒 |
| play | `play "/mem_fat/v.wav"` | 放 WAV/MP3（后台） |

## 附录 B：函数总表

### 数学

| 函数 | 说明 |
|---|---|
| `sin(x)` `cos(x)` `tan(x)` | 三角（**弧度**） |
| `abs(x)` | 绝对值 |
| `sqr(x)` | 平方根 |
| `int(x)` | 取整（朝零截断） |
| `log(x)` `log10(x)` | 自然对数 / 常用对数 |
| `exp(x)` | e^x |
| `pow(a,b)` | 幂（两参数；不支持 `^`） |
| `rnd()` | 随机小数 0~1（真随机，硬件熵源） |
| `rnd(n)` | 1~n 的随机整数（含两端） |
| `rnd(a,b)` | a~b 的随机整数（含两端，a>b 自动交换） |

### 字符串

| 函数 | 说明 |
|---|---|
| `str$(x)` | 数→文（拼接前必转） |
| `val(s$)` | 文→数（非数字返 0） |
| `len(s$)` | 字符数（汉字算 1） |
| `left$(s$, n)` | 左 n 字符 |
| `right$(s$, n)` | 右 n 字符 |
| `mid$(s$, start, len)` | 子串，start 从 1 计（按字符） |
| `chr$(n)` | 0~255 → 单字符（无反向函数） |

### 系统注入

| 函数 | 说明 |
|---|---|
| `wifistat()` | WiFi 状态 1/0 |
| `httpstat()` | 上次 HTTP 状态码（0=没请求/没连上） |
| `gpioin(n)` | 读 GPIO 电平 0/1 |
| `key()` | 非阻塞读按键码，0=没按（APP 模式） |

## 附录 C：保护机制

| 机制 | 说明 |
|---|---|
| 步数上限 | 默认 100000 步，超限强制终止，输出"超时保护" |
| 跳转语义 | goto/gosub/return/循环跳转后，目标行真正被执行 |
| 包校验 | .msp 安装时 CRC32 校验，损坏包拒绝落盘 |
| 行长 | 每行上限 96 字节（UTF-8，约 32 汉字） |
| goto 提示 | 每轮运行提示一次注意事项 |

## 附录 D：已知边界（写程序前必读）

- **字符串与数字不混算**：`str$` / `val` 过海关。
- **新固件有、本书暂不展开**：数组 `dim`、自定义函数 `def fn`/`fnret`、`data`/`read`、文件读写 `fread`/`fwrite`/`fappend`、多行 `if ... end if`、类型 `type`——完整语法见《Memoria BASIC 语言手册》（BASIC-LANGUAGE.md）。旧固件没有这些，老程序（和本书第一版）也见不到它们。
- **仍然没有**：`^` 幂符（用 `pow(a, b)`）、asc（字符→数字）、Instr（串查找）。注释有：行首 `rem` 整行忽略（0x72.2）。
- and/or/not 短路（左边定胜负，右边不算）；mod 与乘除同级（除 0 报错）；`rnd(a,b)` 整数含两端；`delay` 1~60000ms（APP 模式），PRGM 里延时用 `wait(毫秒)`。
- `input a$` 支持中文（自动调起拼音输入法，见 `docs/IME-SPEC.md`）；`input x` 摇杆调值；APP 模式可用 `inputat` 挪录入框位置。
- GUI 控件（win / btn / bsel / **bkey(i)** / list / ladd / lclr / lscr / **lbl / llbl / lbld** / **img** / **after** / inputat / delay / key()）仅 **APP 模式**（basic_host 宿主）可用，PRGM 模式没有。
- HTTP 仅明文 `http://`（HTTPS 后补），响应体 ≤8KB。
- record 单段 1~60 秒且阻塞；play 后台不阻塞。
- 变量名大小写不敏感（官方风格全小写）；行号唯一，同号覆盖。
- .bas 文件放 TF 卡 `/mem_fat/scripts/`，PRGM 模式运行；打包成 .msp 上架后按 APP 运行（有 GUI 加成）。

## 附录 E：从 .bas 到上架（软件链路）

```
BASIC 源码（.bas 文本）
    → 打包成 .msp 安装包（50 字节头 + 源码正文，CRC32 校验）
    → 上架 manifest.json（软件源清单）
    → STORE 商店下载安装到 /mem_fat/scripts/
    → PRGM 模式运行（解释执行）
```

你写的 .bas 就是程序本体；.msp 只是"信封"。想把自己程序分享给别人：打包上架，别人商店一按就装好。

## 附录 F：给会老 BASIC 的你

| 老 BASIC | Memoria BASIC |
|---|---|
| `10 PRINT "HI"` | `10 print "hi"`（全小写官方风格；大小写其实都认） |
| REM 注释 | `rem 说明文字`——行首整行忽略；配合好名字 + uart 打点 |
| DIM 数组 | 新固件有 `dim a(10)` / `dim a$(10)` / 二维（见语言手册）；串当背包是老固件/老程序的做法 |
| DEF FN 函数 | 新固件有 `def fn`（见语言手册）；老代码用 gosub 子程序（变量全局共享） |
| AND / OR / NOT | 内置关键字（短路）；老写法是乘 / 加 / 1 减，老程序里还见得到 |
| `^` 幂 | `pow(a, b)` |
| MOD | 内置 `x MOD n`；老写法 `x - int(x / n) * n` 兼容 |
| 多行 IF / ELSEIF | 新固件有 `if ... end if`（见语言手册）；老代码单行 if + 连环 if + then 数字跳转 |
| DATA / READ | 新固件有（见语言手册）；老代码把数据写死在变量里 |
| ON GOTO | 连环 if |
| 无硬件能力 | **大加成**：屏幕绘图 / WiFi / HTTP / 蓝牙 / 串口 / GPIO / 录放音 |

## 附录 G：彩蛋图鉴（收集用）

读完一章，回来在最后一列打勾。集齐 21 个彩蛋 + 3 个挑战，你就是这本书的"图书管理员"。

| 编号 | 位置 | 讲的是什么 | 一句话线索 | 已收集 |
|---|---|---|---|---|
| E01 | 0x01 行号 | 世界上第一只 bug | 继电器里的飞蛾 | ☐ |
| E02 | 0x02 变量 | 为什么叫"浮点" | 别用 = 比小数 | ☐ |
| E03 | 0x03 运算符 | 早期没有 and/or | 乘加逻辑的老写法 | ☐ |
| E04 | 0x03 运算符 | 真随机 | 芯片抓热噪声 | ☐ |
| E05 | 0x11 input | 最早的聊天程序 | ELIZA | ☐ |
| E06 | 0x12 if | AI 会"作弊" | 深蓝的一步棋 | ☐ |
| E07 | 0x21 for | 循环变量为什么叫 i | FORTRAN 的工号 | ☐ |
| E08 | 0x21 for | 高斯的快捷方式 | 首尾配对 101×50 | ☐ |
| E09 | 0x22 while | 电磁炉同款设计 | 干烧断电哲学 | ☐ |
| E10 | 0x31 字符串 | ASCII 是 1963 年的 | 大小写差 32 | ☐ |
| E11 | 0x41 绘图 | 直线的算法 | 1962 年的 Bresenham | ☐ |
| E12 | 0x61 网络 | 404 是房间号吗 | 都市传说 | ☐ |
| E13 | 0x62 声音 | 16kHz 是什么音质 | 电话是 8kHz | ☐ |
| E14 | 0x01 print | memoria 是拉丁词 | 记忆的意思 | ☐ |
| E15 | 0x31 字符串 | 串当背包的出处 | string packing | ☐ |
| E16 | 0x41 绘图 | 屏幕是长个子的 | 320×240 老坐标 | ☐ |
| E17 | 0x51 gosub | return 的记性本 | 栈 | ☐ |
| E18 | 0x61 网络 | 状态码是一套暗号 | 4 怪自己 5 怪对方 | ☐ |
| E19 | 0x71 硬件 | 重启是过劳疗法 | 关机睡一觉 | ☐ |
| E20 | 0x72 保命 | 为什么是十万步 | 放过正常人拦下疯子 | ☐ |
| E21 | 0x83 综合项目 | 三个项目是一条路 | 逻辑 · 画面 · 网络 | ☐ |
| C1 | 0x41 章末 | 秒表挑战 | 会走字的 lbl | ☐ |
| C2 | 0x61 章末 | 服务器的暗号 | 联网猜数字 | ☐ |
| C3 | 0x81 章末 | 快枪手认证 | 3 次以内有台词 | ☐ |

等级：**10 个 = 学徒**；**18 个 = 工匠**；**24 个全收集 = 图书管理员**。留言区写下你的通关感言吧（如果有留言区的话——没有就写给自己看）。

---

*本书 v4 校对版，与《Memoria BASIC 语言手册》（BASIC-LANGUAGE.md）配套：书负责教，手册负责查。语法以 `components/memoria_basic/` 解释器实现为准。*

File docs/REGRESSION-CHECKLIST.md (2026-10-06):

# Memoria BASIC 语法批次回归清单

> 目的：GLM 语法批次（A/B/C/D：rem/mod/and/or/not/rnd 范围/data-read/dim 数组/文件流/块 if/elseif/def fn/HTTP 1MB）落地后，全量回归 .bas 旧程序，确保"老 BASIC 语法不减"。
> 执行人：豆包-2（真机烧录 + 逐例跑）· 模拟器同步：豆包-1 · 批次交付：GLM
> 覆盖对象：**Memoria BASIC（.bas）**；`.ms`（memoria-script）是另一解释器，不受本批次影响。

## 0. 回归前置

- [ ] GLM 报语法批次落地（桥上报出 bin SHA + 语法清单确认）
- [ ] 烧录新固件到测试板（COM5）
- [ ] 每例跑 3 次：新语法程序 + 旧语法程序各一次，旧的不许炸

## 1. 教材核心示例（从 BASIC-BOOK.md 抽取）

| # | 覆盖语法 | 最小测试程序 | 预期 |
|---|---|---|---|
| T1 | print / 变量 / 算术 | `10 x = 3 : y = 4 : print x + y * 2 : end` | 打印 `11` |
| T2 | input x（摇杆） | 教材 4.1 门牌示例 | 摇杆输入生效 |
| T3 | input a$（含中文） | `10 input a$ : print "hi, "; a$ : end` | 键盘输入，中文拼音上屏，回车回显 |
| T4 | if / else / 多行 if | `10 if 5 > 3 then print "a" : else print "b" : end` | 打印 `a` |
| T5 | elseif 链 | 三分支示例 | 命中正确分支 |
| T6 | for / next | `10 for i = 1 to 5 : print i; : next i : end` | `1 2 3 4 5` |
| T7 | while / wend + 超时骨架 | 教材 7.5 | 等 wifistat 变 1 或超时退出 |
| T8 | len/left$/mid$（按字符） | `10 print len("好abc") : print mid$("你好世界", 2, 2) : end` | `4` / `好世`（不切半字） |
| T9 | val / str$ | `10 print val("42") + 1 : print str$(7) + "x" : end` | `43` / `7x` |
| T10 | 绘图 text/rect/circle | 教材 9 章弹跳球 | 画面正常，无异常退出 |
| T11 | gosub / return | `10 gosub 100 : end : 100 print "sub" : return` | 打印 `sub` |
| T12 | include | 两文件合并示例 | 合并运行，同号覆盖规则生效 |

## 2. 新语法专项（本批次新增，正向验证）

| # | 新语法 | 最小测试 | 预期 |
|---|---|---|---|
| N1 | rem 注释 | `10 rem 这是注释 : print "ok" : end` | 注释被忽略，打印 `ok` |
| N2 | mod | `10 print 17 mod 5 : end` | `2` |
| N3 | and / or / not | `10 if 1 = 1 and 2 = 2 then print "y" : end` | `y` |
| N4 | rnd 范围 | `10 print rnd(1, 6) : end` | 1~6 整数（多跑几次都在范围内） |
| N5 | data / read | data 表 + read 逐行读 | 数据按序读出 |
| N6 | dim 数组 | `dim a(10)` + 循环填读 | 赋值/读取正确 |
| N7 | 文件流 | 写文件 → 读回 | 内容一致 |
| N8 | def fn | `def fn double(x) = x * 2` + 调用 | 结果正确 |
| N9 | HTTP 大响应 | httpget 拉 >8KB 接口 | r$ 完整收到 1MB 内响应 |

## 3. 真机既有程序回归

| # | 程序 | 状态 | 预期 |
|---|---|---|---|
| R1 | `sdcard/scripts/chat.bas`（v1 旧客户端） | 待 GUI 替换 | 语法批次后仍可运行（走旧 GET 协议） |
| R2 | 商店安装的 .bas 程序 | 用户确认装了哪些 | 全部可运行 |
| R3 | 用户自写 .bas | 用户提供 | 可运行 |

## 4. 重点风险点（回归时优先盯）

1. **wifi 语句语义**：系统管网下是"保留兼容"，旧程序里残留 `wifi "ssid","pass"` 不许变成报错（教材已改，但旧 .bas 可能有）
2. **if 多行化**：新块 if 落地后，旧的单行 `if ... then ... else ...` 必须原语义不变（**else 同行优先**）
3. **len/切片按字符**：旧程序按字节切 3 的倍数的地方，行为变化是否可接受（结果变"正确"但可能和旧输出不同——需要用户确认口径）
4. **rnd() 无参**：必须仍返回 0~1（向后兼容），只有带参才走范围模式
5. **行长 96 字节**：新语法（rem/mod/def）别让示例超行长

## 5. 交付标准

- [ ] T1~T12 全绿（模拟器 + 真机）
- [ ] N1~N9 全绿（真机）
- [ ] R1~R3 无回归破坏
- [ ] 教材附录 D/F 同步更新（我负责，随批次落地走）

---

*清单随语法批次交付更新；跑挂一项即报 GLM 修，不静默通过。*

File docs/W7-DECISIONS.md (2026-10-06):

# Memoria OS · 用户决策项汇总（W7 收口）

> 2026-10-01 · 汇总：豆包-1 · 来源：三方源码审查（W4 GLM / W5 豆包-2 / W6+W6b 豆包-1）
> 这份是**需要你拍板的全部事项**。每条给背景 + 选项 + 推荐。你回个编号+选择就行，比如「1B 2A」。

---

## 执行状态速览（2026-10-01 更新）

| 编号 | 事项 | 你的拍板 | 执行状态 |
|---|---|---|---|
| 3 | 更新窗口用配置值 | ✅ 已拍（搞一下） | **已修 + build 全绿背书**（update_scheduler.cpp 去 hour<6 硬编码；bin 0x1d9270 12:48） |
| 4 | 到点自动连 WiFi | ✅ 已拍（搞一下） | **已修 + build 全绿背书**（WifiManager 新增 reconnect() + 等 10s；bin 0x1d9270） |
| 8 | 模式层 4 炸我修 | ✅ 已拍（你改上） | **已修 + build 全绿背书**（prgm LINE/CIRCLE + sys 自检 + notes 记事；bin 0x1d9270） |
| 13 | TF/SD 卡槽 | ✅ 已定：**TF 内置必有 + SD 外置拓展**（导照片不拔底槽 TF 卡） | 已记录，外壳建模按此预留：TF 内置底部 + SD 外置侧面卡槽（HARDWARE-DIMENSIONS 已更新） |
| 1/2/5/6/7 | 包更新其余行为 | 未拍 | 未动，见下方详情（看板 #60/#61/#66/#67/#69） |
| 9/10/11 | BLE/IME/脏矩形 | 未拍 | 未动（BLE/IME 已在 GLM 修复批中处理：ble nimble_port_run + ime [5]，收讫） |
| 12 | 3D 建模路线 | 未拍 | 待定 |

---

## 一、固件行为（W6b 包更新线，7 项）

### 1. check_updates 全量重下（#33）
- **背景**：现在每次更新检查，manifest 里所有包不管本地是不是最新，全部重新下载覆盖。注释自己写的"简化"。包多了浪费流量和 TF 寿命。
- **选项**：A) 按包名读本地 .msp 版本号，不一致才下（标准做法）；B) 保持全量重下（最省事，反正包小）。
- **推荐 A**。改动不大，我把版本比对逻辑加上就行。

### 2. TLS 跳过主机名校验（#34）
- **背景**：json_fetcher 把 HTTPS 证书主机名校验关了（只验证书链）。好处是 GitHub raw 那种 SAN 不全的地址也能连；坏处是中间人能劫持包更新线注入假包（OTA 固件线不受影响，只影响商店/脚本包）。
- **选项**：A) 恢复严格校验，镜像源换到证书规范的地址；B) 保持跳过，接受风险（自己玩的小机器，风险可控）；C) 白名单：只对配置的 mirror 域名跳过，其他严格。
- **推荐 B**（个人项目、本地镜像为主），等哪天要公开分发再收紧。选 B 的话这条直接关，不用改代码。

### 3. 自动更新窗口写死凌晨 2-5 点（#37）
- **背景**：update_scheduler 判断 `t.hour < 6` 才更新。你在界面上设 23 点 = 永远不触发。
- **选项**：A) 窗口改成用你配置的值；B) 删掉窗口判断，到点就更新；C) 保持现状，界面只允许设 0-5 点。
- **推荐 A**。一行改动。

### 4. 到点不自动连 WiFi（#38）
- **背景**：注释说"到点自动连"，实际没连——没 WiFi 就跳过，而且当天标了"已触发"不再重试。晚上自动更新基本永远失败。
- **选项**：A) 到点主动连 WiFi（有保存凭据时），失败再放弃当天；B) 保持现状（反正手动更新能用）。
- **推荐 A**。

### 5. manifest 缺 crc 字段（#41）
- **背景**：manifest 条目没有 crc 字段时 crc=0，包下载后 CRC 对不上全部拒装——一个字段缺失整个包装不上。
- **选项**：A) 缺 crc 就跳过校验直接装（信任镜像源）；B) 缺 crc 视为清单错误跳过该包；C) 保持现状（强制要求 manifest 带 crc）。
- **推荐 A**（个人镜像源可信，少一道折腾）。

### 6. manifest 字段顺序敏感（#42）
- **背景**：解析器要求 name 必须出现在 version 前面，顺序反了后面字段解析不全。
- **选项**：A) 改成按字段名独立扫描（顺序无关）；B) 保持现状，约定 manifest 固定格式。
- **推荐 A**。顺手的事，解析器本来就小。

### 7. json_find 解析限制（#44）
- **背景**：changelog 里带转义引号会被截断；固件清单 URL 拼接依赖 mirror 是"目录型"地址，换 TF 卡路径源时不适用。
- **选项**：A) 记个限制不改（反正 changelog 没人写转义引号）；B) 换用现成 JSON 解析库。
- **推荐 A**。为这俩边角功能引个库不值。

---

## 二、固件功能（W4/W5 移交，4 项）

### 8. 模式层 4 炸修复归属（#5/#6/#7/#8）
- **背景**：LINE 画俩点、CIRCLE 画方框、自检是假的、记事查看永远显示占位——这四个是上板前必修的用户可见功能错误。原议 GLM W4 顺手修，但他 W4 清单里没出现这四项，实际没修。
- **选项**：A) 我修（prgm_mode/sys_mode/notes_mode 归我 W6 范围）；B) 等 GLM W4 收尾补修。
- **推荐 A**。这四块本来就是我 W6 审出来的，修法我也写好了，直接落。

### 9. BLE 广播时序（#55）
- **背景**：BLE 广播启动时机不对，host 没同步时调用会静默失败 → 广播永远不出现。
- **选项**：A) 修（挂 sync_cb，标准姿势）；B) 先不修（真机验证时一起看）。
- **推荐 A**。但这条**需要真机验证**才敢说闭环，先修上、真机时验证。

### 10. IME 候选 emoji 越界（#60）
- **背景**：候选数组 [9][4] 放不下 4 字节 emoji，会越界写 1 字节。当前字库全 GB2312 3 字节，实际碰不到。
- **选项**：A) 顺手改成 [5]；B) 不动。
- **推荐 A**。一行。

### 11. 脏矩形推屏（#49）
- **背景**：整屏重绘 92ms，帧率上限 ~10fps，拖图标卡。改脏矩形局部推屏能流畅很多，但改动大、要上板验证。
- **选项**：A) 真机到手后做；B) 先不做（礼物机能跑就行）。
- **推荐 A**（真机验证时做，现在不动）。

---

## 三、硬件/交付（5 项）

### 12. 3D 建模路线
- **背景**：外壳要 3D 打印，你之前问过谁能帮你做模型。
- **选项**：A) 我按 HARDWARE-DIMENSIONS 标准先出一版可打印的 STL 工程方案（尺寸清单已有）；B) 你用 Fusion 360 / FreeCAD 自己拉；C) 找淘宝代建模（给尺寸清单对方出图）。
- **推荐 A 或 C**。A 我能把每个零件尺寸、层间距 2mm、排针/卡槽避让全部算好给你，但出可打印模型文件我这边没有 CAD 工具；C 是省事路线，你拿着尺寸清单对方半天出图。B 最省钱但你得学软件。

### 13. TF 卡槽与 SD 卡槽尺寸（延续之前问题）
- **背景**：外壳要为 TF 卡槽和 SD 卡槽留 3D 打印空位。
- **已定**：TF 卡槽侧缝 ≥13×2mm、卡外露 ≥4mm 可拆卸设计已就位（HARDWARE-DIMENSIONS v7）。SD 大卡槽（如果你还要插标准 SD）高度：卡座 + 板厚 + 层间距，标准 MicroSD 卡座高约 1.5mm，全尺寸 SD 卡座高约 1.8-2.1mm，加上你定的 2mm 层间距和板厚，建议预留 **4.5-5mm 高 × 14mm 宽 × 卡长+5mm 深**。
- **问题**：你到底用 TF（MicroSD）还是标准 SD？这决定卡槽尺寸。

### 14. .m4a 演示素材
- **背景**：解码线全绿，但真机测试音频素材没有（本机外网下载被掐）。
- **选项**：A) 你拷一首 .m4a 到 TF 卡 /audio/；B) 我生成一个测试音源文件给你拷。
- **推荐 A**（你真机本来就要拷字库，顺手拷歌）。

### 15. README 人情味版本（GLM W2 已完成）
- **已交付**：README v2 已含新引脚表 + 人情味叙事（human-story.md 素材已用）。这条已闭环，不用你决策，只是告知。

### 16. 键盘/摇杆/核心板定版
- **已定**：键盘 2× MCP23017（TCA8418 弃用）、摇杆 KY-023 甲案（整机约 40mm）、ESP32 S3-Zero 核心板带排针底板（裸模组弃用）。已闭环，告知即可。

---

## 四、已闭环（不需要你动的，简报）

- 引脚迁移 7 处（摇杆/电池/TF/I2S）——双 AI build 背书 ✅
- Z1 死锁 / X1 队列化 / X2 背光（GLM W4 三修）——build 全绿 ✅
- ADC1 共享句柄（battery_adc + joystick 冲突）——已修 ✅
- 解码线 7 处（AAC 语义/MP4 三修/seek/短读）——GLM build 编过，豆包-2 复跑背书进行中 ✅
- 我的 12 处修复（BASIC×3 + STORE×2 + package×7）+ 5 处后续（4 炸 + update_scheduler/wifi_manager）——**全部 build 全绿背书（bin 0x1d9270，豆包-2 同 bin 互证）✅**
- 字库 TF 化、BOM、外壳尺寸标准 v7 ✅

---

## 决策速答表（回这个就行）

| 编号 | 事项 | 我推荐 | 你的选择 |
|---|---|---|---|
| 1 | 全量重下改版本比对 | A | |
| 2 | TLS 跳过校验 | B | |
| 3 | 更新窗口用配置值 | A | |
| 4 | 到点自动连 WiFi | A | |
| 5 | 缺 crc 跳过校验 | A | |
| 6 | manifest 顺序无关 | A | |
| 7 | json_find 限制不改 | A | |
| 8 | 模式层 4 炸我修 | A | |
| 9 | BLE 时序修 | A | |
| 10 | IME emoji 改 [5] | A | |
| 11 | 脏矩形真机后做 | A | |
| 12 | 3D 建模路线 | A/C | |
| 13 | TF 还是 SD 卡 | ? | |
| 14 | .m4a 素材你拷 | A | |

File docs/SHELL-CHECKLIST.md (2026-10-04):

# 外壳一版过校验清单

> @brief 3D 外壳一次打印成活校验表。设计照表画，送打前照表查。
> 原则：**结构按 v10 推算值定死，数字等实测改**；打印周期长（外部代打），重打成本高，一切以一版过为目标。

## 一、公差铁律（画壳时直接套）

| 类型 | 规则 | 说明 |
|---|---|---|
| 通孔（螺丝/按键/USB） | 标称 **+0.3mm** | FDM 孔收缩，宁大勿小 |
| 卡槽/内腔 | 标称 **+0.2mm** | 模块塞入侧单边留 0.1 |
| 装配缝隙（面壳↔底壳） | **0.2mm** 避让 | 防打印毛边咬死 |
| 卡扣 | **-0.1mm**（过盈） | 卡扣靠弹性，松了没用 |
| 层间悬空 | **2mm**（不含隔板壁厚） | 项目既定铁律 |
| 壁厚 | ≥2mm，加强筋另加 | 太薄必翘 |

## 二、开孔/卡位清单（设计必查项）

| # | 部位 | 推算值（v10） | 公差后尺寸 | 实测改数 | 状态 |
|---|---|---|---|---|---|
| 1 | 屏幕可视窗 | 见 HARDWARE-DIMENSIONS v10 | =实测可视区+0.3 | ☐ | 待实测 |
| 2 | USB-C 开孔 | 口高 3.2mm（短边朝上受层间隙限制） | +0.3 | ☐ | 朝向待板定 |
| 3 | 摇杆穿顶孔（甲案） | 摇杆帽直径见 BOM（KY-023） | +0.3 | ☐ | 待实测帽径 |
| 4 | 喇叭出声孔 | 喇叭直径见 BOM | 阵列孔按实测+0.3 | ☐ | 待实测 |
| 5 | 电池仓内腔 | 电池厚/宽见 BOM | +0.2 | ☐ | 待实测厚度 |
| 6 | TF 卡换卡口 | TF 卡槽位（spi 本版 10/17） | 手指宽 ≥12mm | ☐ | 结构定值 |
| 7 | 电源/复位键位 | GPIO0/复位位置见 WIRING | +0.3 | ☐ | 待实测 |
| 8 | 60 键键盘面 | MCP23017 方案键距定版 | 键帽+0.3 | ☐ | 键距已定版 |
| 9 | UART 烧录口 | 43/44 排针避让（USB-C 备用） | +0.3 | ☐ | 结构定值 |
| 10 | 天线净空区 | 模组天线端 15×5mm，周 5mm 禁金属 | 腔体开天窗 | ☐ | 已定版铁律 |

## 三、送打前最后一遍（缺一不发）

- ☐ 全部孔位对照实模块比过（或纸模 1:1 比过）
- ☐ 小样试打完成：四角卡扣 + USB-C 开孔条 + 摇杆帽
- ☐ 上表 1~10 实测改数全部落实（无一留"推算"状态）
- ☐ 卡扣方向一致（都从内侧勾，别一半里一半外）
- ☐ 装配顺序心里过一遍：哪层先进、哪颗螺丝后锁
- ☐ 导出 STL 用 verify_stl.py 过校验（流形/法线/尺寸）

## 四、实测当天流程（~10-15 料到）

1. 卡尺量：屏可视区 / 喇叭 / 摇杆帽 / 电池厚（§二标记 ☐ 项）
2. 对照本清单改数（只改数字，结构不动）
3. 纸模比一遍关键孔位
4. 定稿 → 发同学打印
5. 等件期间：焊板（互不阻塞）

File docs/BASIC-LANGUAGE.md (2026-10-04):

# Memoria BASIC 语言手册

> 版本：v1.5（新增：httpup/httpdl 文件收发语句——掌机语音全链路，见 §5.3；随下版固件编译发布）· 解释器源码：`components/memoria_basic/`
> 用途：第三方开发者给 Memoria OS 应用商店写程序时的语法参考。
> **官方风格：关键字全小写**。解释器大小写不敏感（`print` 与 `PRINT` 等价），本手册与官方示例一律用小写。

## 1. 软件本质：一条链看懂

```
BASIC 源码（.bas 文本）
    → 打包成 .msp 安装包（payload = 源码文本）
    → 上架 manifest.json（软件源清单）
    → STORE 商店下载安装到 /mem_fat/scripts/
    → PRGM 模式运行（解释执行）
```

- **程序 = BASIC 源码**。安装包 .msp 只是"信封"：50 字节头（魔数/包名/版本/CRC）+ 源码正文。
- 全部语法能力 = 本手册；硬件能力（屏幕/WiFi/GPIO/串口/蓝牙）由系统注入，见 §5。

## 2. 程序形态

| 规则 | 说明 |
|---|---|
| 行号 | 每行以行号开头：`10 print "hi"`。经典行号 BASIC，行号决定执行顺序 |
| 行号步进 | 编辑器自动 +10（10, 20, 30...），便于中间插行 |
| 多语句同行 | 用 `:` 分隔：`10 x=1 : print x` |
| IF 独占整行 | if 后不能跟 `:` 续其他语句（then/else 体内可以多语句，见 §3） |
| 变量 | 数值型（double）与字符串型（`a$` 经典 $ 变量，**原生存中文**：`let a$ = "你好"`、`print a$` 直接可用，串函数按"字"处理见 §4.4）。变量名大小写不敏感（`a$` 与 `A$` 同一变量，风格用小写） |
| 关键字 | 大小写不敏感；官方风格全小写：`print let input if then else for next while wend goto gosub return end system include` |
| 单行长度 | 上限 96 字节（UTF-8，约 32 个汉字） |
| 文件存放 | TF 卡 `/mem_fat/scripts/*.bas` |

## 3. 语句总表（标准核心）

| 语句 | 写法 | 说明 |
|---|---|---|
| print | `10 print "sum=";s` | 输出。分号 `;` / 逗号 `,` 混合分隔；字符串字面量、串变量与表达式混排 |
| let | `10 let x = 10` / `10 let a$ = "hi"` | 赋值。`let` 前缀必须带边界（`letx` 会被拒）；**let 可省**：裸赋值 `x=5`、`a$="hi"` 合法 |
| input | `10 input x` / `10 input a$` | 读数值：摇杆上/下 ±1、左/右 ±10、按下确认；读字符串：键盘英文录入、Enter 确认 |
| if..then..else | `10 if x>0 then print "p" else print "n"` | 条件分支。**then 后跟纯数字 = goto 该行**；否则按语句执行（可多语句） |
| for..next | `10 for i=1 to 10 step 2` ... `50 next i` | 计数循环。step 可省略（默认 1）。支持嵌套 |
| while..wend | `10 while x<3` ... `30 wend` | 条件循环。支持嵌套 |
| goto | `10 goto 100` | 无条件跳转。**半禁用**：每轮运行提示一次注意事项（易死循环/逻辑混乱） |
| gosub / return | `10 gosub 500` ... `500 return` | 子程序调用/返回（栈式，可嵌套） |
| end | `10 end` | 结束程序 |
| system | `10 system "reboot"` | 系统动作，当前支持 `"reboot"` 重启 |
| include | `10 include "lib.bas"` | 编译期合并另一文件的全部行（同号覆盖）。适合公共库 |

## 4. 表达式与内置函数

### 4.1 运算符

| 类别 | 运算符 |
|---|---|
| 算术 | `+` `-` `*` `/` |
| 比较 | `=` `<>` `<` `>` `<=` `>=` |
| 逻辑 | 无专用关键字——用算术组合：`if (a>0)*(b>0) then`（非 0 即真） |

### 4.2 条件真值

条件表达式**非 0 即真**（数值条件）。`if x then` 合法。

字符串比较：任一侧是串变量/串字面量即按字符串比较（`if a$="hi" then`；`> < >= <=` 按字节序）。

### 4.3 数学函数

| 函数 | 说明 |
|---|---|
| `sin(x)` `cos(x)` `tan(x)` | 三角（弧度） |
| `abs(x)` | 绝对值 |
| `sqr(x)` | 平方根 |
| `int(x)` | 取整（截断） |
| `log(x)` `log10(x)` | 自然对数 / 常用对数 |
| `exp(x)` | e^x |
| `pow(a,b)` | a 的 b 次幂（必须两参数） |
| `rnd()` | 随机数，0 ~ 1 |

### 4.4 字符串函数

| 函数 | 说明 |
|---|---|
| `str$(x)` | 数值 → 文本（如 `str$(12.5)` → `"12.5"`） |
| `val(s$)` | 文本 → 数值（非数字文本返回 0） |
| `len(s$)` | 按**字符数**计数（UTF-8 感知：`len("你好")` = 2，纯英文 = 字节数，老程序零差异） |
| `left$(s$, n)` | 左 n 个**字符**（按字符边界切，绝不切断汉字） |
| `right$(s$, n)` | 右 n 个**字符** |
| `mid$(s$, start, len)` | 取子串，start/len 均按**字符**计，start 从 1 计 |
| `chr$(n)` | 0~255 数值 → 单字节字符 |

**中文即字符串**：不做独立汉字类型——`let a$ = "你好"`、`input a$`（自动调起输入法）、`print a$`、串函数按字处理，与英文写法完全一致（内部 UTF-8 存储，TF 卡/HTTP 链路零转换）。老程序只含英文时字符=字节，行为不变。

字符串运算：`+` 拼接；`= <>` 比较。**字符串与数字不混算**——拼接前先 `str$(x)`。

## 5. 硬件扩展 API（系统注入，掌机专属）

### 5.1 屏幕绘图语句

| 语句 | 写法 | 说明 |
|---|---|---|
| color | `10 color 255,0,0` | 设置前景色（R,G,B 各 0~255） |
| clear | `10 clear` | 清屏（黑） |
| text | `10 text 10,20,"hello"` | 在 (x,y) 画文本（当前色） |
| pixel | `10 pixel 5,5` | 画 1 像素点 |
| line | `10 line 0,0,100,50` | 画线段（Bresenham） |
| rect | `10 rect 10,10,50,30` | 画矩形边框（宽 w 高 h） |
| fill | `10 fill 10,10,50,30` | 画实心矩形 |
| circle | `10 circle 120,80,40` | 画圆（中点算法） |

屏幕分辨率 320×240，左上角为原点。

### 5.2 连接与系统

**网络是系统级的**：WiFi / AP 热点 / 蓝牙统一在系统设置里管理（设置中提供像手机一样的 WiFi 扫描列表点选连接、AP 热点名称密码自定义、蓝牙开关），程序不允许（也不需要）自己切网。系统连网后自动把当前网络信息预注入为 BASIC 全局变量：

| 预注入变量 | 说明 |
|---|---|
| `wifi_ssid$` / `wifi_pass$` | 系统当前连接的 WiFi（系统设置中扫描选择） |
| `ap_ssid$` / `ap_pass$` | 系统开出的 AP 热点（系统设置中自定义名称密码） |
| `ble_name$` | 蓝牙名称（系统设置中配置） |

- 变量名大小写不敏感，程序直接读取即可；值随系统连接状态自动更新。
- `wifistat()` 返回系统网络状态，程序用它判断在线与否。

| 语句/函数 | 写法 | 说明 |
|---|---|---|
| wifi | `10 wifi "ssid","pass"` | **保留语句（兼容旧程序），联网程序禁止调用**——系统统一管网，调用会被忽略并提示 |
| wifistat() | `10 x = wifistat()` | 返回 1（系统已连网）/ 0 |
| gpioin() | `10 x = gpioin(4)` | 读 GPIO 电平（0/1），参数为引脚号 |
| uart | `10 uart "text"` | 输出到串口控制台（USB 调试口可见） |
| ble | `10 ble "text"` | 蓝牙透传发送（需上位机已连接） |
| system | `10 system "reboot"` | 重启 |

### 5.3 网络与语音（联网应用）

| 语句/函数 | 写法 | 说明 |
|---|---|---|
| httpget | `10 httpget "http://a/p", r$` | GET 请求，响应体存入 r$（上限 8KB） |
| httppost | `10 httppost "http://a/u", b$, r$` | POST 请求，b$ 原样字节上传（octet-stream），响应体存 r$ |
| httpup | `10 httpup u$, "/mem_fat/v.wav", r$` | POST 文件字节上传（≤2MB octet-stream），响应体存 r$（第三参可省） |
| httpdl | `10 httpdl u$, "/mem_fat/v.wav"` | GET 下载直写文件（流式不占内存），配 httpstat() 判定 |
| httpstat() | `10 s = httpstat()` | 上一次 HTTP 状态码（0 = 未请求/连接失败） |
| record | `10 record "/mem_fat/v1.wav", 5` | 麦克录音到 WAV（16kHz 单声道 16bit），阻塞 1~60 秒 |
| play | `10 play "/mem_fat/v1.wav"` | 播放 WAV/MP3（后台播放，不阻塞） |

HTTP 目前仅明文 http://（HTTPS 后补）。

## 6. 保护机制

| 机制 | 说明 |
|---|---|
| 步数上限 | 默认 100000 步，超限强制终止（防死循环"杀线程"），输出"超时保护" |
| 跳转语义 | goto/gosub/return/循环跳转后不再自动前进一行，目标行真正被执行 |
| 包校验 | .msp 安装时 CRC32 校验，损坏/被篡改的包拒绝落盘运行 |

## 7. 最小示例

```basic
10 color 0, 255, 0
20 clear
30 for i = 1 to 5
40   text 10, i*20, "memoria os"
50 next i
60 let s = 0
70 for i = 1 to 100
80   let s = s + i
90 next i
100 print "sum="; s
110 if wifistat() then print "wifi ok" else print "wifi off"
120 end
```

联网 + 语音示例（网络由系统管理，程序开机即在线）：

```basic
10 color 0, 255, 0
20 clear
30 if wifistat() = 0 then print "wifi 未连,去系统设置连网" : end
40 print "当前WiFi: "; wifi_ssid$
50 httpget "http://host/api/hello", r$
60 if httpstat() = 200 then print r$ else print "http 错误 "; httpstat()
70 record "/mem_fat/v1.wav", 3
80 play "/mem_fat/v1.wav"
90 end
```

## 8. 已知边界（写程序时避开）

- 字符串与数字不混算：数字转文本用 `str$(x)`，文本转数字用 `val(s$)`。
- **没有数组**、没有自定义函数（def fn）、没有 rem 注释语句。
- `input a$` 键盘录入：中文输入法随固件批次上线（规格见 `docs/IME-SPEC.md`，input 自动调起拼音面板），上线前仅英文键盘。
- HTTP 仅明文 http://，响应体上限 8KB；record 单段 1~60 秒且阻塞程序运行。
- WiFi / AP / 蓝牙由系统统一管理（在系统设置里像手机一样连），程序读预注入变量（wifi_ssid$ / ap_ssid$ / ble_name$ 等）获取网络信息，禁止调用 wifi 语句。
- 幂运算用 `pow(a,b)`，不支持 `^` 运算符。
- goto 建议只用于大骨架跳转，逻辑组织优先用 for/while/gosub。

---
*本文档随解释器演进更新；语法以 `components/memoria_basic/` 实现为准。*

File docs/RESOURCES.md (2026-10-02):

# Memoria OS · 项目资源索引

> 本表登记仓库内全部资源（文档 / 源码 / 工具 / 素材）的路径与用途。
> 相对路径均以仓库根目录为基准。

## 一、文档

| 资源 | 路径 | 用途 |
|---|---|---|
| 项目说明 | `README.md` | 项目定位、构建与硬件概述 |
| 贡献规范 | `docs/CONTRIBUTING.md` | 代码规范与组件架构约定 |
| 许可 | `LICENSE` | MIT |

## 二、硬件文档

| 资源 | 路径 | 用途 |
|---|---|---|
| 采购清单 | `docs/HARDWARE-BOM.md` | 器件清单与参考价格 |
| 尺寸标准 | `docs/HARDWARE-DIMENSIONS.md` | 核心板定版、叠层核算与开孔表 |
| 外壳尺寸规划页 | `design/shell-design/Memoria-OS外壳尺寸规划.html` | 单页面板，浏览器直接打开 |
| 键盘按键布局表 | `design/键盘按键布局表.xlsx` | 6×10 键位布局 |
| 3D 模型 | `design/3D模型/外壳.123dx` | 外壳三维源文件 |
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

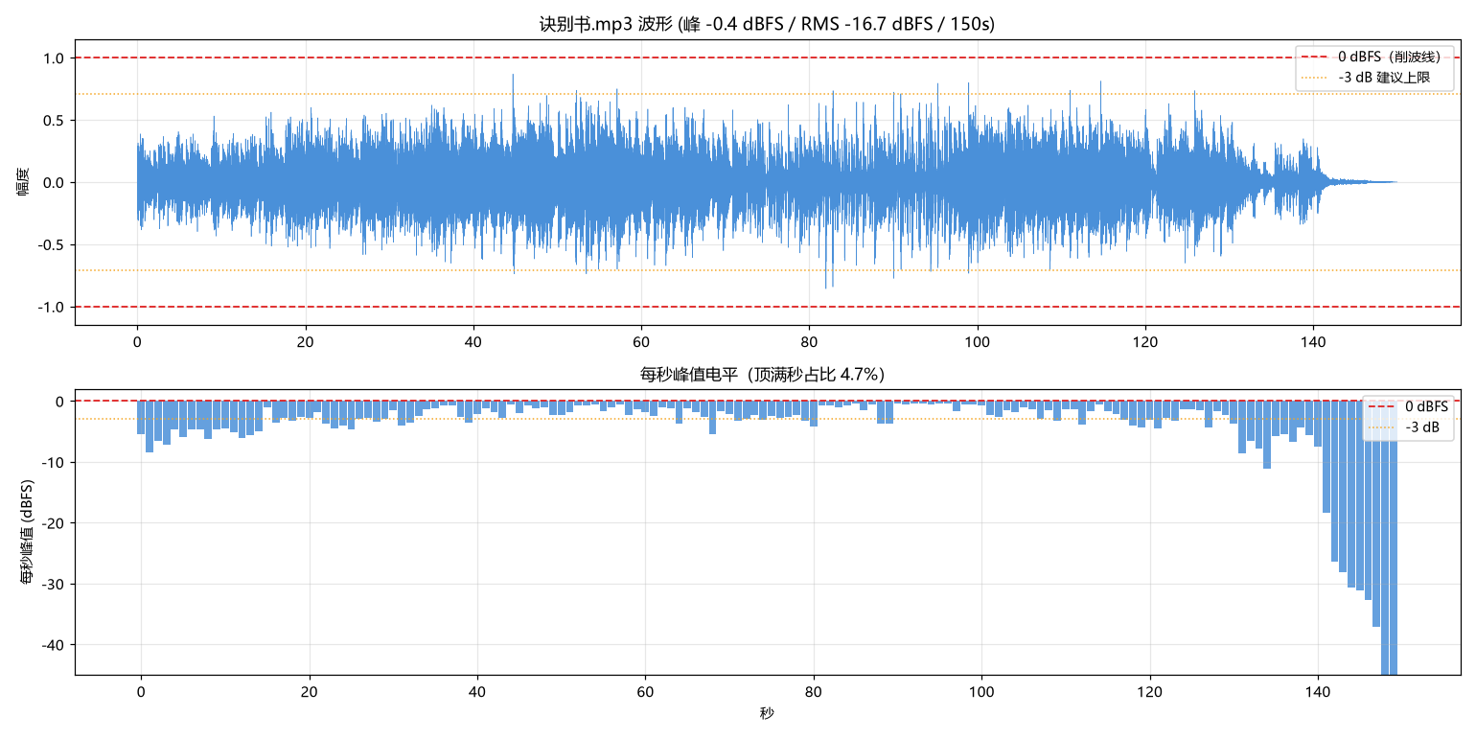
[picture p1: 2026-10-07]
docs/audio-guard/诀别书-波形分析.png

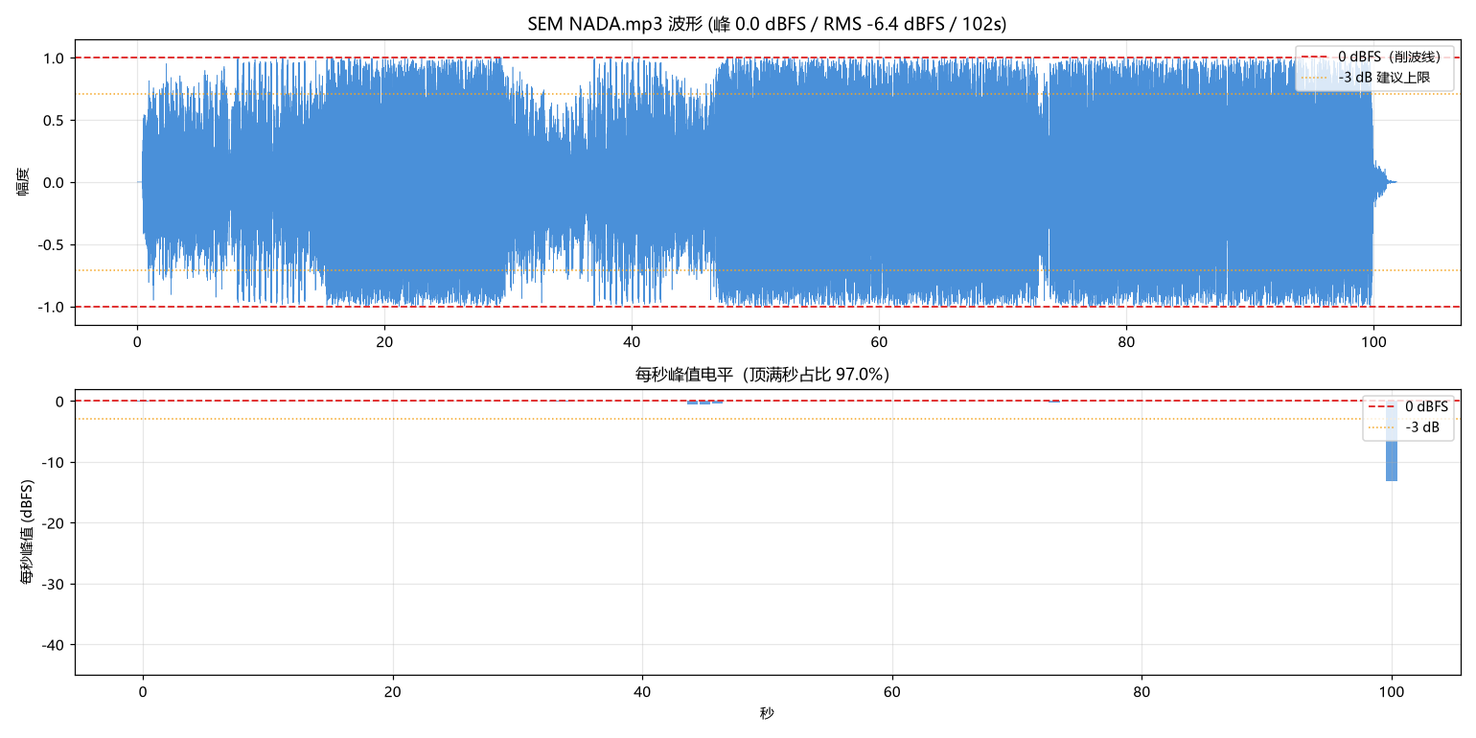
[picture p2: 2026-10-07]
docs/audio-guard/SEM-NADA-波形分析.png

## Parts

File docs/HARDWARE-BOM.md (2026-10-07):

# Memoria OS · 硬件采购清单（BOM）

> 版本：2026-10-07（v3，喇叭定版 4Ω 3W；与 `docs/PARTS-DIMENSIONS.md` 全零件尺寸手册、`docs/HARDWARE-DIMENSIONS.md` 引脚定版对齐）
> 搜索关键词可直接复制进淘宝，单价为淘宝常见**参考中位价**（不含邮费/优惠券）
> 已有工具（烙铁/焊锡/万用表/热缩管/导线）不列入。

## 一、必买清单

| #  | 部件 | 完整型号 / 规格 | 数量 | 参考单价 | 小计 | 搜索关键词 |
|----|---|---|----|---|---|---|
| 1  | ESP32-S3 核心板 | **大核心板 45×28 带底板排针**（ESP32-S3 N16R8，16MB Flash + 8MB PSRAM） | 1  | ¥35 | ¥35  | `ESP32-S3 N16R8 核心板` |
| 2  | 屏幕 | **ILI9488** 3.5″ 480×320 SPI（RGB565，无触摸，PCB 91×56） | 1  | ¥28 | ¥28  | `3.5寸 ILI9488 SPI 显示屏` |
| 3  | 洞洞板 | **100×150mm 双面 FR-4 喷锡**（2.54 孔距 1.6 厚） | 1  | ¥6  | ¥6 | `洞洞板 10x15 双面 2.54间距`  |
| 4  | 轻触按键 | **6×6×2.5mm 轻触开关**（直插立式，行程 0.25mm） | 100 | ¥0.15 | ¥15 | `轻触开关 6x6x2.5 直插` |
| 4b | IO 扩展器 | **MCP23017-I/SP**（I2C 16 位 GPIO，DIP-28 直插） | 2  | ¥5  | ¥10  | `MCP23017 DIP 直插` |
| 5  | 锂电池 | **聚合物软包 505080 级**（50×80×5，3.7V ~5000mAh，1S） | 1  | ¥30 | ¥30  | `聚合物锂电池 505080 5000mAh` |
| 6  | 充电板 | **TP4056 Type-C 1A**（带 DW01+8205 过充过放保护） | 1  | ¥3  | ¥3 | `TP4056 充电模块 Type-C` |
| 7  | 摇杆 | **KY-023**（X/Y 双 10k 电位器 + 按键） | 1  | ¥4  | ¥4 | `KY-023 摇杆模块` |
| 8  | 麦克风 | **INMP441**（I2S 数字 MEMS 麦克风模块） | 1  | ¥6  | ¥6 | `INMP441 麦克风模块` |
| 9  | 功放 | **MAX98357A**（I2S 数字输入 D 类功放，3.2W@4Ω / 1.8W@8Ω） | 1  | ¥6  | ¥6 | `MAX98357A 功放模块` |
| 9b | 喇叭 | **方形纸盆 4Ω 3W**（20×30，非圆形；与壳底仓兼容） | 1  | ¥4  | ¥4 | `喇叭 4欧 3W 方形纸盆` |
| 10 | TF 卡槽 | **TF / microSD 卡座（自弹式）** | 1  | ¥1.5 | ¥1.5 | `TF卡座 自弹式` |
| 10b | TF 存储卡 | **microSD 16GB Class10**（闪迪/三星等品牌） | 1  | ¥15 | ¥15  | `TF卡 16GB Class10` |
| 11 | SD 卡槽 | **SD 大卡座（焊线式）** | 1  | ¥4  | ¥4 | `SD卡座 大卡 焊线` |
| 12 | 灯带 | **WS2812B** RGB LED 灯条（60珠/m，2×6 珠 ≈ 55mm/条） | 2条 | ¥5  | ¥10  | `WS2812 灯条 8灯` |
| 13 | 排针排母 | **2.54mm 直针 + 排母**（若干） | 1套 | ¥4  | ¥4 | `排针排母 2.54 套装` |
| ~~14~~ | ~~电源开关~~ | ~~SS12D00 拨动开关~~ — **已取消（2026-10-06）**：改安卓式电源管理，电池常供电，长按电源键（独立 GPIO2）开关机，无需物理开关 | — | — | — | — |
| 15 | ~~音量侧键~~ | **电源/音量键已含在矩阵 60 键内**（R1 行 ON、R6 行 VOL−/VOL+），无需单列 | —  | — | — | — |
| 16 | 螺丝 | **M2.5 × 20~22 沉头**（贯穿壳+顶盖）+ 螺母 ×4 | 1套 | ¥5  | ¥5 | `M2.5 沉头螺丝 20mm` |
| 17 | 外壳 | **3D 打印 107×157×20**（顶盖 2.5 + 壳体 17.5 两件） | 1套 | ¥50 | ¥50  | `3D打印 代打印 PLA` |
| 18 | 面包板 | **MB-102 830 孔中号面包板**（自己有旧板可留 1 块新的备测） | 1  | ¥5  | ¥5  | `面包板 830孔 中号` |
| 18b| 直焊漆包线 | **免刮漆包线 0.3~0.5mm**（聚氨酯可焊漆，烙铁带锡直焊，洞洞板飞线不短路） | 1卷 | ¥5 | ¥5 | `直焊漆包线` |
| | | | | **合计** | **≈¥247（不含外壳 ¥197）** | |

> 注：键盘矩阵经 **2× MCP23017（I2C 扩展器）** 扫描（TCA8418 采购不可得，改用双 MCP23017），
> 两颗芯片共 32 个 IO：6 行 + 10 列 = 16 根 + 余量（灯带/未来扩展）。
> 键盘只占用 ESP32 的 I2C 两根线，**不占用直扫矩阵所需的 16 个 GPIO**。
> 按键采购 **100 个 = 60 上板 + 40 试错备用**（零基础焊接废品/键帽试错成本）；电源键（ON）与音量键（VOL−/VOL+）已含在矩阵 60 键内，无需单列。

## 二、已有物料（无需采购）

- 烙铁、焊锡、助焊剂
- 万用表、热缩管、导线
- Type-C 充电器与数据线
- 洞洞板焊接工具（镊子/斜口钳）

## 三、选型注意事项（与定版一致）

1. **核心板**：选 **45×28 大核心板（带底板排针）**，N16R8（16MB Flash + 8MB PSRAM）。背焊洞洞板：排针 2×17 穿板孔（2.54 对齐），芯片朝底仓下凸 ~7。别买 S3-Zero 小核心板（尺寸不符）。
2. **电池**：必须 **505080 软包（50×80×5）**，容量标称 ~5000mAh（实物 4500~5200 复核）。18650 圆柱直径 18mm 装不进，已排除。**按 PARTS-DIMENSIONS 实测厚度后复核仓尺寸**。
3. **喇叭**：要**方形纸盆 4Ω 3W**（非圆形，20×30，与壳底仓兼容；23×35 款需复核底仓空间）。**别买 8Ω 1W**：MAX98357A 在 8Ω 只输出 1.8W，功放功率是 1W 喇叭承受的 1.8 倍，音量开大先烧喇叭；4Ω 3W 与功放 3.2W@4Ω 同级别匹配，配合固件 AudioGuard（软限幅+热量保护）满血放 phonk 也不怕。透音孔开在喇叭正对面（壳底）。
4. **轻触键高度**：6×6×2.5 / 6×6×3 矮款，行程 0.25mm。6×6×5 立式长款主板层放不下（净高仅 2mm）。侧键可用余量件。
5. **键盘扩展器**：TCA8418 为 QFN 封装采购不可得，选 **2× MCP23017**（DIP-28 直插，易焊）。地址 A0=0 → 0x20、A0=1 → 0x21，与固件 MCP23017 驱动一致。
6. **洞洞板尺寸**：100×150 双面喷锡，2.54 孔距，1.6 厚。孔数 39×59 或 40×60 均可（键距 10mm 非 2.54 整数倍，键脚插相邻孔+弯外脚，差 1 孔不影响布局）。
7. **外壳**：107×157×20 = 顶盖 2.5 + 壳体 17.5 两件，内部 5 层台阶（底仓/主板托台/屏幕托台）。FDM 打印托台需支撑，打样店用 SLA/SLS 免支撑；或按 `docs/PARTS-DIMENSIONS.md` 自己画。
8. **屏幕引脚**：SPI 12/11/13 + CS10/DC9/RST8/BLK14；横装（长边沿 X），排针朝下。
9. **天线净空**：核心板天线端 5mm 禁金属、禁螺丝压。
10. **焊接顺序**：先电源/地 → 屏幕/摇杆 → 键盘（2× MCP23017 + 100 键 60 上板，焊完逐行测试再封壳）。
11. **键帽**：内嵌式（顶面凹 2mm 指窝），未按压与上壳齐平，行程 0.25mm；键帽 3D 打印或现成计算器键帽，孔位留 0.4~0.5 间隙。

## 四、预算对照（三档）

| 档位 | 合计（含外壳） | 不含外壳 | 采购方式 |
|---|---|---|---|
| **低价（下浮 ~25%）** | ≈¥185 | ≈¥148 | 批量集中采购，3D 打印多方比价 |
| **中位（参考价）** | ≈¥247 | ≈¥197 | 常规渠道直接采购 |
| **高价（上浮 ~20%）** | ≈¥296 | ≈¥236 | 品牌件：闪迪 TF 卡 / ATL 电池 / 官方 ESP32 / 大厂屏 |

### 三档差价大头

| 部件 | 低价 | 中位 | 高价 |
|---|---|---|---|
| ESP32-S3 N16R8 核心板 | ¥28 | ¥35 | ¥45（官方带排针板） |
| 屏幕 ILI9488 | ¥24 | ¥28 | ¥40（全新大厂屏） |
| 电池 505080 | ¥22 | ¥30 | ¥40（ATL/松下电芯） |
| TF 卡 16GB | ¥12 | ¥15 | ¥22（闪迪正品） |
| 3D 打印外壳 | ¥35 | ¥50 | ¥80（高精度 + 优质材料） |

### 3D 打印采购参考

- 本地打印服务商价格通常低于线上打印约 ¥10~20
- 同一模型多询几家，价格差异可达约 30%
- 采用标准 PLA 与常规 0.2 mm 层高即可，无需特殊颜色、碳纤维或高精度加项
- 自有设备打印时材料成本约 ¥5~10

## 五、到货核验清单（焊前必查）

1. 洞洞板数孔（39×59 或 40×60 都行）、量孔径
2. 屏幕含排针实际高度（6~8，影响整机厚度）
3. 电池 505080 实测厚 5、复核容量
4. 摇杆杆帽立起总高实测 ~32
5. 喇叭厚 + 背后留腔 2~3
6. 核心板含排针高 ~5.5、背焊下凸 ~7

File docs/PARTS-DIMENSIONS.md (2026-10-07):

# Memoria OS · 全零件尺寸手册（照此画壳）

> 版本：2026-10-03 · 与 `HARDWARE-DIMENSIONS.md`（叠层/引脚）、`HARDWARE-BOM.md`（采购）同源
> 单位：mm · 尺寸来源：市售模块通用规格（淘宝常见款），**「实」= 必须卡尺实测后覆盖**，「定」= 已定版
> 用途：你自己画外壳（123D Design）时，按本表查每个零件的长×宽×高、接口方向、开孔要求

---

## 〇、画壳流程（建议顺序）

1. **先排厚度**：下表「厚度关键件」里最高的那条决定壳厚（摇杆 32 / 屏幕 8 / 喇叭 10 / 核心板下凸 7 / 键盘 3.75 / 电池 5）。
2. **再排平面**：按层级表（顶部→主板→底仓→侧壁）把每件放进去，元件凸起不得侵占隔板。
3. **最后开孔**：屏幕窗、键孔、摇杆孔、麦克孔、侧壁缝（TF/SD/USB/开关/音量）、透音孔、螺丝孔。

## 一、厚度关键件（决定整机厚度，先看）

| 件 | 高度 | 说明 |
|----|---|---|
| KY-023 摇杆 | 杆帽立起**总高 ~32**（自 PCB 面），板上件 ~10 | 想薄壳就把它独立穿顶（PCB 放顶层、杆帽从面板 Ø16 孔露出 ~7.5）；不想穿顶就整体按 40mm 级设计 |
| ILI9488 屏幕（含排针） | 6~8（实） | 排针朝下，实测可压到 6~7 |
| 喇叭 | 厚 5~10 + 腔体 2~3（实） | 用方形纸盆喇叭时按实 |
| 锂电 505080 | 5 | 软包，可微弯 1~2 |
| 核心板（背焊） | 芯片朝底仓**下凸 ~7** | 占底仓顶空间，下方不摆件 |
| 键盘层 | 轻触键 2.5 + 键帽内嵌 ~1.25 = **3.75** | 键帽不按时与面板齐平，按下行程 0.25 |
| 2× MCP23017 | 3.2（DIP28 高） | 主板层内收纳 |
| TP4056 | 3~4 | 主板层内 |

## 二、顶部面板件（正面）

| 件 | 型号 | 长×宽 | 高 | 接口 / 开孔 | 数据 |
|----|---|---|----|---|---|
| 屏幕 | ILI9488 3.5″ 480×320 SPI 无触摸 | PCB **91×56** | 6~8 | 视窗 70.8×48.5 → 面板屏幕窗 **≥71×49**；排针朝下；SPI 12/11/13 + CS10/DC9/RST8/BLK14；**横装（长边沿 X）** | 实 |
| 轻触按键 ×60 | 6×6 矮款 | 6×6 | 2.5 | 键中心距 10；面板键孔 7.4×7.4；脚距 4.45，同侧两脚插相邻 2.54 孔 | 定 |
| 键帽 ×60 | 自打 3D | 7×7 | 顶面凹 2 指窝 | 内嵌式：不按时顶面与面板齐平，底部比面板内面再低 1mm 压轻触键 | 定 |
| 摇杆 | KY-023 | PCB **26×34** | 杆帽总高 ~32 / 帽顶 Ø12 | 5 针 2.54 直插；X=GPIO7 Y=GPIO5 BTN=GPIO38；穿顶方案：面板开 **Ø16** 贯通孔 | 实 |
| 麦克风 | INMP441（I2S 数字 MEMS） | ~15×13 | 2.5 | 拾音面朝上面板；面板麦克孔 Ø1.5×3（如 35,65 / 45,62 / 40,70）；数据 GPIO16，SCK/WS 复用功放 18/21 | 实 |

## 三、主板层（洞洞板）

| 件 | 型号 | 长×宽 | 高 | 说明 | 数据 |
|----|---|---|----|---|---|
| 洞洞板 | 100×150 双面 FR-4 | 100×150 | 1.6 | **2.54 孔距，39×59 孔**，孔径 ~1.0；元件层净高 ≤2 | 定 |
| 核心板 | ESP32-S3 大核心板 45×28（带底板排针） | **45×28** | 含排针 ~5.5 | **背焊洞洞板**：排针 2×17 沿长边穿板孔（2.54 对齐），芯片/模块朝底仓下凸 ~7；落孔区 X52~97 Y60~88；天线端 5mm 禁金属 | 实 |
| IO 扩展 ×2 | MCP23017-I/SP | DIP28 **35.5×7.6** | 3.2 | I2C 0x20/0x21 @GPIO1/6；建议键盘区左下空白处（C0~C8/R10~R13 附近），可转接板或飞线 | 定 |
| 灯带 ×2 | WS2812B 60珠/m | 宽 10 | 2.5 | 不焊洞洞板，软板贴面板内面：键盘上缘 + 键盘下缘各 6 珠，GPIO46 RMT | 定 |
| 排针排母 | 2.54 直针+排母 | — | 针 ~8.5 / 母 ~8.5 | 侧壁预留烧录排针孔（UART0 43/44 唯一烧录通道） | 定 |

## 四、底仓件（壳体底部）

| 件 | 型号 | 长×宽 | 高 | 说明 | 数据 |
|----|---|---|----|---|---|
| 锂电 | 聚合物软包 505080 级 | **50×80** | 5 | 底仓左上 X2~52 Y2~82 竖放（长边沿 Y），避核心板背焊区与喇叭；每边留 1 松配 | 实 |
| 喇叭 | 方形纸盆 4Ω 3W（非圆形） | 20×30 | 5~10 | 透音孔开在喇叭正对面（壳体底部），孔 Ø2×7 错排或长条缝；背后留腔体 2~3（与 HARDWARE-BOM v3 定版一致） | 实 |
| 功放 | MAX98357A 模块 | 15.5×13 | 3.5 | I2S BCLK18/WS21/DOUT15；就近焊喇叭侧，引线短 | 实 |
| TF 卡座 | microSD 自弹式 | 15×16 | 2~3 | 内置底部；卡插入方向朝壳壁 TF 缝（侧缝 ≥13×2，卡外露 ≥4mm） | 实 |
| SD 大卡座 | 焊线式 | 30×29 | 3.5 | 外置侧壁：侧缝 25×2.5，插卡行程 5mm；用途导照片/数据 | 实 |

## 五、侧壁/接口件

| 件 | 型号 | 长×宽 | 高 | 开孔 | 数据 |
|----|---|---|----|---|---|
| 充电板 | TP4056 Type-C 1A（带 DW01+8205 保护） | 26.5×17.5 | 3~4 | USB-C 口凸出板边 1.5~2 → 侧壁开孔 **10×4** | 实 |
| 电源开关 | SS12D00 拨动 | 19×10 | 7（含柄） | 侧壁开槽 19×10，柄行程 4mm | 实 |
| 音量侧键 ×2 | 轻触键或拨杆 | — | — | 侧壁长条孔 ~20×3 | 实 |
| USB-C 数据口 | 核心板自带 | — | — | 烧录走 UART 43/44，USB 仅供电（OTG 被占用） | 定 |

## 六、结构件

| 件 | 规格 | 说明 |
|----|---|---|
| 螺丝 | **M2.5 沉头 × 20~22**（贯穿 17.5 壳 + 2.5 顶盖） | 四角 (8,8)(99,8)(8,149)(99,149)，孔 Ø2.5；螺母或螺纹盲孔在壳体底部 |
| 隔板 | 3D 打印 2mm 实体板 | 一体壳方案已内置台阶（主板托台 z9~11 / 屏幕托台 z12~14），独立隔板方案按 HARDWARE-DIMENSIONS §6 |
| 外壳材料 | PLA 0.2 层高 | 打样店 SLA/SLS 可免支撑；FDM 内部托台水平面需支撑 |

## 七、不装壳（调试用）

| 件 | 型号 | 尺寸 |
|----|---|---|
| 面包板 ×2 | MB-102 | 830 孔，165×55×8.5 |

---

## 待卡尺实测（定稿前必须覆盖）

1. ILI9488 模块**含排针实际高度**（6~8 → 直接影响整机厚）
2. 喇叭实际厚度 + 腔体余量（5~10 + 2~3）
3. KY-023 杆帽立起**实际总高**（32 为市售典型）
4. 电池 505080 **实际厚度**（5）与标称容量复核（市售 4500~5200mAh）
5. 核心板含排针实际高度（~5.5）与背焊下凸量（~7）
6. 洞洞板孔径实际值（0.9~1.0）

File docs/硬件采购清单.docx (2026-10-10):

# Memoria OS 硬件采购清单

版本 2026-10-10（v4，对齐 BOM v3 + 预算 200 内 + 焊坏备件）· 与尺寸手册、引脚定版对齐

本清单为 Memoria OS 掌上电脑的全部采购物料。单价为淘宝常见参考中位价，不含邮费与优惠券；搜索关键词可直接复制进淘宝。家庭已有工具（烙铁、焊锡、助焊剂、万用表、热缩管、导线、Type-C 充电器与数据线）不列入。

# 一、必买清单

序号 | 部件 | 完整型号 / 规格 | 数量 | 参考单价 | 小计 | 搜索关键词
1 | ESP32-S3 核心板 | 大核心板 45×28 带底板排针（N16R8，16MB Flash + 8MB PSRAM） | 1 | ¥35 | ¥35 | ESP32-S3 N16R8 核心板
2 | 屏幕 | ILI9488 3.5″ 480×320 SPI（RGB565，无触摸，PCB 91×56） | 1 | ¥28 | ¥28 | 3.5寸 ILI9488 SPI 显示屏
3 | 洞洞板 | 100×150mm 双面 FR-4 喷锡（2.54 孔距 1.6 厚） | 1 | ¥6 | ¥6 | 洞洞板 10x15 双面 2.54间距
4 | 轻触按键 | 6×6×2.5mm 轻触开关（直插立式，行程 0.25mm）（60 上板 + 40 试错备用） | 100 | ¥0.15 | ¥15 | 轻触开关 6x6x2.5 直插
4b | IO 扩展器 | MCP23017-I/SP（I2C 16 位 GPIO，DIP-28 直插） | 2 | ¥5 | ¥10 | MCP23017 DIP 直插
5 | 锂电池 | 聚合物软包 505080 级（50×80×5，3.7V 约 5000mAh，1S） | 1 | ¥30 | ¥30 | 聚合物锂电池 505080 5000mAh
6 | 充电板 | TP4056 Type-C 1A（带 DW01+8205 过充过放保护） | 1 | ¥3 | ¥3 | TP4056 充电模块 Type-C
7 | 摇杆 | KY-023（X/Y 双 10k 电位器 + 按键） | 1 | ¥4 | ¥4 | KY-023 摇杆模块
8 | 麦克风 | INMP441（I2S 数字 MEMS 麦克风模块） | 1 | ¥6 | ¥6 | INMP441 麦克风模块
9 | 功放 | MAX98357A（I2S 数字输入 D 类功放，3.2W/4Ω，1.8W/8Ω） | 1 | ¥6 | ¥6 | MAX98357A 功放模块
9b | 喇叭 | 方形纸盆 4Ω 3W（约 20×30，非圆形） | 1 | ¥4 | ¥4 | 喇叭 4欧 3W 方形纸盆
10 | TF 卡槽 | TF / microSD 卡座（自弹式） | 1 | ¥1.5 | ¥1.5 | TF卡座 自弹式
10b | TF 存储卡 | microSD 8GB Class10（闪迪/三星；16GB 版 +¥7 可选） | 1 | ¥8 | ¥8 | TF卡 16GB Class10
11 | SD 卡槽 | SD 大卡座（焊线式） | 1 | ¥4 | ¥4 | SD卡座 大卡 焊线
12 | 灯带 | WS2812B RGB LED 灯条（60 珠/m，2×6 珠约 55mm/条；先购 1 条，另一条可后加） | 1条 | ¥5 | ¥5 | WS2812 灯条 8灯
13 | 排针排母 | 2.54mm 直针 + 排母（若干） | 1套 | ¥4 | ¥4 | 排针排母 2.54 套装
16 | 螺丝 | M2.5×20~22 沉头（贯穿壳与顶盖）+ 螺母 4 个 | 1套 | ¥5 | ¥5 | M2.5 沉头螺丝 20mm
18 | 面包板 | MB-102 830 孔中号面包板 | 1 | ¥5 | ¥5 | 面包板 830孔 中号
18b | 直焊漆包线 | 免刮漆包线 0.3~0.5mm（聚氨酯可焊漆，洞洞板飞线不短路） | 1卷 | ¥5 | ¥5 | 直焊漆包线
备1 | MCP23017 备用 | MCP23017-I/SP（DIP-28，焊坏/插反烧毁替换件） | 1 | ¥5 | ¥5 | MCP23017 DIP 直插
备2 | 功放 备用 | MAX98357A 模块（接错电源易烧，替换件） | 1 | ¥6 | ¥6 | MAX98357A 功放模块
备3 | 喇叭 备用 | 方形纸盆 4Ω 3W（音圈易焊坏，替换件） | 1 | ¥4 | ¥4 | 喇叭 4欧 3W 方形纸盆
| 合计 | （第一阶段：含备件，不含外壳；外壳 ¥50 后置） | | | ≈¥200

注：键盘矩阵经 2× MCP23017（I2C 扩展器）扫描（TCA8418 采购不可得，改用双 MCP23017），两颗芯片共 32 个 IO，可满足 6 行 + 10 列 = 16 根并留余量；键盘只占用 ESP32 的 I2C 两根线，不占用直扫矩阵所需的 16 个 GPIO。

# 二、已有物料（无需采购）

- 烙铁、焊锡、助焊剂
- 万用表、热缩管、导线
- Type-C 充电器与数据线
- 洞洞板焊接工具（镊子、斜口钳）

# 三、选型注意事项

1. 核心板：选 45×28 大核心板（带底板排针），N16R8（16MB Flash + 8MB PSRAM）。背焊洞洞板，排针 2×17 穿板孔（2.54 对齐），芯片朝底仓下凸约 7mm。勿购 S3-Zero 小核心板（尺寸不符）。

2. 电池：必须为 505080 软包（50×80×5），标称约 5000mAh（实物 4500~5200 复核）。18650 圆柱直径 18mm 装不进，已排除。按实测厚度复核电池仓。

3. 喇叭：选方形纸盆（非圆形），4Ω 3W（约 20×30，与壳底仓兼容）；透音孔开在喇叭正对面（壳体底部）。

4. 轻触键：6×6×2.5 或 6×6×3 矮款，行程 0.25mm；6×6×5 立式长款主板层放不下。音量侧键可用余量件。

5. 键盘扩展器：TCA8418 为 QFN 封装采购不可得，选用 2× MCP23017（DIP-28 直插，易焊）。地址 A0=0 对应 0x20、A0=1 对应 0x21，与固件 MCP23017 驱动一致。

6. 洞洞板：100×150 双面喷锡，2.54 孔距，1.6 厚。孔数 39×59 或 40×60 均可——键距 10mm 非 2.54 整数倍，键脚插相邻孔并弯外脚，差 1 孔不影响布局。

7. 外壳：107×157×20，顶盖 2.5 + 壳体 17.5 两件，内部 5 层台阶（底仓、主板托台、屏幕托台）。FDM 打印托台需支撑，打样店 SLA/SLS 免支撑；也可按尺寸手册自行设计。

8. 屏幕引脚：SPI 12/11/13 + CS10/DC9/RST8/BLK14；横装（长边沿 X），排针朝下。

9. 天线净空：核心板天线端 5mm 内禁金属、禁螺丝压。

10. 焊接顺序：先电源与地，再屏幕与摇杆，最后键盘（2× MCP23017 + 100 键 60 上板，焊完逐行测试再封壳）。

11. 键帽：内嵌式（顶面凹 2mm 指窝），未按压与上壳齐平，行程 0.25mm；键帽 3D 打印或现成计算器键帽，孔位留 0.4~0.5mm 间隙防卡。

# 四、预算对照（三档）

档位 | 第一阶段（含备件） | 加购外壳后 | 采购方式
低价（下浮约 25%） | 约 ¥150 | 约 ¥200 | 批量集中采购，3D 打印多方比价
中位（参考价） | 约 ¥200 | 约 ¥250 | 常规渠道直接采购
高价（上浮约 20%） | 约 ¥240 | 约 ¥290 | 品牌件：闪迪 TF 卡、ATL 电池、官方 ESP32、大厂屏

三档差价大头

部件 | 低价 | 中位 | 高价
ESP32-S3 N16R8 核心板 | ¥28 | ¥35 | ¥45（官方带排针板）
屏幕 ILI9488 | ¥24 | ¥28 | ¥40（全新大厂屏）
电池 505080 | ¥22 | ¥30 | ¥40（ATL/松下电芯）
TF 卡 8GB（16GB 加 ¥7） | ¥6 | ¥8 | ¥12
3D 打印外壳 | ¥35 | ¥50 | ¥80（高精度 + 优质材料）

3D 打印采购参考：本地打印服务通常比线上低 10~20 元；同一模型多询几家，价格差异可达约 30%；标准 PLA 与常规 0.2mm 层高即可，无需特殊颜色或高精度加项；自有设备打印时材料成本约 5~10 元。

# 五、到货核验清单（焊前必查）

1. 洞洞板数孔（39×59 或 40×60 均可）、量孔径。

2. 屏幕含排针实际高度（6~8mm，影响整机厚度）。

3. 电池 505080 实测厚度 5mm，复核容量。

4. 摇杆杆帽立起总高实测约 32mm。

5. 喇叭厚度并留腔体 2~3mm。

6. 核心板含排针高约 5.5mm，背焊下凸约 7mm。

外壳 3D 打印（¥50）后置采购：焊接调试阶段无需外壳，验证通过后再按需下单（见预算对照）。

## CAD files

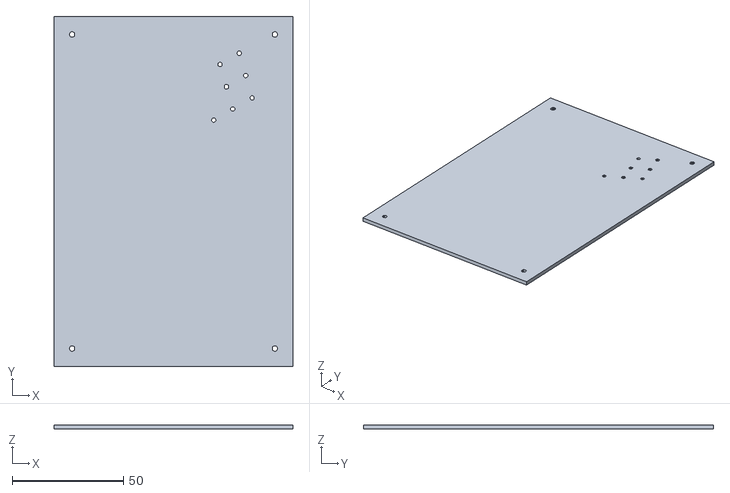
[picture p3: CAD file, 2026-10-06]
design/3D模型/外壳STL/底壳.stl
107.0 x 157.0 x 2.00

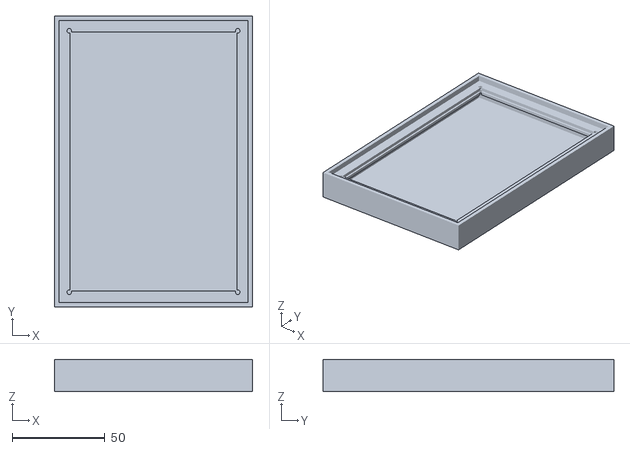
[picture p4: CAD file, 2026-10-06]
design/3D模型/外壳STL/壳体.stl
107.0 x 157.0 x 17.5

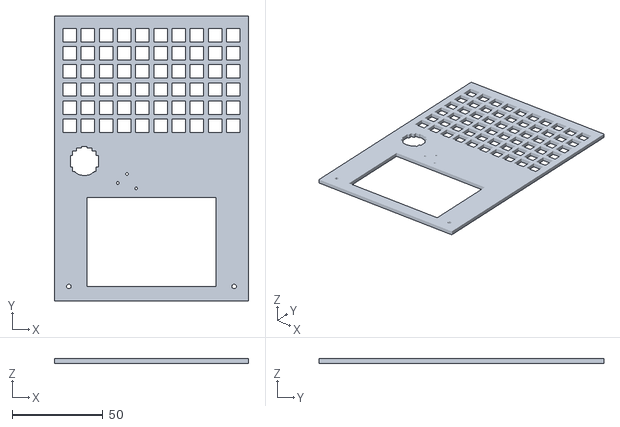
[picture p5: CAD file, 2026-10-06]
design/3D模型/外壳STL/前面板.stl
107.0 x 157.0 x 2.50

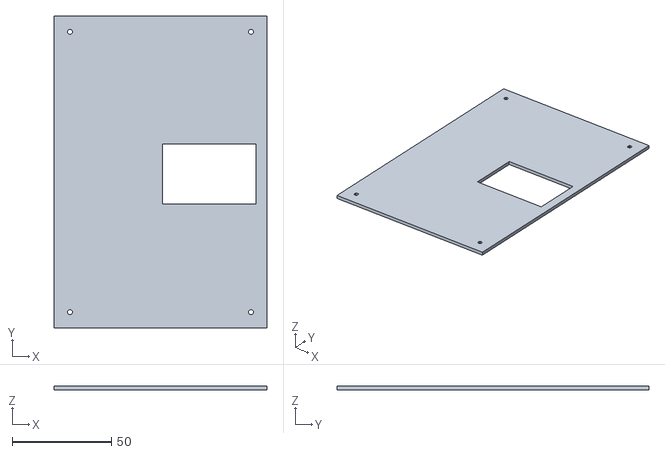
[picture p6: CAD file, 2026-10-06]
design/3D模型/外壳STL/隔板①.stl
107.0 x 157.0 x 2.00

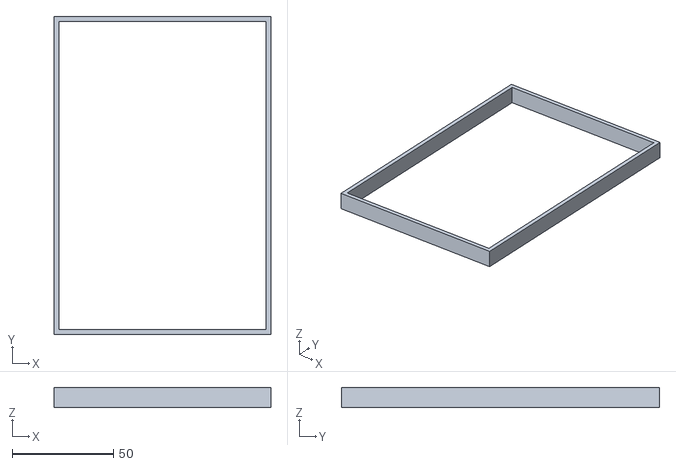
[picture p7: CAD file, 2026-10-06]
design/3D模型/外壳STL/底仓壁.stl
107.0 x 157.0 x 10.0

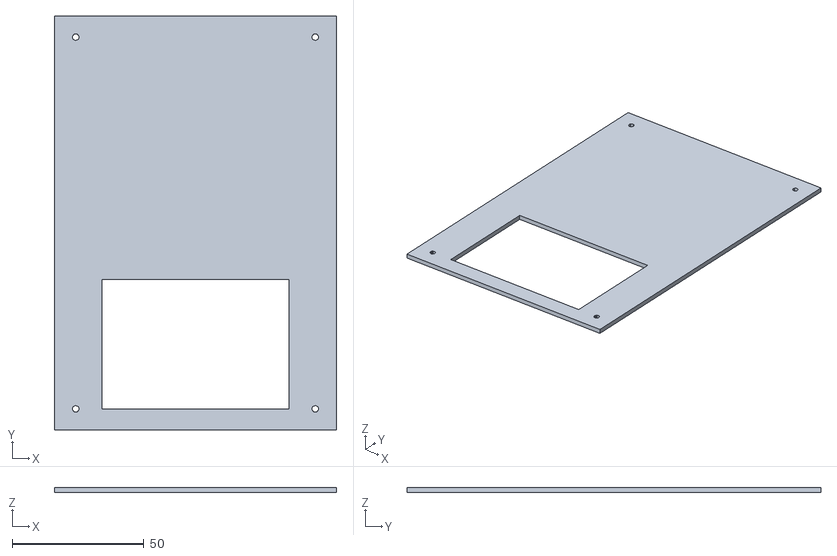
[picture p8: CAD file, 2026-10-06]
design/3D模型/外壳STL/隔板③.stl
107.0 x 157.0 x 2.00

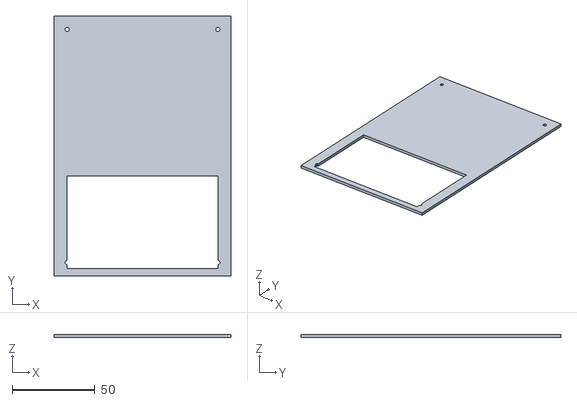
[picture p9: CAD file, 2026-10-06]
design/3D模型/外壳STL/隔板②.stl
107.0 x 157.0 x 2.00

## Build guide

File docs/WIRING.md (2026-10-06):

# Memoria OS 接线施工图（WIRING）

> 照本文件焊接即可，无需读代码。所有引脚号唯一来源：`components/memoria_drivers/include/drivers_config.hpp`；分配依据见 `GPIO-ALLOC.md`。两者冲突时以 drivers_config.hpp 为准并回报桥上。

---

## 0. 总则（焊前必读）

1. **供电**：锂电池 → TP4056（B+/B−）→ OUT+ 串拨动开关 → 整机 3.3V 域。TP4056 的 OUT 接核心板 5V/3V3 由核心板 LDO 降压，或直接用 3.3V LDO——**所有模块 VCC 一律 3.3V**（除 TP4056 本体）。
2. **共地**：所有模块 GND 与电池负极、核心板 GND 单星汇聚一点，避免地环路。
3. **天线禁区**：核心板天线端约 15×5mm 区域周围 **5mm 内禁止金属件、禁止铺铜、禁止走线**。
4. **Strapping 引脚**（开机采样，勿接上拉器件）：GPIO0（BOOT）、GPIO3、GPIO45、GPIO46。GPIO46 已用于灯带数据，灯带 DIN 不含上拉、串 330Ω~1K 保护电阻即可。
5. **USB**：GPIO19/20 为 USB D−/D+，核心板 USB-C 口直插烧录/供电，**这两脚不接任何外设**。
6. **BOOT 键**：用核心板自带 BOOT 键进下载模式，无需外焊。

---

## 1. ESP32-S3 核心板引脚使用总表（按 GPIO 序）

| GPIO | 用途 | 方向 | 接往 |
|---|---|---|---|
| 1 | I2C SDA（键盘扩展器） | 双向 | MCP #1/#2 SDA |
| 2 | **电源键（安卓式，RTC 域）** | 输入上拉 | 侧键①，按下=拉低 |
| 3.3V/GND | — | — | 全机供电 |
| 4 | 电池电压采样 ADC1_CH3 | 输入 | 分压节点 |
| 5 | 摇杆 Y 轴 ADC1_CH4 | 输入 | KY-023 VRy |
| 6 | I2C SCL | 输出 | MCP #1/#2 SCL |
| 7 | 摇杆 X 轴 ADC1_CH6 | 输入 | KY-023 VRx |
| 8 | 屏幕复位 | 输出 | LCD RST |
| 9 | 屏幕数据/命令 | 输出 | LCD DC |
| 10 | 屏幕 SPI 片选 | 输出 | LCD CS |
| 11 | SPI MOSI | 输出 | LCD SDI + TF MOSI |
| 12 | SPI SCLK | 输出 | LCD SCK + TF SCK |
| 13 | SPI MISO | 输入 | LCD SDO + TF MISO |
| 14 | 屏幕背光 PWM | 输出 | LCD LED 脚 |
| 15 | I2S 数据输出 | 输出 | MAX98357A DIN |
| 16 | 麦克风数据 | 输入 | INMP441 SD |
| 17 | TF 卡片选 | 输出 | TF CS |
| 18 | I2S 位时钟 | 输出 | MAX98357A BCLK |
| 21 | I2S 字选通 | 输出 | MAX98357A LRC |
| 38 | 摇杆按下 | 输入上拉 | KY-023 SW |
| 46 | 键盘灯带数据 | 输出 | WS2812 DIN（串 330Ω） |
| 19/20 | USB D−/D+ | — | 核心板 USB-C，悬空勿接 |
| 33~37 | **Octal PSRAM 内部占用，禁接任何外设** | — | — |
| 0/3/45/46 | Strapping，见总则 4 | — | — |

**已用 21 个 GPIO，剩余自由脚：39、40、41、42、47、48**（39/40/41 已定 SD 大卡 SDMMC，见桥）。麦克风 INMP441：SD=16 已用（录音 I2S RX，2026-10-01 定版），SCK/WS 复用功放 BCLK=18/WS=21（不占新脚）；备用独立时钟 SCK=47/WS=48（仅真机复用失败时启用）。电源键 GPIO2（2026-10-06 定版，安卓式长按电源管理）。

---

## 2. 分模块接线表（按焊接顺序）

### 2.1 电源链（安卓式电源管理，2026-10-06 定版）
| 连接 | 说明 |
|---|---|
| 电池红 → TP4056 B+，电池黑 → B− | 503450 级 3.7V 锂电 |
| TP4056 OUT+ → 核心板 5V（或经 3.3V LDO） | **常供电，无物理开关**；"关机"= 固件深度睡眠（微安级），"开机"= 长按电源键 RTC 唤醒 |
| TP4056 OUT− → 核心板 GND | 共地点 |
| 电池+ → R1 100K → 采样节点；采样节点 → R2 100K → GND；节点 → GPIO4 | **节点并一颗 100nF 到 GND**（ADC 源阻抗高，无电容读数偏低） |
| USB-C（TP4056 模块自带）从外壳侧壁开孔伸出 | 充电口 |

**电源键（侧键①）**：独立引线接 **GPIO2**（RTC 域，唯一空闲，可深度睡眠唤醒），另一端接 GND（按键按下=拉低）。
- 上电即开机：任何时刻插电/电池供电 → 核心板直接启动进桌面。
- 长按 ≥2s（运行中）：弹出电源菜单【关机 / 重启 / 取消】。
- 关机：`esp_deep_sleep_start()`，唤醒源 = GPIO2（EXT0 下降沿）。
- 深度睡眠中长按电源键 ≥1s：RTC 唤醒 → 重启进桌面（≈ 安卓开机）。
- 短按（<2s）：忽略（防误触）。
- 注意：深度睡眠仅保留 RTC 域，PSRAM/屏幕掉电；NVS/mem_priv 数据不丢。

### 2.2 屏幕 ILI9488 3.5" SPI
| 模块脚 | 接 |
|---|-----|
| VCC / GND | 3.3V / GND |
| CS | GPIO10 |
| RESET | GPIO8 |
| DC | GPIO9 |
| SDI(MOSI) | GPIO11 |
| SCK | GPIO12 |
| SDO(MISO) | GPIO13 |
| LED(背光) | GPIO14 |

### 2.3 TF 卡模块（FAT32，卡先拷 `sdcard/` 全部内容到根目录）
| 模块脚 | 接 |
|---|-----|
| VCC / GND | 3.3V（模块带 5V 稳压的接 5V 亦可）/ GND |
| CS | GPIO17 |
| SCK | GPIO12（与屏同总线） |
| MOSI | GPIO11（同上） |
| MISO | GPIO13（同上） |

### 2.4 摇杆 KY-023（杆帽穿顶面板）
| 模块脚 | 接 |
|---|-----|
| VCC / GND | **3.3V**（勿接 5V，超 ADC 量程）/ GND |
| VRx | GPIO7 |
| VRy | GPIO5 |
| SW | GPIO38 |

### 2.5 I2S 功放 MAX98357A + 喇叭
| 模块脚 | 接 |
|---|-----|
| VIN / GND | 3.3V / GND |
| BCLK | GPIO18 |
| LRC(WS) | GPIO21 |
| DIN | GPIO15 |
| GAIN | 悬空（9dB，默认）；嫌声小改接 GND（12dB） |
| SD | 模块版默认已上拉（输出左右混合）；若焊完无声，SD 串 100K 接 3.3V 强制开声 |
| 喇叭 4Ω 3W | 模块 +/- 输出，透音孔开在喇叭正对面 |

### 2.6 键盘扫描器 2× MCP23017
| MCP #1（地址 0x20） | 接 | MCP #2（地址 0x21） | 接 |
|---|-----|---|-----|
| VCC / GND | 3.3V / GND | VCC / GND | 3.3V / GND |
| SDA / SCL | GPIO1 / GPIO6 | SDA / SCL | 与 #1 并联同线 |
| A0 A1 A2 | **全接 GND** | A0 | **接 3.3V** |
| （A1 A2 同 #1） | — | A1 A2 | 接 GND |
| RESET | 接 3.3V | RESET | 接 3.3V |
| GPA0~GPA5 | 键盘行 R0~R5 | GPA0~GPA5 | 键盘列 C4~C9 |
| GPB0~GPB3 | 键盘列 C0~C3 | GPB4~GPB7、GPB0-7 | 悬空 |

I2C 已用内部上拉（软件配置），线长超 10cm 建议在 SDA/SCL 各加 4.7K 上拉到 3.3V。

### 2.7 键盘矩阵 6×10（60 键；电源键已独立，见 §2.1）
- 每行：该行 **10 颗键的左脚并联**一条线 → 对应行线。
- 每列：该列 **6 颗键的右脚并联**一条线 → 对应列线。
- 键位布局（固件定义，焊键帽时对照）：

```
行    C0    C1    C2    C3    C4    C5    C6    C7    C8    C9
R1   (空)  F1    F2    F3    F4    F5    F6    F7    灯带   ⌫
R2   1     2     3     4     5     6     7     8     9     0
R3   q     w     e     r     t     y     u     i     o     p
R4   a     s     d     f     g     h     j     k     l     ;
R5   ⇧     z     x     c     v     b     n     m     ,     .
R6   CAP   CTRL  VOL−  VOL+  空格   ←     →     ↓     ↑     ⏎
```

- **R1 行 C0 原 ON 键已移出矩阵**：改为独立侧键①接 GPIO2（安卓式电源键，见 §2.1），该位不焊键（或留作 F8 自定义，固件映射待定）。
- 行线去向：R0=R1行、R1=R2行 … R5=R6行 → MCP#1 GPA0~5。
- 列线去向：C0~C3 → MCP#1 GPB0~3；C4~C9 → MCP#2 GPA0~5。
- **二极管两案（防多键串扰）**：
  - **A 案（不焊）**：60 键直连。单/双键正常，Shift+字母+第三键成矩形时会偶发多出一个错字。焊工量最小。
  - **B 案（推荐）**：每键串一颗 1N4148——**键右脚 → 二极管阳极，阴极 → 列线**（电流方向 列→行 导通）。60 颗，彻底防幽灵键。
  - 两案固件通用，先焊 A 案可开机，后续可补。

### 2.8 键盘灯带 WS2812 ×2（串成一条 12 珠链）
- GPIO46 → 330Ω → 灯带① DIN；灯带① DOUT → 灯带② DIN。
- 灯带 VCC 接 3.3V，GND 共地。两条分别贴键盘上边沿/下边沿（各 6 珠）。

---

## 3. 焊完上电自检（对照 GPIO-ALLOC §5）

| 步 | 动作 | 预期 |
|----|---|---|
| 1 | 接电池（TP4056 红灯亮）或插 USB-C 充电线 | TP4056 红灯亮 = 充电回路 OK；**常供电，无需开关** |
| 2 | 等待上电 | 屏背光亮、桌面/启动画面出现，**不无限重启**（Z1 死锁修复验证点） |
| 3 | 看 A 桌面右上角电池图标 | 显示百分比 ≈ 实测电压（电量永远 0% = ADC 接线错） |
| 4 | 拨摇杆 | 焦点在桌面格子间移动（X/Y 反了就互换 VRx/VRy 线） |
| 5 | 按任意键 | 终端输入字符；按 F1~F7 进对应模式 |
| 6 | 按 R1 行"灯带"键 | 键盘灯带亮/切换档位（全黑 = 灯带链路检查 330Ω 与 DIN 方向） |
| 7 | **长按电源键（侧键① GPIO2）≥2s** | 弹电源菜单【关机 / 重启 / 取消】；选关机 → 屏灭（深度睡眠）；再长按 ≥1s → 唤醒回桌面 |
| 8 | 进 MUSIC 播 sample/ 下 mp3 | 出声 = I2S 链 OK |
| 9 | 拔 TF 再插回 | 字库加载失败报错 = TF 座接触不良，重焊 |

---

## 4. 已知坑位提示

- **GPIO33~37 绝对不接东西**（Octal PSRAM 内部占用，接了会崩）。
- 摇杆 VCC 必须 3.3V：5V 供电时 ADC 超量程，中位值漂移。
- MCP #2 的 A0 忘接 3.3V → 两颗芯片同地址 0x20，键盘列 C4~C9 全乱。
- 二极管方向焊反（B 案）→ 该键永远无反应，逐键排查时按自检表第 5 步。
- 灯带方向：DIN 箭头朝进数据侧；接反整条不亮。

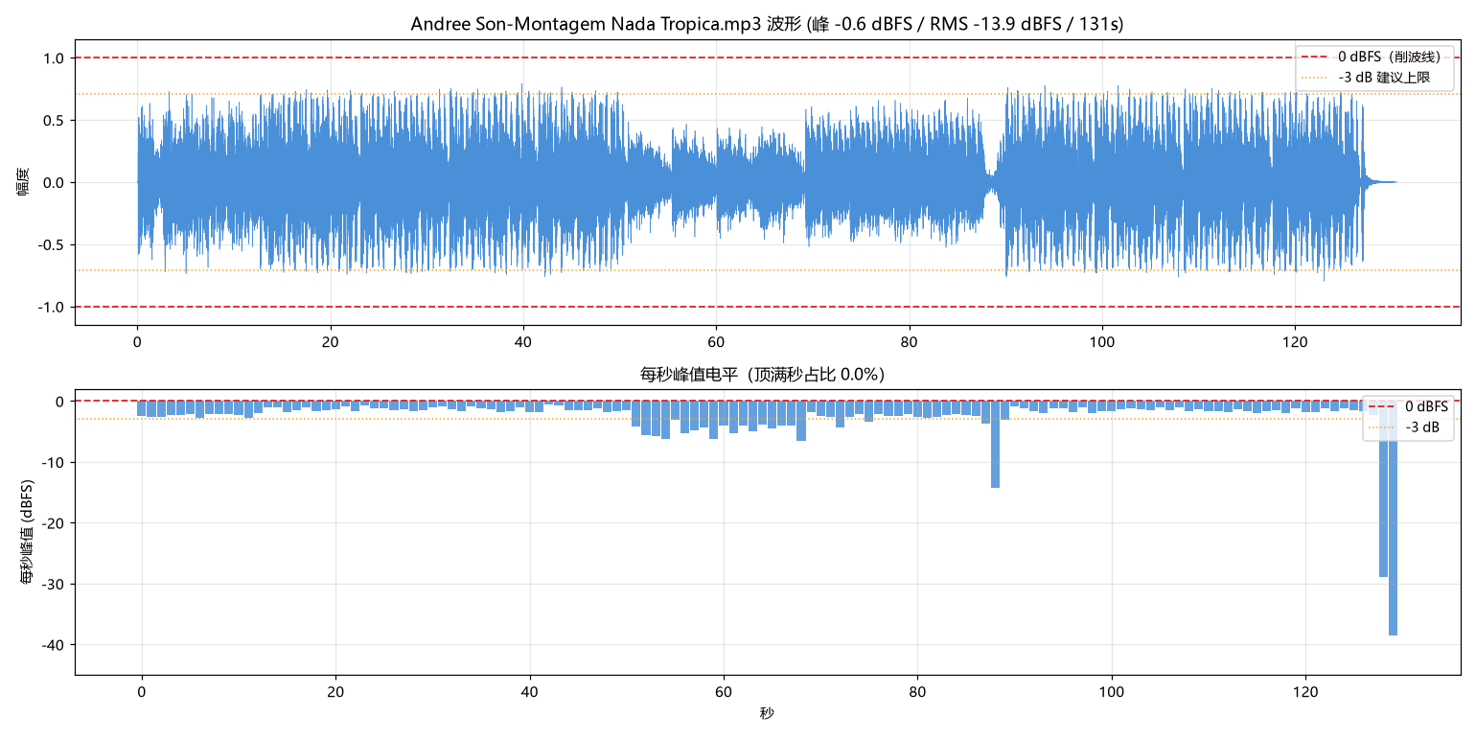
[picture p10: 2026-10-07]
docs/audio-guard/Andree-Son-Montagem-Nada-Tropica-波形分析.png

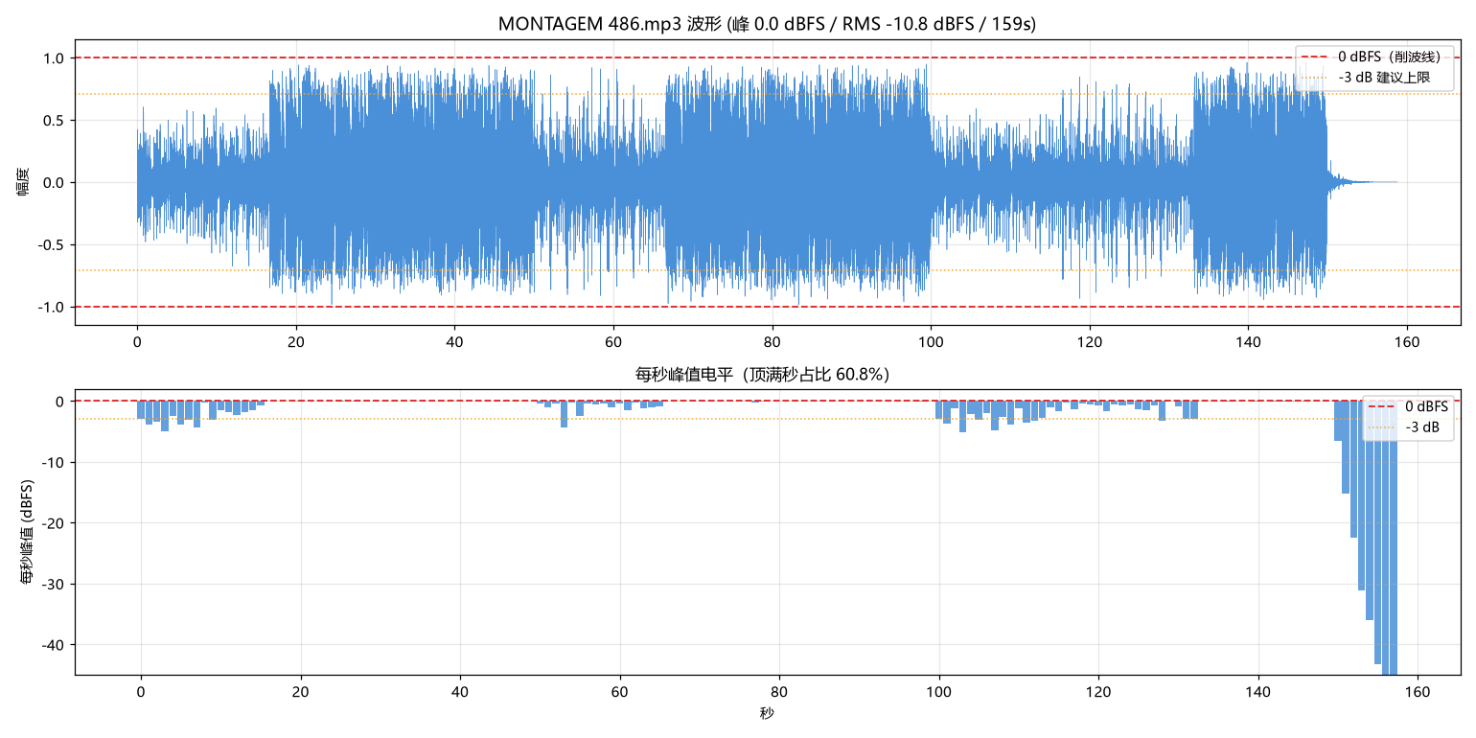
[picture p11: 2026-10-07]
docs/audio-guard/MONTAGEM-486-波形分析.png

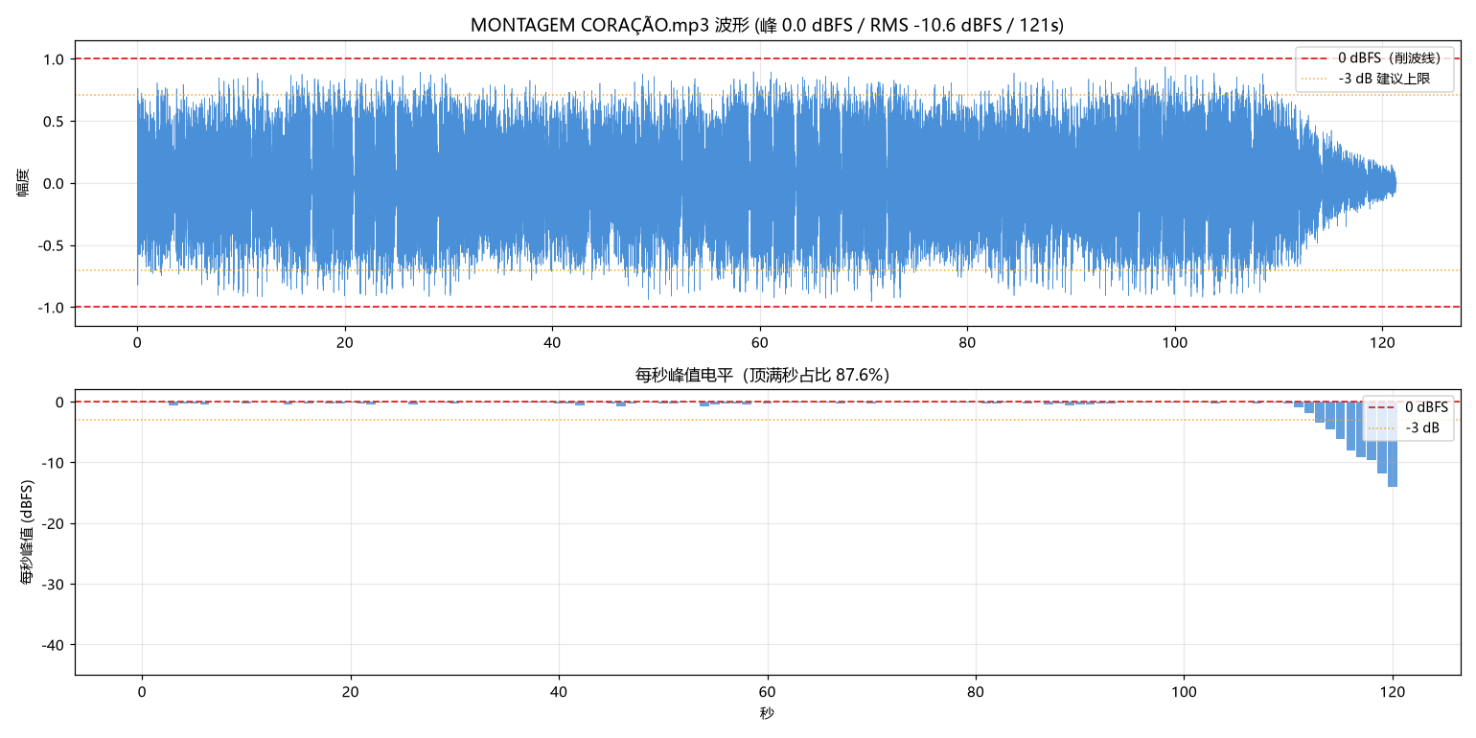
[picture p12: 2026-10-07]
docs/audio-guard/MONTAGEM-CORAÇÃO-波形分析.png

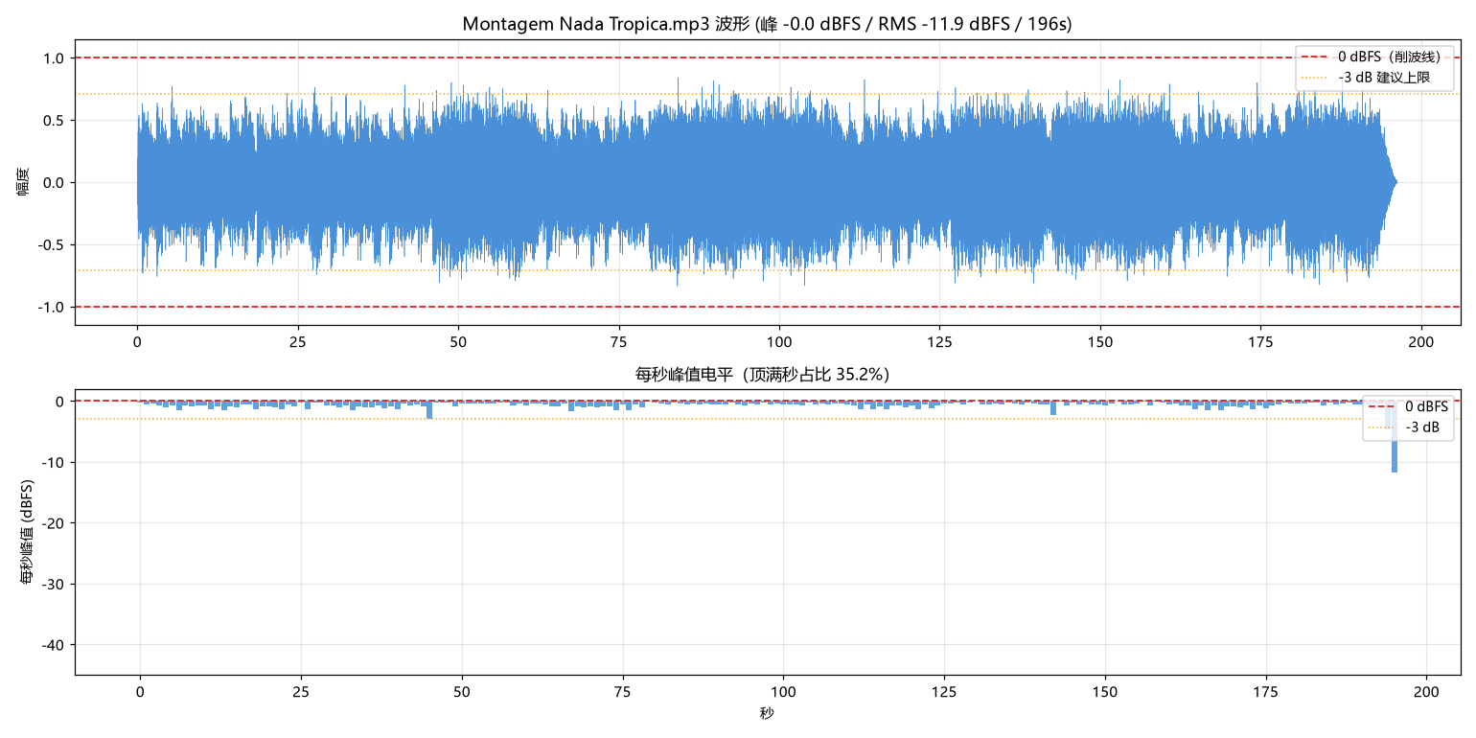
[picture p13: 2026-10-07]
docs/audio-guard/Montagem-Nada-Tropica-波形分析.png

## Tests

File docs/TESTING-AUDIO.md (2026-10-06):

# Memoria OS — 音频播放实测清单（真机）

> 配套固件：`build/memoria_os.bin`（0x212850，MP3/WAV/M4A 三路全绿）
> 配套素材：`sample/sample_test.mp3`（116KB，pygame 测试音频，MP3 通路）

## 0. 前置

1. 烧录：`idf.py -p <PORT> flash monitor`（或 esptool 直接写 0x0/0x8000/0x10000 三件套）
2. TF 卡：项目 `sdcard/` 目录**整目录拷到卡根**（含 `font/gb2312_16.bin`，GLM 线 P1.6）
3. 音频文件放 TF 卡 `/mem_fat/audio/`：
   - `sample_test.mp3`（必测，MP3 通路）
   - 任意 .m4a / .aac（用户提供；M4A 容器 + AAC 裸流均支持）

## 1. 实测步骤

| # | 操作 | 预期 |
|---|---|---|
| 1 | 开机进 MUSIC 模式 | 列出 `/mem_fat/audio` 下所有 .wav/.mp3/.m4a/.aac，中文界面正常（字库 TF 化后需方框为缺字占位，正常） |
| 2 | 选中 `sample_test.mp3` 播放 | 3~10 秒内出声（minimp3 软解），无爆音、无卡顿 |
| 3 | 方向键切歌（_next/_prev） | 上一首停止、下一首开始，无残留播放、无内存泄漏迹象（连续切 20 次不崩） |
| 4 | 音量 +/−（步进 10） | 音量渐变，0 静音、100 满量程（MAX98357A 3W 功放） |
| 5 | 播放中按停止键 | 立即无声，任务退出（`I2sAudio::stop()` 150ms 退避） |
| 6 | 退出 MUSIC 模式再进入 | 重新枚举正常，无"正在播放"假状态 |
| 7 | 播放 .m4a（若已提供） | Helix AAC 软解出声，双声道不丢数据（已按 `fi.outputSamps` 修复） |

## 2. 已知缺陷排查

| 现象 | 排查 |
|---|---|
| m4a 无声 | ① 文件是否真 AAC-in-MP4（非 AC3/其他）；② 采样率 8k~96k、声道 1/2（超范围代码直接拒播并打 log）；③ 首帧 log `aac first frame decode rc=<n>`：`rc<0` 为解析错误，`rc==0` 表示成功（earlephilhower 版返回错误码，0 不是失败） |
| mp3 无声 | 检查 minimp3 初始化 log；文件是否标准 MP3（VBR/CBR 均可） |
| 播放中爆音/破音 | 音量 >80 时 MAX98357A 削波属正常物理现象，调低音量 |
| 切歌后旧歌仍在响 | `I2sAudio::stop()` 未生效 → 检查任务 `playing` 标志与 150ms 退避是否被打断 |

## 3. 串口 log 关键字

- `WAV done. <bytes> bytes` — WAV 播放结束
- `MP3 done` — MP3 播放结束
- `AAC done` — AAC/M4A 播放结束
- `aac decode rc=<n> (skip)` — 单帧解码失败跳过（容忍）
- `aac decode rc=ERR_AAC_INDATA_UNDERFLOW` — 输入不足，视为流结束

## 4. 备注

- 模拟器无声是已知缺口（AAC/MP3 软解不在浏览器模拟范围），音频以真机为准。
- 录音（INMP441 RX）未实现，本轮只测播放。
- demo .m4a 待用户提供（本机外网 https 被环境掐断，下载失败）。

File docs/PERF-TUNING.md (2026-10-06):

# Memoria OS · 硬件潜力压榨清单（PERF-TUNING）

> 目标：把 ESP32-S3 N16R8（双核 240MHz + 8MB PSRAM + 16MB Flash）的性能全部用起来，
> 让系统配得上这批料。本文是路线图，按性价比排序，每项标注工作量/风险/状态。
> 定版日：2026-10-06（由豆包-2 起草，报桥后按窗口排期）

---

## 0. 现状基线（boot log 实录，2026-10-02 固件）

| 项 | 实测值 | 备注 |
|----|---|---|
| CPU 频率 | **160 MHz** | `cpu freq: 160000000 Hz`，双核但未充分利用 |
| 内部 RAM 可用 | ~146 KiB + 21 KiB + 32 KiB DRAM + 7 KiB RTC | 3FCC4D10 / 3FCE9710 / 3FCF0000 / 600FE000 |
| PSRAM | 8 MB（8192K，已入堆分配器） | 80MHz Octal |
| DMA 预留 | 32K 内部内存 | I2S/SPI DMA 描述符专用 |
| LCD 刷新 | SPI 80MHz，全屏 307200B ≈ 31ms（≈32fps） | 花屏则降 40/60MHz |
| 任务分布 | wifi driver task core=0、main_task CPU0 | 负载倾向挤在 core 0 |
| 电压 | brownout SEL_1（最低档，BOD 定案缓解） | 拉频率=拉电流，需错峰 |

---

## P0 · 白捡档（改配置，无新代码，无风险）

### P0-1 CPU 频率 160 → 240 MHz
- **现状**：160MHz，浪费 1/3 主频。
- **改法**：sdkconfig 设 `CONFIG_ESP_DEFAULT_CPU_FREQ_MHZ_240`。
- **收益**：全系统算力 +50%，解码/渲染/输入法全部受益。
- **风险**：电流略升，注意 BOD（配合背光错峰，见 §3 备注）。
- **状态**：✅ 已完成（2026-10-06，bin 5D086356 / v1.2.1）。当时回退系 boot 期射频电流误账（E47B83D9 实锤），boot 零射频架构落地后 240 重开，BOD SEL_7 全程在线，用户真机反复上电验收稳定。

### P0-2 关键模块编译优化
- **现状**：默认优化档。
- **改法**：对 `memoria_drivers`（解码）/`memoria_gfx`（渲染）单独 -O3 或开 LTO。
- **收益**：热循环 10~30%。
- **风险**：低；-O3 增大固件体积，注意 3MB factory 分区余量。
- **状态**：☐ 待窗口

---

## P1 · 双核真分工（写代码，中工程量，收益最大）

### P1-1 任务 pinning（xTaskCreatePinnedToCore）
- **现状**：重活与 UI 混跑，core 1 空转。
- **目标分工**：
  - **core 0**：MP3/AAC 解码、MJPG 视频解码、录音编码、WiFi/BLE 协议栈
  - **core 1**：UI 渲染、键盘扫描、输入法、shell、模式调度
- **改法**：解码/渲染相关 task 显式 pin；关键 task 提优先级。
- **收益**：解码与 UI 并行，卡顿大头直接消失。

### P1-2 音视频双缓冲流水线
- **现状**：串行"解一帧→显一帧"。
- **目标**：core 0 解帧 N+1 写双缓冲，core 1 显示帧 N → 帧率翻倍，解码时间被显示时间掩盖。
- **收益**：视频帧率接近翻倍；音乐解码零卡顿。
- **状态**：☐ 待窗口

---

## P2 · 内存分层（让 8MB PSRAM 干该干的活）

原则：**冷数据大块放 PSRAM，热数据小块留内部 RAM**。

| 数据 | 放哪 | 依据 |
|---|---|---|
| framebuffer（300KB）、字库、音频环形缓冲 | PSRAM | 大、低频访问 |
| ISR、键盘扫描、解码热循环、DMA 描述符 | 内部 RAM / IRAM_ATTR | 高频、怕延迟 |
| 常驻全局小变量 | 内部 RAM | 每次访问省 PSRAM 延迟 |

- **改法**：盘一遍 `memoria_gfx`/`memoria_kernel` 里高频路径是否误用 PSRAM 大块；热循环函数加 `IRAM_ATTR`。
- **风险**：IRAM 总量有限（S3 内部 IRAM ~512KB，但可用段有限），加多了编不过，需挑热点。
- **状态**：☐ 待窗口

---

## P3 · 外设频率试探（有 BOD 风险，需实测）

### P3-1 SPI LCD 80 → 120 MHz
- **改法**：`LCD_SPI_FREQ_HZ` 试 120MHz，花屏/雪花就退 100/80。
- **收益**：全屏刷新 31ms → ~20ms（≈50fps 上限）。
- **风险**：**拉频率=拉电流**，与 GLM BOD 课题直接相关——必须保持背光 init 半亮错峰，brownout 阈值不动（SEL_1）。
- **状态**：☐ 待窗口（真机实测项）

---

## P4 · SIMD（终极形态，后期做）

- **能力**：ESP32-S3 128-bit SIMD（PIE 指令集），帧拷贝/RGB565 填充/字库渲染/解码数学循环可向量化。
- **参考**：ESP-DL 库即基于此跑 AI；手写汇编或 intrinsics。
- **收益**：密集循环 2~4×。
- **成本**：工程量最大、可维护性差，最后做。
- **状态**：☐ 远期

---

## 执行顺序建议

1. **P0-1 CPU 240MHz**（一行配置）→ 立即可见
2. **P1-1 双核分工**（核心工程）→ 卡顿大头
3. **P2 内存分层 + P1-2 流水线** → 帧率/流畅度翻倍
4. **P3 LCD 120MHz 实测** → 需要真机 + BOD 监控
5. **P4 SIMD** → 压轴

> 里程碑：P0+P1 完成后跑一遍 32fps 动画 + MP3 播放 + 输入法同时开，观感应显著顺滑。

## 风险登记

- **BOD 欠压**：所有频率/背光改动必须沿用 GLM 定案的错峰策略（power.cpp init 半亮 + brownout SEL_1），实测时串口盯 `BOD: Brownout detector` 日志。
- **固件体积**：-O3/LTO 可能撑大 3MB factory 分区，注意 `idf.py size`。
- **IRAM 溢出**：IRAM_ATTR 加多了编译报错，只挑热点。

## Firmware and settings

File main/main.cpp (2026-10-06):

/**
 * @file main.cpp
 * @brief Memoria OS：extern "C" app_main() 入口
 *
 * 唯一职责：调用 Kernel::init() 完成启动序列，然后进入 main_loop() 永不返回。
 * 串口 REPL 后台任务提供 shell 命令行（调试口 + rec 录音入口）。
 */

extern "C" {
#include <freertos/FreeRTOS.h>
#include <freertos/task.h>
}

#include "kernel.hpp"
#include "shell.hpp"

namespace {

/* 串口 REPL：最低优先级，getchar 阻塞读让出 CPU，仅调试与录音入口 */
void shell_task(void*) {
    static memoria::shell::Shell s_shell;
    s_shell.menu();   /* 永不返回 */
}

} /* namespace */

extern "C" void app_main() {
    using namespace memoria::kernel;

    Kernel* k = Kernel::instance();

    /* 启动内核（包含所有驱动/FS/窗口/应用的初始化） */
    esp_err_t ret = k->init();
    if (ret != ESP_OK) {
        /* 启动失败：串口 + 红屏错误码（LCD 未就绪时仅串口），死循环保持现场 */
        k->show_boot_failure(ret);
        for (;;) { vTaskDelay(pdMS_TO_TICKS(1000)); }
    }

    /* 串口 shell 后台任务（核 0，避免抢占主循环所在核） */
    xTaskCreatePinnedToCore(shell_task, "shell", 4096, nullptr, 1, nullptr, 0);

    /* 进入主循环（永不返回） */
    k->main_loop();
}

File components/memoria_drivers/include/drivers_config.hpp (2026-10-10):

/**
 * @file drivers_config.hpp
 * @brief Memoria OS 硬件引脚唯一真实来源
 *
 * 所有驱动/应用必须从此文件读取引脚号/分辨率/时钟频率。
 * 禁止在其他文件里硬编码 GPIO 数字。
 *
 * 硬件：ESP32-S3-WROOM-2 N16R8
 *   16MB Flash (Octal 80MHz) + 8MB PSRAM (Octal 80MHz)
 *   1× ILI9488 SPI 屏幕（480×320 RGB565，无触摸）
 *   1× KY-023 模拟摇杆（X/Y 双 ADC + 按下按钮）
 *   1× MAX98357A I2S 功放 + 3W 喇叭
 *   1× SPI TF 卡（FAT32）
 *   电池：3.7V LiPo + TP4056；ADC 分压采样
 *   WiFi + BLE 内部射频
 */

#ifndef MEMORIA_DRIVERS_CONFIG_HPP
#define MEMORIA_DRIVERS_CONFIG_HPP
#pragma once

#include <cstdint>

namespace memoria {
namespace drivers {

/* ============================================================
 *  全局屏幕分辨率 & 色彩
 *  默认面板：ILI9488 3.5寸 480×320（横屏，RGB565）
 *  如需换回 ILI9341 320×240：把 PANEL_ILI9488 置 false 并恢复 320/240
 * ============================================================ */
static constexpr bool     PANEL_ILI9488 = true;
static constexpr uint16_t SCREEN_W      = 480;
static constexpr uint16_t SCREEN_H      = 320;
static constexpr uint16_t COLOR_BLACK    = 0x0000;
static constexpr uint16_t COLOR_WHITE    = 0xFFFF;
static constexpr uint16_t COLOR_SOFT_ROSE= 0xF3B6;   /* RGB565 243/182/199 */
static constexpr uint16_t COLOR_DEEP_BLUE = 0x1C4F;
static constexpr uint16_t COLOR_LIGHT_GRAY= 0xBDF7;
static constexpr uint16_t COLOR_DARK_GRAY = 0x4208;
static constexpr uint16_t COLOR_RED       = 0xF800;
static constexpr uint16_t COLOR_GREEN      = 0x07E0;
static constexpr uint16_t COLOR_YELLOW    = 0xFFE0;

/* ============================================================
 *  SPI 共用总线 (SPI2_HOST)
 * ============================================================ */
static constexpr int SPI_BUS_HOST = 2;    /* SPI2_HOST */
static constexpr int SPI_SCLK_GPIO = 12;
static constexpr int SPI_MOSI_GPIO = 11;
static constexpr int SPI_MISO_GPIO = 13; /* 屏幕/SD 都是半双工，不需要 MISO 时悬空也安全 */
static constexpr int SPI_BUS_FREQ_HZ = 26000000;  /* 26MHz，SD 卡 SPI 上限 25MHz，总线保持保守 */
static constexpr int LCD_SPI_FREQ_HZ = 80000000;  /* LCD 独立 80MHz：SPI 每设备时钟独立生效，SD 仍 20MHz 不受影响。
                                                     全屏 307200B 传输 94→31ms（≈32fps）。真机花屏则降至 40/60MHz */

/* ============================================================
 *  ILI9341 屏幕（仅一块，共用 SPI）
 * ============================================================ */
static constexpr int LCD_CS_GPIO   = 10;
static constexpr int LCD_DC_GPIO   = 9;
static constexpr int LCD_RST_GPIO  = 8;
static constexpr int LCD_BLK_GPIO  = 14;   /* LEDC PWM 背光 */

/* ============================================================
 *  KY-023 模拟摇杆
 *  2026-10-01 引脚迁移（GPIO-ALLOC §2）：
 *  X 36→7 (ADC1_CH6)、Y 37→5 (ADC1_CH4)。
 *  原因：N16R8 开启 Octal PSRAM 后 GPIO33~37 被内部占用，
 *  且 ADC 仅 GPIO1~10 (ADC1) 可用，ADC2 与 WiFi 冲突禁用。
 * ============================================================ */
static constexpr int JOY_X_ADC_CHANNEL = 6;   /* GPIO7  ADC1_CH6 */
static constexpr int JOY_X_GPIO        = 7;
static constexpr int JOY_Y_ADC_CHANNEL = 4;   /* GPIO5  ADC1_CH4 */
static constexpr int JOY_Y_GPIO        = 5;
static constexpr int JOY_BTN_GPIO      = 38;  /* 摇杆按下按钮 */

/* ============================================================
 *  SD 卡 SPI（共用 SPI 总线）
 * ============================================================ */
static constexpr int SD_CS_GPIO = 17;  /* 2026-10-01 迁移：5→17（GPIO-ALLOC §2） */

/* ============================================================
 *  MAX98357A I2S 功放
 * ============================================================ */
static constexpr int I2S_PORT      = 0;
static constexpr int I2S_BCLK_GPIO = 18;  /* 2026-10-01 迁移：4→18 */
static constexpr int I2S_WS_GPIO   = 21;  /* 2026-10-01 迁移：3→21 */
static constexpr int I2S_DOUT_GPIO = 15;  /* 2026-10-01 迁移：2→15 */

/* ============================================================
 *  INMP441 数字麦克风（I2S RX）
 *  BCLK/WS 与功放共用（同 I2S0 端口，RX 只加数据脚）
 *  INMP441 数据在 WS 低电平有效（左声道），24-bit 左对齐
 *  SD 脚 GPIO16（GPIO-ALLOC/WIRING 预留池转正；45 是 strapping 脚弃用）
 * ============================================================ */
static constexpr int MIC_SD_GPIO   = 16;  /* GPIO16 数据脚（账本预留转已用） */

/* ============================================================
 *  电池 ADC 采样
 *  分压：LiPo 最高 4.2V → ADC 最大 1.2V
 *  分压电阻 R1=100K (接电池+), R2=100K (接GND)
 *  VADC = VBAT * R2/(R1+R2) = VBAT/2
 *  实际电池电压 = VADC * 2
 * ============================================================ */
static constexpr int BATTERY_ADC_CHANNEL = 3;  /* GPIO4  ADC1_CH3（S3 通道映射） */
static constexpr int BATTERY_GPIO        = 4;  /* 2026-10-01 迁移：39→4（GPIO39 无 ADC） */
static constexpr float BATTERY_DIV_RATIO  = 2.0f;
static constexpr float BATTERY_VOLTAGE_FULL   = 4.2f;
static constexpr float BATTERY_VOLTAGE_EMPTY  = 3.3f;
static constexpr float BATTERY_LOW_WARN_VOL   = 3.45f;   /* 15% 左右 */
static constexpr float BATTERY_LOW_CRIT_VOL   = 3.35f;   /* 5% 左右 */
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

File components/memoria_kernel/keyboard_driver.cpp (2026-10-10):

/* ============================================================
 * @file keyboard_driver.cpp
 * @brief 矩阵键盘扫描驱动（2× MCP23017 I2C 扩展器）
 *
 * 扫描协议：
 *   1) 行输出：对 MCP #1 的 GPA0-5 逐行拉低（其余行高）
 *   2) 列读取：MCP #1 GPB0-3（C0-C3）+ MCP #2 GPA0-5（C4-C9）
 *   3) 低电平 = 按下；状态变化后按 20ms 消抖窗确认（非阻塞，
 *      时间戳状态机，扫描轮间自然间隔累积，不阻塞扫描任务）
 *
 * 寄存器（MCP23017 datasheet）：
 *   IODIRA/B 0x00/0x01  方向（1=输入）
 *   GPPUA/B  0x0C/0x0D  内部上拉（1=使能）
 *   GPIOA/B  0x12/0x13  读输入电平 / 写输出电平
 * ============================================================ */
#include "keyboard_driver.hpp"
#include "keyboard_keymap.hpp"
#include "drivers_config.hpp"

#include "driver/i2c_master.h"
#include "freertos/FreeRTOS.h"
#include "freertos/task.h"
#include "esp_log.h"

#include <cstring>

namespace memoria::input {

namespace {

const char* TAG = "kbd_drv";

/* MCP23017 寄存器地址 */
constexpr uint8_t REG_IODIRA = 0x00;
constexpr uint8_t REG_IODIRB = 0x01;
constexpr uint8_t REG_GPPUA  = 0x0C;
constexpr uint8_t REG_GPPUB  = 0x0D;
constexpr uint8_t REG_GPIOA  = 0x12;
constexpr uint8_t REG_GPIOB  = 0x13;

/* 扫描参数 */
constexpr size_t MAX_ROWS = KEY_ROWS;   /* 6 */
constexpr size_t MAX_COLS = KEY_COLS;   /* 10 */
constexpr uint8_t ROW_MASK   = 0x3F;    /* #1 GPA0-5 = 行 */
constexpr uint8_t COL_A_MASK = 0x0F;    /* #1 GPB0-3 = C0-C3 */
constexpr uint8_t COL_B_MASK = 0x3F;    /* #2 GPA0-5 = C4-C9 */

/* 消抖窗：状态变化后须保持 DEBOUNCE_MS 才确认（与旧版 20ms 阻塞等效） */
constexpr uint32_t DEBOUNCE_MS = 20;

i2c_master_bus_handle_t s_bus = nullptr;
i2c_master_dev_handle_t s_mcp_rows = nullptr;   /* 0x20：行 + C0-C3 */
i2c_master_dev_handle_t s_mcp_cols = nullptr;   /* 0x21：C4-C9 */
KeyCallback s_cb = nullptr;
bool s_prev[MAX_ROWS][MAX_COLS] = {{false}};
/* 非阻塞消抖状态：pending_active 置位时 deadline 为确认时刻，
 * 到期且状态仍保持目标值才发事件；无符号回绕安全（FreeRTOS 惯用） */
bool s_pending_active[MAX_ROWS][MAX_COLS];
TickType_t s_pending_deadline[MAX_ROWS][MAX_COLS];
bool s_pending_val[MAX_ROWS][MAX_COLS];

esp_err_t mcp_write(i2c_master_dev_handle_t dev, uint8_t reg, uint8_t val) {
    uint8_t tx[2] = {reg, val};
    return i2c_master_transmit(dev, tx, sizeof(tx), pdMS_TO_TICKS(50));
}

esp_err_t mcp_read(i2c_master_dev_handle_t dev, uint8_t reg, uint8_t& val) {
    return i2c_master_transmit_receive(dev, &reg, 1, &val, 1, pdMS_TO_TICKS(50));
}

/* 驱动一行：拉低 row 位，其余行保持高 */
esp_err_t drive_row(size_t r) {
    uint8_t gpioa = static_cast<uint8_t>(~((1u << r) & ROW_MASK));  /* 选中行 0，其余 1 */
    return mcp_write(s_mcp_rows, REG_GPIOA, gpioa);
}

/* 读 10 位列状态：bit0-3=C0-C3, bit4-9=C4-C9；低电平 = 按下
 * I2C 失败返回 bit15=1 标记（成功值域仅 bit0-9，不冲突），调用方保持原状态不产事件 */
uint16_t read_cols() {
    uint8_t a = 0, b = 0;
    if (mcp_read(s_mcp_rows, REG_GPIOB, a) != ESP_OK) return 0x8000;
    if (mcp_read(s_mcp_cols, REG_GPIOA, b) != ESP_OK) return 0x8000;
    return (uint16_t)((a & COL_A_MASK) | ((b & COL_B_MASK) << 4));
}

void emit(size_t r, size_t c, bool pressed) {
    if (!s_cb) return;
    RawKeyEvent evt;
    evt.row = static_cast<uint8_t>(r);
    evt.col = static_cast<uint8_t>(c);
    evt.pressed = pressed;
    s_cb(evt);
}

void scan_task(void*) {
    for (;;) {
        for (size_t r = 0; r < MAX_ROWS; ++r) {
            if (drive_row(r) != ESP_OK) { vTaskDelay(pdMS_TO_TICKS(10)); break; }
            vTaskDelay(pdMS_TO_TICKS(1));               /* 电平稳定 */
            const uint16_t cols = read_cols();
            if (cols & 0x8000) {                        /* I2C 失败：保持按键状态，跳过本行 */
                vTaskDelay(pdMS_TO_TICKS(10));
                break;
            }
            const TickType_t now = xTaskGetTickCount();
            for (size_t c = 0; c < MAX_COLS; ++c) {
                const bool now_pressed = ((cols >> c) & 1u) == 0;   /* 低电平 = 按下 */
                if (now_pressed == s_prev[r][c]) {
                    /* 状态回到原值：抖动结束，取消本键 pending */
                    s_pending_active[r][c] = false;
                    continue;
                }
                if (!s_pending_active[r][c]) {
                    /* 首次变化：记确认时刻与目标状态，不阻塞，等扫描轮自然确认 */
                    s_pending_active[r][c] = true;
                    s_pending_deadline[r][c] = now + pdMS_TO_TICKS(DEBOUNCE_MS);
                    s_pending_val[r][c] = now_pressed;
                    continue;
                }
                /* 消抖窗已到且状态仍保持目标值 → 确认；否则维持 pending 等下一轮 */
                if ((TickType_t)(now - s_pending_deadline[r][c]) < 0x80000000u
                    && now_pressed == s_pending_val[r][c]) {
                    s_prev[r][c] = now_pressed;
                    emit(r, c, now_pressed);
                    s_pending_active[r][c] = false;
                }
            }
            drive_row(r);   /* 恢复本行高（下轮由 drive_row 重新拉低） */
        }
    }
}

} /* namespace */

void keyboard_init(KeyCallback cb) {
    s_cb = cb;
    std::memset(s_prev, 0, sizeof(s_prev));
    std::memset(s_pending_active, 0, sizeof(s_pending_active));

    /* I2C 总线（唯一来源：drivers_config.hpp） */
    i2c_master_bus_config_t bus_cfg = {};
    bus_cfg.i2c_port     = static_cast<i2c_port_num_t>(drivers::KBD_I2C_PORT);
    bus_cfg.sda_io_num   = static_cast<gpio_num_t>(drivers::KBD_I2C_SDA);
    bus_cfg.scl_io_num   = static_cast<gpio_num_t>(drivers::KBD_I2C_SCL);
    bus_cfg.clk_source   = I2C_CLK_SRC_DEFAULT;
    bus_cfg.glitch_ignore_cnt = 7;
    /* 纯同步用法（i2c_master_transmit/_receive）：队列深度必须为 0。
     * >0 会启用 IDF "experimental" 异步队列机制，ISR 取队列事务时
     * ops/data 可为毒值 → LoadProhibited panic（0xeadb8f6a 实证） */
    bus_cfg.trans_queue_depth = 0;
    bus_cfg.flags.enable_internal_pullup = true;
    if (i2c_new_master_bus(&bus_cfg, &s_bus) != ESP_OK) {
        ESP_LOGE(TAG, "i2c bus init failed (SDA=%d SCL=%d)", drivers::KBD_I2C_SDA, drivers::KBD_I2C_SCL);
        return;
    }

    i2c_device_config_t dev_cfg = {};
    dev_cfg.dev_addr_length = I2C_ADDR_BIT_LEN_7;
    dev_cfg.scl_speed_hz    = drivers::KBD_I2C_FREQ_HZ;

    dev_cfg.device_address = drivers::KBD_MCP_ROWS;
    if (i2c_master_bus_add_device(s_bus, &dev_cfg, &s_mcp_rows) != ESP_OK) {
        ESP_LOGE(TAG, "mcp 0x%02X add failed", drivers::KBD_MCP_ROWS);
        return;
    }
    dev_cfg.device_address = drivers::KBD_MCP_COLS;
    if (i2c_master_bus_add_device(s_bus, &dev_cfg, &s_mcp_cols) != ESP_OK) {
        ESP_LOGE(TAG, "mcp 0x%02X add failed", drivers::KBD_MCP_COLS);
        return;
    }

    /* #1：GPA 全输出（行），GPB 全输入；C0-C3 上拉 */
    esp_err_t e = ESP_OK;
    e |= mcp_write(s_mcp_rows, REG_IODIRA, 0x00);
    e |= mcp_write(s_mcp_rows, REG_IODIRB, 0xFF);
    e |= mcp_write(s_mcp_rows, REG_GPPUB,  COL_A_MASK);
    e |= mcp_write(s_mcp_rows, REG_GPIOA,  0xFF);    /* 行默认全高 */

    /* #2：GPA 全输入（列 C4-C9 上拉） */
    e |= mcp_write(s_mcp_cols, REG_IODIRA, 0xFF);
    e |= mcp_write(s_mcp_cols, REG_GPPUA,  COL_B_MASK);
    if (e != ESP_OK) {
        ESP_LOGE(TAG, "mcp23017 init write failed: 0x%x", e);
        return;
    }

    ESP_LOGI(TAG, "2x MCP23017 ready: rows@0x%02X cols@0x%02X (%dx%d)",
             drivers::KBD_MCP_ROWS, drivers::KBD_MCP_COLS, (int)MAX_ROWS, (int)MAX_COLS);
}
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

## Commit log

2026-10-02 Memoria OS 1.0.0: initial open-source release
    [partitions.csv, 键盘按键布局表.xlsx]
2026-10-02 sync: audio samples, media support baseline 0x1DCE00
2026-10-02 sync final tree: pkg media support, spi 80mhz, tools
2026-10-02 sync final tree v7: window/sdcard/kernel, store link, app samples
2026-10-03 sync v9: BASIC language guide, wiring doc, wiring & 3D design assets
2026-10-06 release: v1.2.1 — memoria_math 解方程组件 + RND esp_random 硬件真随机 + I2C 键盘总线 trans_queue_depth panic 修复 + CPU 240MHz + CALC 键盘扩展
    [keyboard_driver.cpp]
2026-10-06 release: v1.2.1 full snapshot — memoria_math 解方程组件 + RND esp_random 硬件真随机 + I2C trans_queue_depth panic 修复 + CPU 240MHz + CALC 键盘扩展（含 v1.2.0 双核迁核/系统监控全量内容）
    [partitions.csv]
2026-10-07 release: v1.3.0 full snapshot — GUI 控件语句集（bkey/lbl/llbl/lbld/img/after/style） + store MBND 应用包解包安装 + 商店 .msp-only 政策 + 扩展语句函数式写法规范化 wait(150) + shell #86 误退出 panic 修复 + README/PROJECT-STATUS v1.3.0 重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
    [basic_interpreter.hpp]
2026-10-07 v1.4.0: SETUP 网络管理界面 + shell wifi connect + 模拟器音频同步 + AudioGuard 归档
    [partitions.csv]
2026-11-07 v1.6.0: 硬盘损毁后重建基线 + CHRG42/SDMMC + 构建可复现
    - 版本 1.4.0 -> 1.6.0：v1.5.0 源码从未推送、随盘丢失，不补号，自此重新起算
    - 引脚：CHRG_DET 49->42；新增 SDMMC CLK40/CMD39/D0 41（1-bit 大卡座）
    - 驱动：SdCard 新增 init_sdmmc()，SDMMC 优先、失败回落 SPI
    - shell：新增 sd mmc 命令；info 版本串改用 MEMORIA_OS_VERSION 宏
    - 构建：sdkconfig.defaults 补 CONFIG_FREERTOS_USE_TRACE_FACILITY=y，
    修复换机后 uxTaskGetSystemState 链接失败（shell sys 命令依赖）
    - 文档：新增 docs/CHANGELOG.md；WIRING/WIRING-MAP 同步新脚；旧快照归档 archive/snapshots
    - 清理：删除 26 条带引号历史垃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
2026-11-07 docs: v1.6.0 状态快照 + OTA 分发包 + README 同步
    - docs/PROJECT-STATUS.md 重写为 2026-11-07 v1.6.0 口径（多线速览/已闭环 23 条/待办 11 条/产物/风险）
    - docs/HEALTH-REPORT.md 追加 11-07 复查：技术债 4-3 电源管理、4-4 SD 大卡已闭环，新增显示与键盘两件错料的硬卡点
    - docs/CHANGELOG.md 补构建链路修复、稳定性处理、验证数据（1261 步, 1,877,248 B, SHA256 97FB4F04…）
    - README：版本串 v1.3.0→v1.6.0，引脚表补 CHRG42 / SDMMC 39/40/41 / AMP_EN47 / SUBMOS48 / WAKEUP2，补"换机器重建必读"的 FreeRTOS trace facility 说明
    - firmware/memoria_os_1.6.0.bin 随仓（与构建产物逐字节一致）
2026-11-07 docs: 远端同步闭环，推送链路固化为 tools/push_api.py
    - PROJECT-STATUS：远端仓库与 OTA 标记为已同步，引脚改为 26 脚无剩余，风险章重写为「推送只能走 API」并说明哈希差异
    - 待办 #1（补凭据推 v1.6.0）关闭
    - 新增 tools/push_api.py：走 api.github.com Git Data API，token 只读环境变量 GH_PAT，按 tree 指纹定位基点逐提交重放，每次校验 tree 一致
2026-11-07 docs: 修正推送说明表述
2026-11-07 docs: 重建核对笔记（证据分级 + SDMMC 无自动回退 + 丢失产物清单）
2026-11-07 docs: 修正键盘二极管极性（阳极接列线），补旧 KiCad 图 6 处引脚错误
2026-11-07 feat: 复原 10-11 批 GUI 改动（字模缩放/多列表/图标/彩蛋），版本 1.6.1
2026-11-07 fix(push_api): rename/删除时给旧路径补 sha:null
2026-11-07 docs: 状态/README 同步 1.6.1（固件大小、OTA 清单、已闭环表补 #24）
2026-11-07 docs: 归档 zip 26 项核验完毕，图纸与 STL 全在 design/
    26 项全部解码还原并逐字节比对：22 项相同、3 项纯文本相同、1 项采购清单仓内版更新。确认 design/ 与 simulator/ 资产未丢失。
2026-11-07 docs: 修正归档核验统计为 21/4/1
2026-11-07 feat: v1.6.2 开机 SD 双通道 + SUBMOS 注释纠正
    kernel.cpp 开机先试 SDMMC 大卡座、失败回落 SPI，日志打通道名；drivers_config.hpp SUBMOS 注释与 AO3401 P-MOS 极性对齐（低电平供电），GPIO48 逻辑未动。bin 1,884,432 B / 0x1CC110。
2026-11-07 docs: 新增第十一节，OTA 分区缺 otadata/ota_1 与两套修法
2026-11-08 firmware: v1.6.3 — 启动卡改屏幕 TF 卡槽（SPI /mem_fat），SD 大卡座降为扩展盘（SDMMC /sd_ext）
2026-11-08 firmware: v1.6.4 — 分区表改 ota_0 + ota_1 双槽（删 factory、补 otadata、开 app rollback）
2026-11-08 firmware+kernel: v1.6.4 补 OTA 自校验，新槽首次启动通过才标记有效
2026-11-08 chore: CI + 结构校验 + 版本奇偶规则（奇=beta 偶=stable）
2026-11-08 docs: 记录 CI 首次运行结果（两 job 全绿）
2026-11-08 docs: 新增变砖救援手册 docs/RECOVERY.md，README 加急救一节
2026-11-08 feat: v1.6.5 用户数据全部搬 TF 卡，flash 只留系统
2026-11-08 docs: 救援手册补口径，卡上 sys/ 才是用户数据权威源
2026-11-08 feat: v1.6.7 OTA 三处缺口补齐（证书校验 / 镜像身份校验 / 盖章后移到进桌面 30 秒）
2026-11-08 OTA: 下载全程 sha256 校验，版本比较抽成可测纯 C++（v1.6.9）
2026-11-08 release: 1.6.11 — 裸核心板启动（电池分压探测）+ 串口 fw_check/fw_update
